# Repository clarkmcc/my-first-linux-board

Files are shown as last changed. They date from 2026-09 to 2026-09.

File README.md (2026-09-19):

# my-first-linux-board

`my-first-linux-board` is a small F1C200S Linux board built around removable microSD storage, USB-C power and USB device data, a 3.3 V UART console, and power/status LEDs. This repository contains the exact KiCad design used for the assembled board, the working Buildroot firmware source, the final JLCPCB fabrication package, and purchasing files.

The assembled board boots U-Boot 2026.01 and Linux 6.19.14 into a minimal BusyBox system. Both boot stages identify it as `Clark's Board`.

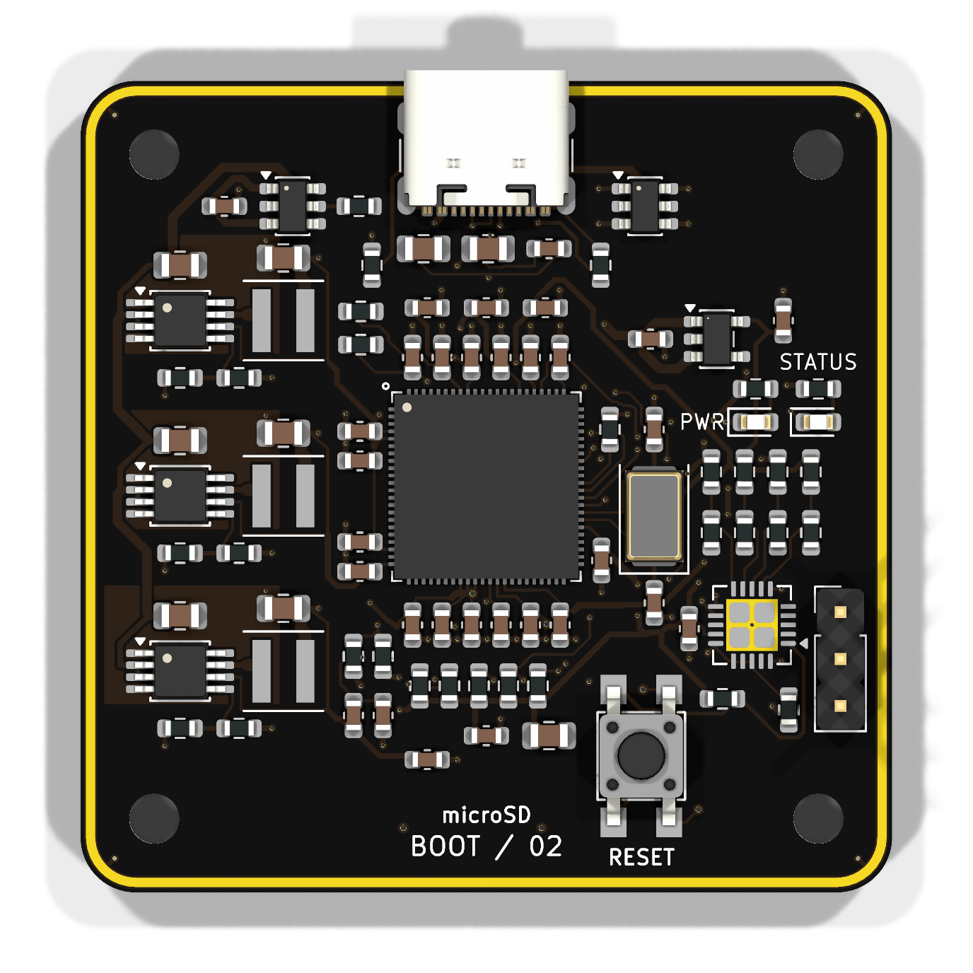
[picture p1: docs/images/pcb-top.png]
Top PCB render


## Hardware

| Item | Final design |
|---|---|
| Processor | Allwinner F1C200S with 64 MiB integrated DDR1 |
| Board | 44 × 44 mm, four copper layers, R3 rounded corners |
| Power input | USB-C, 5 V, TPS2553 current-limited input switch |
| Rails | Three TPS62160 bucks for core, DDR, and I/O; TLV75528 analog LDO |
| Storage | Bottom-mounted microSD socket |
| Console | UART0 on a three-pin 3.3 V header: GND, TX, RX |
| USB | Native USB peripheral connection over USB-C |
| Indicators | Fixed power LED and PC0-controlled active-low status LED |
| Assembly | Components on top except the bottom microSD socket; through-hole UART header |
| Finish used | Black solder mask, white silkscreen, ENIG |

Open [hardware/boot-console.kicad_pro](hardware/boot-console.kicad_pro) in KiCad 10. The [BOM](hardware/docs/BOM.md), [pinout](hardware/docs/PINOUT.md), and [component-purpose guide](hardware/docs/COMPONENT-PURPOSE.md) describe the final circuit.

The [schematic PDF](docs/schematic.pdf) and [combined copper-layer image](docs/images/all-copper-layers.png) are convenient read-only views of the same final design.

## Firmware

The firmware directory is a Buildroot external tree. On macOS or another Docker host:

```sh
cd firmware
./build-container.sh
```

The complete card image is generated at:

```text
firmware/output/images/sdcard.img
```

The proven board configuration uses one-bit microSD transfers at 12.5 MHz. The physical board has four data traces, but Linux produced data errors in four-bit/25 MHz mode on the first assembly; the conservative setting boots reliably and is therefore the canonical configuration.

UART0 is 115200 baud, 8 data bits, no parity, and one stop bit. Linux also
creates a composite USB device with a CDC ACM console and a CDC ECM Ethernet
link. The board is `192.168.7.2/24`; its small DHCP server assigns the attached
host an address without advertising a default route or DNS server. On macOS,
the gadget can enumerate before Network Settings creates a service. Find the
interface whose MAC address is `02:00:00:00:07:01`, assign the host side
`192.168.7.1` for immediate access, and ask macOS to detect the new hardware:

```sh
iface=$(for interface in $(ifconfig -l); do
  ifconfig "$interface" | grep -q 'ether 02:00:00:00:07:01' && echo "$interface"
done)
sudo ifconfig "$iface" inet 192.168.7.1 netmask 255.255.255.0 up
sudo networksetup -detectnewhardware
```

This address lasts until the interface is removed or reconfigured. After
`networksetup -detectnewhardware` creates the service, give it the persistent
static address used by this direct link. The service on the tested Mac is named
`Clark's Board Console + Ethernet`:

```sh
sudo networksetup -setmanual "Clark's Board Console + Ethernet" \
  192.168.7.1 255.255.255.0 0.0.0.0
```

If macOS uses a different service name, find it with
`networksetup -listallnetworkservices` and substitute that name. DHCP did not
activate this ECM link reliably, so keep the host address static.

Prometheus metrics are the only HTTP resource. Scrape them with:

```sh
curl http://192.168.7.2/cgi-bin/metrics
```

The endpoint uses the Prometheus 0.0.4 text format and reports board identity,
time, CPU, load, memory, VM, pressure, filesystem, microSD, network, socket,
entropy, LED, service, USB gadget, and available thermal, CPU-frequency, and
watchdog data. The root URL and every other HTTP path intentionally return 404.

SSH is available as `root` with a blank password:

```sh
ssh root@192.168.7.2
```

This passwordless access is intended for a directly attached development
cable. The first boot stores a generated SSH host key on the FAT boot partition
so the host fingerprint remains stable while the read-only root stays unchanged.

The status LED appears at:

```text
/sys/class/leds/boot-console:green:status
```

It uses the CPU `activity` trigger by default. Manual control:

```sh
LED=/sys/class/leds/boot-console:green:status
echo none > "$LED/trigger"
echo 1 > "$LED/brightness"
echo 0 > "$LED/brightness"
```

See [firmware/README.md](firmware/README.md) for build details and [firmware/docs/BRINGUP.md](firmware/docs/BRINGUP.md) for bench bring-up.

## Manufacturing and purchasing

- [fabrication/clarks-board-JLCPCB-gerbers.zip](fabrication/clarks-board-JLCPCB-gerbers.zip) is the exact bare-board package used for the final revision.
- [fabrication/assembly/clarks-board-JLCPCB-BOM.csv](fabrication/assembly/clarks-board-JLCPCB-BOM.csv) and [fabrication/assembly/clarks-board-JLCPCB-CPL.csv](fabrication/assembly/clarks-board-JLCPCB-CPL.csv) are formatted for JLCPCB assembly upload.
- [procurement/DigiKey-order.csv](procurement/DigiKey-order.csv) and [procurement/LCSC-order.csv](procurement/LCSC-order.csv) contain the final supplier split used during sourcing.
- [hardware/assembly/ibom.html](hardware/assembly/ibom.html) is an interactive assembly view.

The fabrication package retains the routed board exactly. USB impedance was not matched to a specific JLCPCB controlled-impedance stackup, so select and verify a stackup before changing USB routing or ordering a controlled-impedance revision.

## Validation status

- The assembled board reaches a Linux login prompt over UART.
- The status LED works through the Linux LED subsystem after correcting duplicate PC0 pin ownership.
- KiCad ERC and DRC pass on the final source.
- The saved fabrication package matches the final KiCad source.
- Power/reset calculations and saved transient results are documented in [docs/POWER-VERIFICATION.md](docs/POWER-VERIFICATION.md).

Generated firmware images, Buildroot downloads, compiler output, KiCad backups, caches, and editor state are intentionally excluded from Git.

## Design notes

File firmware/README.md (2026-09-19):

# Boot Console firmware

This Buildroot external tree creates a minimal microSD image for the F1C200s
Boot Console. The first milestone boots U-Boot SPL, U-Boot, Linux, and BusyBox
with a login on UART0 PE0/PE1 at 115200 8N1. UART is the primary bring-up and
recovery console because it is available before Linux. Linux additionally
offers a CDC ACM login and CDC ECM Ethernet on the native USB peripheral port.
The board exposes Prometheus metrics at `/cgi-bin/metrics` and Dropbear SSH at
`192.168.7.2`. No other HTTP resource is served.

The network stack is limited to the directly attached USB link. A tiny DHCP
server gives the host a `192.168.7.x` address without a gateway or DNS option,
so the link does not replace the host's normal Internet route. The image has no
package manager, Python, or C++ runtime. The fixed hardware rails need no PMIC
driver. The root ext4 filesystem
mounts read-only; `/run`, `/tmp`, and `/var` are tmpfs. Development images permit local
passwordless root login on the physical UART, USB gadget console, and SSH.
Treat this as a physically attached development image, not a production security
configuration. A generated Dropbear host key persists under `/boot/dropbear` on
the FAT partition; other runtime state remains in RAM.
The broad upstream `multi_v5_defconfig` retains I2C core and some unrelated
modules; no I2C controller is enabled in this board's device tree. Wi-Fi, SPI,
and sound support resolve disabled.

For a ground-up explanation of how the hardware, boot stages, kernel, device
tree, and root filesystem fit together, see
[Embedded Linux from first principles](docs/EMBEDDED-LINUX-FROM-FIRST-PRINCIPLES.md).

## Build

On Linux with the Buildroot host prerequisites installed:

```sh
make
```

On macOS or another Docker host:

```sh
./build-container.sh
```

The container wrapper keeps sources and intermediate output in the named Linux
volume `boot-console-buildroot-2026-02-2`. This is required on case-insensitive
macOS filesystems because the Linux source contains case-distinct names. It
copies the final images and resolved configurations into `output/`.

Both commands run from this directory. The pinned configuration uses eight
jobs within each package while Buildroot keeps package orchestration serial.
`make configure` only resolves the Buildroot configuration. Downloads, unpacked
source, and generated output stay in ignored `dl/`, `build/`, and `output/`
directories. See [SOURCES.md](SOURCES.md) for pins and source provenance.

After changing the DTS, kernel or U-Boot fragments, Linux patches, or boot
script, run `make rebuild-board`; the Docker equivalent is
`./build-container.sh rebuild-board`. This rebuilds board outputs while keeping
the expensive cross toolchain. After changing `configs/boot_console_defconfig`,
run `make clean` and then `make` so every resolved setting is rebuilt.

The useful generated files are:

- `output/.config`: resolved Buildroot configuration
- `output/build.log`: console log from the latest container build
- `output/build/linux-6.19.14/.config`: resolved Linux configuration
- `output/build/uboot-2026.01/.config`: resolved U-Boot configuration
- `output/images/linux.dtb`: board device tree
- `output/images/u-boot-sunxi-with-spl.bin`: SPL plus U-Boot
- `output/images/rootfs.ext4`: read-only-at-runtime BusyBox root filesystem
- `output/images/sdcard.img`: complete microSD image

## Image and boot flow

The Allwinner ROM finds SPL at byte 8 KiB. The raw SPL/U-Boot area ends at
1 MiB, followed by a 16 MiB FAT boot partition and then the ext4 root
partition. U-Boot loads `zImage` at `0x80008000` and `linux.dtb` at
`0x82000000`. Kernel arguments select `/dev/mmcblk0p2`, ext4, `rootwait`, and
read-only mounting. SDC0 uses the proven one-bit, 12.5 MHz configuration and
does not require a card-detect switch. Both U-Boot and Linux identify the
hardware as `Clark's Board`.

Do not write `sdcard.img` to removable media until its target device has been
checked separately. The build does not flash hardware.

## Hardware validation boundary

Configuration and compilation can prove that the selected upstream software
builds, but they cannot prove SDRAM timing, UART levels, SD signal integrity,
USB enumeration, or LED polarity. Those checks require an assembled board.

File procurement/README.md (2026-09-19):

# Purchasing files

The canonical purchasing BOM covers 89 fitted electronic components. The four mounting holes are fabricated features and are not purchase lines.

- `bom.csv` is the complete grouped purchasing BOM.
- `component-purpose.csv` explains why each group exists.
- `DigiKey-order.csv` and `LCSC-order.csv` are the final supplier split prepared from the available stock snapshots.

Availability and price evidence was checked on September 7, 2026 and is not a reservation. Confirm stock, packaging, quantities, and current pricing before ordering. Preserve the exact precision and temperature-coefficient grades for the regulator feedback and reset-supervisor resistor networks.

The F1C200S was allocated to LCSC. The TPS62160 buck regulators, TPS2553 input switch, Coilcraft inductors, and several passives were also allocated between LCSC and DigiKey according to the quoted in-stock exact manufacturer parts. The JLCPCB assembly upload files are under `fabrication/assembly/`; supplier inventory does not imply JLCPCB assembly inventory.

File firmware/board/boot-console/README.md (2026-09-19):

# Boot Console board support

This directory contains the Linux board description, kernel fragment, and
read-only-root-compatible userspace overlay for the F1C200s Boot Console.
`/run`, `/tmp`, `/var`, and `/dev/shm` are RAM-backed; login accounting files
are created under volatile `/var` before either getty starts.

## Hardware contract

- 64 MiB SDRAM starts at `0x80000000`.
- microSD uses SDC0 with PF0 clock, PF1 command, and PF2 data in one-bit mode.
  Card detect is not connected, so `broken-cd` is required. The final image
  limits the bus to the hardware-proven 12.5 MHz.
- UART0 is PE0 RX and PE1 TX at 115200 8N1. It is the bootloader and Linux
  console.
- Native USB D+/D- operates only as a peripheral. There is no ID-detect GPIO or
  software-controlled VBUS source on this board.
- The green status LED is wired from +3V3 through the LED to PC0, so it is
  active low. Linux starts it with the CPU activity trigger.
- The +3V3 voltage-class rail is a fixed, hardware-managed supply with the
  revised nominal target of 3.404878 V. Linux does not sequence a PMIC.

All other exposed SoC peripherals remain disabled by the SoC `.dtsi`. SPI0 is
also unavailable because PC0 is reserved for the status LED.

## USB console and Ethernet

The UART login is always present on `/dev/ttyS0`. A configfs composite gadget
adds CDC ACM serial as `/dev/ttyGS0` and CDC ECM Ethernet as `usb0`; the getty
wrapper waits for a late gadget TTY. Gadget setup also waits asynchronously for
the UDC and network interface, so it never blocks the UART login or startup.

The board uses `192.168.7.2/24`. BusyBox `udhcpd` leases
`192.168.7.10`–`192.168.7.20` to the attached host and deliberately sends no
router or DNS option. Dropbear SSH and a BusyBox HTTP Prometheus endpoint listen
on the link. `/cgi-bin/metrics` is the only HTTP resource; `/` and every other
path intentionally return 404. The endpoint emits Prometheus 0.0.4 text for
board identity, time, CPU, load, memory, VM, pressure, filesystems, microSD,
networking, sockets, entropy, LED state, services, USB gadget state, and any
available thermal, CPU-frequency, and watchdog data:

```sh
curl http://192.168.7.2/cgi-bin/metrics
```

macOS may enumerate ECM before Network Settings creates a service. Find the
interface whose `ether` address is `02:00:00:00:07:01`, assign the host side
`192.168.7.1` for immediate access, and ask macOS to detect the new hardware:

```sh
iface=$(for interface in $(ifconfig -l); do
  ifconfig "$interface" | grep -q 'ether 02:00:00:00:07:01' && echo "$interface"
done)
sudo ifconfig "$iface" inet 192.168.7.1 netmask 255.255.255.0 up
sudo networksetup -detectnewhardware
```

The direct address lasts until the interface is removed or reconfigured. After
`networksetup -detectnewhardware` creates the service, give it the persistent
static address used by this direct link. The service on the tested Mac is named
`Clark's Board Console + Ethernet`:

```sh
sudo networksetup -setmanual "Clark's Board Console + Ethernet" \
  192.168.7.1 255.255.255.0 0.0.0.0
```

If macOS uses a different service name, find it with
`networksetup -listallnetworkservices` and substitute that name. DHCP did not
activate this ECM link reliably, so keep the host address static.

The Buildroot configuration enables root login with an empty password. Pinned
Buildroot 2026.02.2 intentionally has no `/etc/securetty`, so BusyBox does not
restrict root login to a hard-coded terminal list; `ttyS0`, `ttyGS0`, and
Dropbear reach the same passwordless root login. This is for a direct development
cable only. The first boot generates an Ed25519 host key on the FAT boot
partition at `/boot/dropbear`, preserving the SSH identity without writing the
read-only ext4 root. If `/boot` cannot mount, the startup script falls back to an
ephemeral key under `/run` and reports that condition on the console.

The configfs gadget uses Linux Foundation development identity `1d6b:0104`.
This does not allocate a production USB identity to Clark's Board. Its configfs
configuration explicitly reports bus power and 500 mA maximum configured load;
this declaration neither enforces nor measures current. R29 sets the separate
TPS2553 limit to about 520 mA typical with a documented 475–565 mA range.

## Status LED control

The LED class device is normally
`/sys/class/leds/boot-console:green:status`. Disable CPU activity and set the
LED manually with:

```sh
echo none > /sys/class/leds/boot-console:green:status/trigger
echo 1 > /sys/class/leds/boot-console:green:status/brightness
echo 0 > /sys/class/leds/boot-console:green:status/brightness
```

The LED driver accounts for its active-low wiring, so brightness `1` means lit.

## Bootloader requirement

Upstream U-Boot's sunxi SPL code configures PE0 and PE1 as UART0 when
`CONFIG_MACH_SUNIV=y` and `CONFIG_CONS_INDEX=1`. Keep those settings in the
board configuration. Selecting another console index loses the required UART
output before the device tree is available.

## Limits of validation

The board data comes from `hardware/docs/PINOUT.md`. A successful build
can validate preprocessing, device-tree syntax, and resolved kernel options.
UART signaling, SDRAM stability, SD timing, USB enumeration, and LED polarity
still require tests on assembled hardware.

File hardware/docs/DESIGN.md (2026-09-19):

# Final hardware design

The board is a minimal F1C200S Linux computer intended to boot from microSD and expose a console through UART or USB. It uses a four-layer 44 × 44 mm PCB with rounded corners, four M2.5 mounting holes, and an inset exposed-copper border finished with ENIG.

## Power tree

USB-C VBUS enters through a TPS2553 current-limited switch. Three TPS62160 converters generate the processor core, DDR, and I/O rails; a TLV75528 generates the analog rail. A TPS386000 holds the processor in reset until all four rails are valid. The voltage-class net names remain `+1V1`, `+2V5`, and `+3V3`; their precise nominal targets are 1.131707 V, 2.556098 V, and 3.404878 V.

## Boot and interfaces

The 24 MHz crystal provides the processor reference clock. The boot ROM reads SPL from microSD, SPL initializes the integrated DDR, U-Boot loads the kernel and device tree, and Linux mounts the second microSD partition as its root filesystem.

The UART header is ordered GND, TX, RX and uses 3.3 V logic. USB-C carries both 5 V input and the native USB peripheral data pair. The status LED is connected from 3.3 V through R31 and D3 to PC0, so software turns it on by driving PC0 low.

## Assembly

All SMD parts except the microSD socket are on the top side to support hot-plate assembly. The UART header is through-hole. The top side should be reflowed first; solder the bottom microSD socket and UART header afterward. USB-C retention stakes may also benefit from hand soldering.

The component choices and their first-principles purposes are listed in [COMPONENT-PURPOSE.md](COMPONENT-PURPOSE.md).

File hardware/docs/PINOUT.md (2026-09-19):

# Pinout

Final pin and net assignments for the fabricated board. Empty net cells are intentional unused pins. The UART header order is GND, TX, RX and uses 3.3 V logic.

| Refdes | Pin | Name | Net | Notes |
|---|---|---|---|---|
| U2 | 1 | PGND | GND | |
| U2 | 2 | VIN | +5V_SYS | |
| U2 | 3 | EN | +5V_SYS | |
| U2 | 4 | AGND | GND | |
| U2 | 5 | FB | FB_1 | |
| U2 | 6 | VOS | +1V1 | |
| U2 | 7 | SW | SW_1 | |
| U2 | 8 | PG |  | |
| U3 | 1 | PGND | GND | |
| U3 | 2 | VIN | +5V_SYS | |
| U3 | 3 | EN | +5V_SYS | |
| U3 | 4 | AGND | GND | |
| U3 | 5 | FB | FB_2 | |
| U3 | 6 | VOS | +2V5 | |
| U3 | 7 | SW | SW_2 | |
| U3 | 8 | PG |  | |
| U4 | 1 | PGND | GND | |
| U4 | 2 | VIN | +5V_SYS | |
| U4 | 3 | EN | +5V_SYS | |
| U4 | 4 | AGND | GND | |
| U4 | 5 | FB | FB_3 | |
| U4 | 6 | VOS | +3V3 | |
| U4 | 7 | SW | SW_3 | |
| U4 | 8 | PG |  | |
| U5 | 1 | IN | VBUS | |
| U5 | 3 | EN | VBUS | |
| U5 | 6 | OUT | +5V_SYS | |
| U5 | 5 | ILIM | ILIM | |
| U5 | 4 | FAULT_N |  | |
| U5 | 2 | GND | GND | |
| U6 | 1 | IN | +5V_SYS | |
| U6 | 2 | GND | GND | |
| U6 | 3 | EN | +5V_SYS | |
| U6 | 4 | NC |  | |
| U6 | 5 | OUT | +2V8_A | |
| U1 | 22 | VDD_CORE | +1V1 | |
| U1 | 35 | VDD_CORE | +1V1 | |
| U1 | 71 | VDD_CORE | +1V1 | |
| U1 | 30 | VCC_DRAM | +2V5 | |
| U1 | 31 | VCC_DRAM | +2V5 | |
| U1 | 32 | VCC_DRAM | +2V5 | |
| U1 | 34 | VCC_DRAM | +2V5 | |
| U1 | 36 | VCC_DRAM | +2V5 | |
| U1 | 5 | VCC_IO | +3V3 | |
| U1 | 20 | VCC_IO | +3V3 | |
| U1 | 50 | VCC_IO | +3V3 | |
| U1 | 67 | UVCC | +3V3 | |
| U1 | 4 | HPVCC | +3V3 | |
| U1 | 73 | TV_VCC | +3V3 | |
| U1 | 80 | AVCC | +2V8_A | |
| U1 | 33 | SVREF | DDR_VREF | |
| U1 | 2 | HPCOMFB |  | |
| U1 | 3 | HPCOM |  | |
| U1 | 75 | TV_VRN | TV_VRN | |
| U1 | 76 | TV_VRP | TV_VRP | |
| U1 | 81 | VRA1 | VRA1 | |
| U1 | 83 | VRA2 | VRA2 | |
| U1 | 74 | TVGND | GND | |
| U1 | 82 | AGND | GND | |
| U1 | 89 | EPAD | GND | |
| U1 | 51 | HOSCI | XTAL_IN | |
| U1 | 52 | HOSCO | XTAL_OUT | |
| U1 | 70 | RESET_N | RESET_N | |
| U1 | 53 | PF5 / SD_D2 | SD_D2 | |
| U1 | 54 | PF4 / SD_D3 | SD_D3 | |
| U1 | 55 | PF3 / SD_CMD | SD_CMD | |
| U1 | 56 | PF2 / SD_CLK | SD_CLK_SRC | |
| U1 | 57 | PF1 / SD_D0 | SD_D0 | |
| U1 | 58 | PF0 / SD_D1 | SD_D1 | |
| U1 | 48 | PE1 / UART0_TX | UART_TX | |
| U1 | 49 | PE0 / UART0_RX | UART_RX | |
| U1 | 68 | USB_DM | USB_D- | |
| U1 | 69 | USB_DP | USB_D+ | |
| U1 | 1 | HPL |  | |
| U1 | 88 | HPR |  | |
| U1 | 72 | TVOUT |  | |
| U1 | 77 | TVIN1 |  | |
| U1 | 78 | TVIN0 |  | |
| U1 | 79 | LRADC0 |  | |
| U1 | 84 | FMINL |  | |
| U1 | 85 | FMINR |  | |
| U1 | 86 | LINL |  | |
| U1 | 87 | MICIN |  | |
| U1 | 6 | PD0 |  | |
| U1 | 7 | PD1 |  | |
| U1 | 8 | PD2 |  | |
| U1 | 9 | PD3 |  | |
| U1 | 10 | PD4 |  | |
| U1 | 11 | PD5 |  | |
| U1 | 12 | PD6 |  | |
| U1 | 13 | PD7 |  | |
| U1 | 14 | PD8 |  | |
| U1 | 15 | PD9 |  | |
| U1 | 16 | PD10 |  | |
| U1 | 17 | PD11 |  | |
| U1 | 18 | PD12 |  | |
| U1 | 19 | PD13 |  | |
| U1 | 21 | PD14 |  | |
| U1 | 23 | PD15 |  | |
| U1 | 24 | PD16 |  | |
| U1 | 25 | PD17 |  | |
| U1 | 26 | PD18 |  | |
| U1 | 27 | PD19 |  | |
| U1 | 28 | PD20 |  | |
| U1 | 29 | PD21 |  | |
| U1 | 37 | PE12 |  | |
| U1 | 38 | PE11 |  | |
| U1 | 39 | PE10 |  | |
| U1 | 40 | PE9 |  | |
| U1 | 41 | PE8 |  | |
| U1 | 42 | PE7 |  | |
| U1 | 43 | PE6 |  | |
| U1 | 44 | PE5 |  | |
| U1 | 45 | PE4 |  | |
| U1 | 46 | PE3 |  | |
| U1 | 47 | PE2 |  | |
| U1 | 59 | PC0 | STATUS_LED_N | |
| U1 | 60 | PC1 |  | |
| U1 | 61 | PC2 |  | |
| U1 | 62 | PC3 |  | |
| U1 | 63 | PA3 |  | |
| U1 | 64 | PA2 |  | |
| U1 | 65 | PA1 |  | |
| U1 | 66 | PA0 |  | |
| U7 | 14 | VDD | +3V3 | |
| U7 | 10 | SENSE1 | SENSE_3V3 | |
| U7 | 9 | SENSE2 | SENSE_2V8 | |
| U7 | 8 | SENSE3 | SENSE_2V5 | |
| U7 | 7 | SENSE4L | SENSE_1V1 | |
| U7 | 6 | SENSE4H | GND | |
| U7 | 1 | MR_N | RESET_BUTTON | |
| U7 | 12 | GND | GND | |
| U7 | 11 | NC_GND | GND | |
| U7 | 21 | EPAD | GND | |
| U7 | 15 | RESET1_N | RESET_N | |
| U7 | 16 | RESET2_N | RESET_N | |
| U7 | 17 | RESET3_N | RESET_N | |
| U7 | 18 | RESET4_N | RESET_N | |
| U7 | 5 | CT1 |  | |
| U7 | 4 | CT2 |  | |
| U7 | 3 | CT3 |  | |
| U7 | 2 | CT4 |  | |
| U7 | 13 | VREF |  | |
| U7 | 19 | WDO_N |  | |
| U7 | 20 | WDI | GND | |

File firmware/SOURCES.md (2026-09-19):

# Pinned sources

The build downloads the official Buildroot 2026.02.2 release archive:

- URL: `https://buildroot.org/downloads/buildroot-2026.02.2.tar.xz`
- SHA-256: `a833429929aefd4175b0651b2b356b761960cd46d36df6a0049d1f117e3ac8a6`

That Buildroot release resolves Linux 6.19.14 and U-Boot 2026.01. The firmware
started from the upstream Lichee Pi Nano boot flow and keeps its compatible
hardware initialization while supplying this board's own device tree and
model name. The target includes only the IPv4 support, Dropbear server, BusyBox
HTTPD, and BusyBox DHCP server needed for its direct USB Ethernet link. It omits
Python, C++, Wi-Fi, WireGuard, NFS, and swap features.

The external hash file verifies the Linux archive against kernel.org's signed
checksum manifest:

- Linux 6.19.14 SHA-256: `cde8bf6739be4a0777fedbbba5330b8188c55680c45a922a4dfa289cbec6f185`
- U-Boot 2026.01 SHA-256 (verified by Buildroot's bundled hash): `b60d5865cefdbc75da8da4156c56c458e00de75a49b80c1a2e58a96e30ad0d54`

Primary references:

- Buildroot manual: `https://buildroot.org/downloads/manual/manual.html`
- Buildroot release announcement: `https://lists.buildroot.org/pipermail/buildroot/2026-May/802637.html`
- U-Boot source: `https://source.denx.de/u-boot/u-boot/-/tree/v2026.01`
- Linux stable source: `https://git.kernel.org/pub/scm/linux/kernel/git/stable/linux.git/tag/?h=v6.19.14`

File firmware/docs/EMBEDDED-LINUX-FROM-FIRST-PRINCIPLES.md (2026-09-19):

# Embedded Linux from first principles, on the F1C200s Boot Console

An embedded Linux computer is a chain of programs that progressively create the conditions needed by the next program. The Boot Console makes that chain unusually visible: power and a clock let an Allwinner F1C200s execute its immutable ROM; the ROM reads a small loader from microSD; that loader configures the integrated DDR; U-Boot loads Linux and a hardware description; Linux starts one userspace process; that process eventually presents a shell. Nothing in this chain appears by magic, and a failure at any link prevents every later link from existing.

This guide explains that chain using the firmware in this repository. It assumes you can read C and use a shell, but does not assume electronics or kernel experience. It describes an image that has built and passed static validation. No assembled board has booted it yet, so expected observations below are predictions, not reported results. Follow [BRINGUP.md](BRINGUP.md) for the controlled hardware procedure; this guide contains no flashing instructions.

## Before the first instruction

A processor cannot execute code merely because 5 V reaches the board. Transistors need valid supply voltages, sequential logic needs a clock, and the system must remain in reset while those conditions settle.

The Boot Console derives several rails. The F1C200s core uses `+1V1` (nominally 1.1317 V), its integrated DDR uses `+2V5` (2.5561 V) and `DDR_VREF` (1.2780 V), its digital I/O uses the voltage-class net called `+3V3` whose actual nominal value is 3.404878 V, and analog circuitry uses `+2V8_A` (2.800 V). A supervisor watches the rails and holds package pin 70, `RESET_N`, low. Its timing pins are open, selecting a 14–24 ms release delay. A 24 MHz crystal at pins 51 and 52 supplies the reference from which clock circuitry and PLLs derive operating clocks.

These facts explain why “no serial output” is not initially a software diagnosis. Before the UART can transmit one bit, the rails must be in tolerance, the oscillator must run, reset must release, the CPU must fetch an instruction, and the pin multiplexer must connect UART0 to package pins 48 and 49. [The board pinout](../../hardware/docs/PINOUT.md) is the authority for package pin, signal, and schematic-net correspondence.

```mermaid
flowchart LR
    P[5 V input] --> R[regulated rails]
    R --> S[supervisor releases RESET_N]
    X[24 MHz crystal] --> C[clock circuitry]
    S --> ROM[Boot ROM executes]
    C --> ROM
    ROM --> SPL[SPL in on-chip SRAM]
    SPL --> DDR[configure integrated DDR]
    DDR --> UB[full U-Boot]
    UB --> K[Linux kernel]
    K --> I[PID 1: BusyBox init]
    I --> G[getty and login]
    G --> SH[shell]
```

“Integrated DDR” means the DDR memory and controller are part of the F1C200s package, not that the memory is ready at reset. The controller still needs timings and calibration. The ROM therefore cannot begin by copying a large program into DDR. It first uses storage available before DDR initialization to run U-Boot's Secondary Program Loader, or SPL. SPL is small because its job is narrow: establish enough clocks, pins, and DRAM state to load the larger U-Boot proper.

## What the processor actually does

The ARM926EJ-S core repeatedly fetches an instruction from an address, decodes it, and changes architectural state. That state includes general-purpose registers, a program counter, status registers, and system-control registers. An addition changes a register. A load copies bytes from an addressed location into a register. A store sends bytes from a register to an addressed location. The manufacturer's [F1C200s datasheet](https://linux-sunxi.org/images/5/5e/Allwinner_F1C200s_Datasheet_V1.1.pdf) identifies the ARM9 core, on-chip ROM loader, SIP DDR, USB OTG, UARTs, and package pins used here.

Some addresses refer to RAM. Others refer to peripheral registers. With memory-mapped I/O, storing a bit pattern to a GPIO configuration register changes multiplexers and output drivers rather than preserving ordinary data. Reading a UART status address returns hardware state. A driver is, at bottom, code that performs these reads and writes in the order required by the peripheral, while presenting a stable interface to the rest of the kernel.

Polling a status register wastes CPU time, so peripherals can raise interrupts. An interrupt controller records a request and directs the CPU to an exception handler. The handler acknowledges the device, moves or accounts for data, and wakes code waiting for the event. The UART receive path therefore spans voltage transitions at pin 49, a UART receive register, an interrupt, the serial driver, the kernel TTY layer, and finally bytes returned by `read()` in a process.

Pins are another layer of indirection. F1C200s package pin 59 can act as `PC0`, and this board wires it to `STATUS_LED_N`. The device tree selects its GPIO function. Linux's LED driver owns that GPIO and exposes `/sys/class/leds/boot-console:green:status/`. Calling it “PC0” identifies the SoC port and bit; “pin 59” identifies the physical package ball or lead; `STATUS_LED_N` identifies the schematic net. They are related, but not interchangeable. This guide does not assign a global Linux GPIO number because modern userspace should use the device's subsystem interface and the number is not a physical-pin identity.

The ARM926 has a memory-management unit (MMU), documented in the [ARM926EJ-S technical reference manual](https://documentation-service.arm.com/static/5e8e3d1088295d1e18d3a9b2). Linux programs normally use virtual addresses; page tables translate them to physical addresses and attach permissions. The kernel can isolate processes, map files, and make each process appear to have its own address space. This differs from a common Cortex-M microcontroller setup, where one firmware image executes directly from flash and uses physical SRAM without a process-oriented virtual-memory system. NoMMU Linux exists, so “Linux always requires an MMU” is false. This project runs ordinary MMU-enabled Linux, and that changes both its capabilities and its startup cost.

## Storage is not working memory

The microSD card holds persistent blocks. DDR holds live instructions, stacks, page tables, kernel data, processes, and filesystem cache. The complete `sdcard.img` is 84,934,656 bytes (81 MiB), larger than the board's 64 MiB of RAM. That is fine: the machine never copies the whole disk image into RAM. It reads the bootloader, kernel, DTB, and later individual filesystem blocks as needed.

| Space | Range or location | Size | Purpose |
| --- | --- | ---: | --- |
| SD raw boot area | `[8 KiB, 1 MiB)` | 1016 KiB | SPL plus U-Boot; current binary is 405,376 bytes |
| SD partition 1 | starts at byte 1 MiB | 16 MiB | FAT boot filesystem containing `boot.scr`, `zImage`, and `linux.dtb` |
| SD partition 2 | starts at byte 17 MiB | 64 MiB | ext4 root filesystem |
| Physical DDR | `0x80000000`–`0x83ffffff` | 64 MiB | runtime memory |
| Compressed kernel input | `0x80008000`–`0x804d48c8` (end exclusive) | 5,032,136 bytes | `zImage` as loaded by U-Boot |
| Raw uncompressed `Image` file | build artifact, not loaded by this boot script | 12,159,696 bytes | file bytes before zImage wrapping/compression |
| Kernel runtime span | `0x80008000`–`0x80c40724` (end exclusive) | 12,814,116 bytes | linked text, data, and BSS residency used by validation |
| Device tree | `0x82000000` | 7,428 bytes | hardware description passed to Linux |

The SD address “8 KiB” is a byte offset in a block device. It is not a RAM address. The Boot ROM knows a media-specific convention for finding the SPL there. Once software copies bytes into DDR, hexadecimal CPU addresses describe a different address space.

The kernel example catches a real class of bring-up bug. An earlier boot script placed the DTB at `0x80c00000`. The decompressed kernel's validated runtime range ended at `0x80c40724`, so Linux could overwrite part of the DTB while expanding and zeroing its BSS. The compressed `zImage` file size alone did not reveal the problem: BSS occupies memory at runtime even though it is represented compactly in the file. Moving the DTB to `0x82000000` leaves room within the 64 MiB DDR range.

```mermaid
flowchart TB
    subgraph SD[microSD: persistent blocks]
      RAW[8 KiB: SPL + U-Boot\n405,376 bytes]
      FAT[1 MiB: FAT partition\n16 MiB]
      EXT[17 MiB: ext4 root\n64 MiB]
    end
    subgraph RAM[DDR: 0x80000000–0x83ffffff]
      Z[zImage input\n0x80008000]
      KR[kernel runtime span\nincludes BSS]
      DT[DTB\n0x82000000]
      FREE[remaining RAM: allocators, pages, cache]
    end
    RAW -->|SPL loads U-Boot proper| RAM
    FAT -->|U-Boot load| Z
    FAT -->|U-Boot load| DT
    EXT -->|kernel reads blocks on demand| FREE
    Z -->|self-decompress| KR
```

The table is a physical boot-time view. After the MMU is enabled, kernel and process virtual addresses add another map. A process's address `0x10000` does not imply physical DDR address `0x10000`; page tables decide the translation.

## The bootstrap, one handoff at a time

The immutable Boot ROM is the first software. It runs because reset gives the CPU a defined starting address. It configures only enough hardware to locate a supported boot source, recognizes the Allwinner boot header at the conventional 8 KiB SD offset, and loads SPL into memory usable before DDR. U-Boot's [Allwinner platform documentation](https://docs.u-boot.org/en/v2026.01/board/allwinner/sunxi.html) describes this media convention, while its [SPL overview](https://docs.u-boot.org/en/v2026.01/usage/spl_boot.html) explains the general two-stage loader design.

SPL initializes DDR and loads U-Boot proper from its raw-media location. The combined 405,376-byte file is a packaging unit; the ROM does not copy that entire file into pre-DDR memory. U-Boot is a bootloader and a diagnostic environment, not a small Linux. It has its own drivers, commands, environment, memory allocator, and device-tree handling. A working U-Boot SD command proves U-Boot's SD path; it does not prove the Linux MMC driver works.

U-Boot's distro scan finds and sources `/boot.scr` at the FAT partition root. That generated script comes from the project's [boot command](../board/boot-console/boot.cmd) and says exactly what happens next:

```text
load mmc 0:1 0x82000000 linux.dtb
load mmc 0:1 0x80008000 zImage
bootz 0x80008000 - 0x82000000
```

`mmc 0:1` means MMC device zero, partition one. `bootz` starts an ARM Linux zImage, passes no initramfs (`-`), and supplies the DTB address. The associated command line selects `ttyS0` at 115200 baud, requests early console support, waits for the root device, mounts `/dev/mmcblk0p2` as ext4 read-only, and asks the kernel to reboot five seconds after panic.

The compressed kernel first expands itself, establishes the architecture, enables memory management, initializes interrupt and timer machinery, and probes built-in drivers. The MMC host and ext4 drivers must be built into the kernel because modules stored inside ext4 cannot help the kernel mount that same filesystem. It then mounts the root filesystem and executes its configured init program as process ID 1. PID 1 mounts, starts, and supervises userspace services; the kernel treats init exiting as fatal.

Here PID 1 is BusyBox `init`. The [inittab](../board/boot-console/rootfs-overlay/etc/inittab) mounts filesystems, runs startup scripts, and supervises two terminal sessions. `getty` configures `ttyS0`, displays the login prompt, reads a username, and runs `login`; after authentication, `login` starts the user's shell. The USB terminal uses a wrapper because `/dev/ttyGS0` does not exist until the gadget driver creates it. The wrapper waits and rate-limits retries rather than making PID 1 spin through failed children.

## How one source tree becomes four kinds of software

The build computer and target are different machines. A normal macOS or x86 Linux compiler emits instructions for its own CPU and links against its own operating-system ABI. The Boot Console needs 32-bit ARM926 code and a target C library. A cross compiler runs on the host but emits target instructions. Its sysroot contains the headers and libraries that describe the target ABI.

Buildroot coordinates this. Its own manual describes it as a system that builds a cross toolchain, bootloader, kernel, and root filesystem for a target, and explains that `output/host/` contains host tools plus the target sysroot ([Buildroot manual](https://buildroot.org/downloads/manual/manual.html)). “Host” therefore means the computer performing the build; “target” means the F1C200s board. Some generated programs, such as the device-tree compiler and image-building tools, run on the host. U-Boot, Linux, BusyBox, and target libraries run on ARM.

This repository is a Buildroot external tree. [The defconfig](../configs/boot_console_defconfig) records the small set of intentional choices: ARM926T, Linux, U-Boot, ext4, dynamic `/dev`, a read-only root, and board customization paths. Buildroot expands that into full configurations. The external tree keeps board files separate from the downloaded Buildroot source, which is the upstream-recommended role of `BR2_EXTERNAL` ([Buildroot external-tree documentation](https://buildroot.org/downloads/manual/manual.html#outside-br-custom)).

Configuration layers have different jobs:

- Buildroot Kconfig chooses what to build and how to assemble the system.
- U-Boot Kconfig chooses bootloader features and drivers.
- Linux Kconfig decides which drivers and kernel facilities exist in the binary.
- The device tree describes this board's instantiated hardware and wiring.
- Patches change upstream source where configuration alone cannot express the required behavior.
- The rootfs overlay supplies board-specific files such as `fstab`, `inittab`,
  configfs gadget setup, network services, and the USB getty wrapper.

A device-tree node cannot summon a driver that Kconfig omitted. Conversely, compiling a driver does not prove that hardware exists. For platform devices in this path, Linux populates devices from eligible enabled DT nodes and matches their `compatible` strings against drivers; the kernel documentation describes that `platform_device` to `platform_driver` binding process ([Linux device-tree usage model](https://docs.kernel.org/devicetree/usage-model.html)). Other buses can enumerate children through their own subsystems. Pin control is part of the same contract: enabling UART0 is insufficient unless `pinctrl-0` assigns PE0 and PE1 to UART function.

The F1C200s native USB controller is configured in peripheral role by
`dr_mode = "peripheral"`; the board behaves as a USB device connected to a host,
not as a host for keyboards or flash drives. A startup script uses the kernel's
[configfs gadget interface](https://docs.kernel.org/usb/gadget_configfs.html) to
compose two functions: CDC ACM creates `/dev/ttyGS0`, while CDC ECM creates
`usb0` and a class-compliant Ethernet interface on macOS. The configuration
reports itself as bus-powered with a 500 mA maximum load. That descriptor
informs the host; it neither enforces nor measures current. A terminal may
display 115200 for CDC ACM, but that is line-coding metadata rather than the
physical USB signaling rate; 115200 on UART sets actual bit timing on the wire.

UART remains the first console because U-Boot and Linux can drive it with little initialized state. USB enumeration requires clocks, the PHY, controller, gadget framework, descriptors, cable and host cooperation. Power can also be confusing: a USB-C connector may be involved in powering the board while D+/D− still represent a peripheral connection. UART through a 3.3 V adapter, with the adapter's power lead disconnected, gives the cleanest observation of the whole software chain.

## A write to the LED, end to end

The LED is active-low: current flows from `+3V3` through R31 (1 kΩ), through green LED D3, into PC0, and then to ground when PC0 drives low. R31 limits current. Driving PC0 high removes most of the voltage across that series path, so the LED turns off. The suffix `_N` records that electrical polarity. Yet userspace writes `1` to `brightness` to turn it on. That apparent reversal is deliberate abstraction.

The [board DTS](../board/boot-console/linux.dts) declares a `gpio-leds` child,
names PC0 as `GPIO_ACTIVE_LOW`, and selects the `activity` trigger. During
probing, the GPIO LED driver acquires PC0 with its polarity metadata and
registers an LED-class device. The activity trigger varies the LED with CPU
work; sysfs still lets userspace replace that policy. When a shell redirects `1`
to `brightness`, `write()` enters the kernel, sysfs parses the value, the LED
class invokes the GPIO-backed setter, and the GPIO subsystem converts logical on
to electrical low. The pin controller and GPIO driver finally update MMIO
registers so package pin 59 changes voltage.

```mermaid
sequenceDiagram
    participant Sh as shell
    participant V as VFS/sysfs
    participant L as LED class
    participant G as GPIO driver
    participant P as PC0, package pin 59
    Sh->>V: write "1" to brightness
    V->>L: set logical brightness
    L->>G: set active state
    G->>G: apply active-low polarity
    G->>P: drive STATUS_LED_N low
    Note over P: green LED emits light; no software acknowledgement
```

This is representative of Linux driver design. Userspace asks for a meaningful operation through a subsystem interface. Board description supplies wiring. A reusable controller driver performs the register access. That separation is why the same shell operation can work across unrelated GPIO controllers. The sysfs path resembles an ordinary file, but writing it invokes kernel code; it does not replace persistent bytes in ext4.

The status LED differs from a power LED wired directly to a rail. Its default
activity flicker begins when the kernel's LED trigger runs and reflects time the
CPU spends outside idle. It is evidence of processor activity, not proof that
userspace is healthy. Likewise, a successful sysfs `write()` proves that the
kernel accepted the request; only observing D3 proves that the driver, pinmux,
PC0 electrical state, resistor, LED orientation, and board wiring agree.

## Which file do I edit?

Once the layers are clear, most firmware changes have a specific home.

| Desired change | Edit | Reason |
| --- | --- | --- |
| Describe board wiring, enable a peripheral, select pins, or set GPIO polarity | [`board/boot-console/linux.dts`](../board/boot-console/linux.dts) | The DT records instantiated hardware and connections. |
| Compile another Linux driver or kernel facility | [`board/boot-console/linux.fragment`](../board/boot-console/linux.fragment) | Kconfig controls what code exists in the kernel. Enabling only the DT node cannot supply a missing driver. |
| Change login consoles or process supervision | [`rootfs-overlay/etc/inittab`](../board/boot-console/rootfs-overlay/etc/inittab) | BusyBox init reads this at runtime. |
| Add startup files or board-specific userspace configuration | [`rootfs-overlay/`](../board/boot-console/rootfs-overlay/) | Buildroot copies this directory into the generated root filesystem. It is unrelated to Linux OverlayFS. |
| Add target packages or change rootfs/toolchain policy | [`configs/boot_console_defconfig`](../configs/boot_console_defconfig) | Buildroot resolves these selections into the complete system configuration. |
| Change kernel load addresses or boot arguments | [`board/boot-console/boot.cmd`](../board/boot-console/boot.cmd) | U-Boot sources the compiled script before launching Linux. Recheck all runtime memory ranges after moving anything. |
| Change SD partition sizes, order, or raw U-Boot placement | [`board/boot-console/genimage.cfg`](../board/boot-console/genimage.cfg) | Genimage constructs the final block layout. Keep boot arguments and partition numbering consistent. |
| Change a physical rail voltage | board schematic and power components | Resistor dividers and regulators set the rail. The DTS fixed-regulator value describes the measured design contract to software; it cannot command these fixed supplies to change voltage. |

After changing the DTS, fragments, patches, or boot script, use the repository's documented `./build-container.sh rebuild-board` path and then `./build-container.sh validate`. A defconfig change requires the clean-build path described in the [firmware README](../README.md). These checks remain artifact checks until an assembled board supplies electrical and boot evidence.

## The root filesystem is policy as well as files

The root ext4 filesystem contains BusyBox, configuration, libraries, and
device-support files. BusyBox places many commands behind one executable, which
reduces storage and dependency cost. This image adds only enough networking for
the direct ECM link, Dropbear SSH, and BusyBox HTTP/DHCP services; it still has
no Python or package manager. Experiments below use only tools configured for
this target.

The root is mounted read-only to make unexpected writes and corruption less likely. Runtime state still needs writable space, so [fstab](../board/boot-console/rootfs-overlay/etc/fstab) mounts `tmpfs` at `/run`, `/tmp`, and `/var`. tmpfs consumes memory and disappears at reboot. `/proc` is a kernel-generated view of processes and kernel state; `/sys` exports kernel objects and controls; `/dev` contains device nodes backed by devtmpfs. These paths look like ordinary directories, but their contents come from kernel filesystems rather than persistent ext4 blocks.

This policy has operational consequences. A file created in `/tmp` can prove RAM-backed filesystem writes work, but it does not prove the SD root is writable. Logs under `/var` disappear after power loss. Updating a persistent configuration requires producing and deploying a new image or deliberately remounting in a controlled development procedure.

## Debug from the last stage that definitely worked

Boot failures are easier when treated as chain breaks. Do not begin by changing several layers. Preserve the complete UART capture, name the last milestone, and test the immediately adjacent assumptions.

| Last reliable observation | The next boundary to investigate |
| --- | --- |
| No UART characters | input power, rails, oscillator, reset, ROM SD access, UART wiring, baud |
| SPL banner only | integrated DDR controller setup and U-Boot loading |
| U-Boot prompt | FAT files, load results, addresses, DTB, `bootz` arguments |
| Linux banner or early console | kernel setup, DT correctness, selected console |
| root-mount panic | MMC Linux driver, partition 2, ext4 support, `rootwait` |
| init starts but no login | `inittab`, device node, getty, login configuration |
| UART login works; USB does not | USB PHY/controller, gadget driver, descriptors, cable, host enumeration |
| shell works; LED does not | LED DT node, pinmux, polarity, wiring |

The distinction between U-Boot and Linux drivers matters here. Likewise, a compiled DTB proves syntax and internal consistency, but not that the schematic matches it. Voltage and scope measurements resolve electrical claims; UART logs resolve stage transitions; kernel state resolves driver binding.

## Guided experiments

These experiments inspect artifacts or a board already booted according to [BRINGUP.md](BRINGUP.md). `HOST` means the development computer. `U-BOOT` means its interactive prompt. `TARGET` means the BusyBox shell. Expected observations are conceptual and must be replaced by captured evidence during hardware validation.

### 1. Distinguish image size from RAM size

```sh
# HOST — from my-first-linux-board/firmware
stat -f '%N %z bytes' output/images/sdcard.img output/images/zImage output/images/linux.dtb
```

On GNU systems, use `stat -c '%n %s bytes' ...` instead. Expect the disk image to exceed 64 MiB while zImage and DTB are much smaller. The observation is that storage capacity is not allocated wholesale in DDR.

### 2. Inspect the configured U-Boot entry path

```text
# U-BOOT — interrupt autoboot, then inspect without changing state
printenv bootcmd
fatls mmc 0:1
```

The resolved configuration sets `bootcmd` to `run distro_bootcmd`, and includes the FAT command. Expect `fatls` to list `boot.scr`, `zImage`, and `linux.dtb`; real console output remains hardware evidence to collect. Reading those names proves U-Boot's MMC and FAT paths work, but says nothing about Linux's MMC driver. The expected next path is a distro scan finding `/boot.scr` on `mmc 0:1`. The script then sets `bootargs` and immediately runs `bootz`, so inspecting `bootargs` before sourcing it would teach the wrong lesson. Its build-time source of truth is `boot.cmd`.

### 3. Ask Linux what it was told and what it mapped

```sh
# TARGET
cat /proc/cmdline
cat /proc/meminfo
mount
```

Expect the command line to agree with U-Boot, available memory to be less than 64 MiB because the kernel reserves and occupies pages, `/` to be read-only ext4, and `/run`, `/tmp`, and `/var` to be tmpfs. This connects boot arguments to live kernel policy.

### 4. Observe volatile storage safely

```sh
# TARGET
echo volatile > /tmp/storage-test
cat /tmp/storage-test
mount
```

Expect the value to read back while powered. `/tmp` is tmpfs, so this changes RAM only. After a normal reboot, the file should be absent; confirm that only when the board bring-up procedure has reached repeatable power cycling.

### 5. Follow the LED abstraction

```sh
# TARGET
cat /sys/class/leds/boot-console:green:status/trigger
echo none > /sys/class/leds/boot-console:green:status/trigger
echo 1 > /sys/class/leds/boot-console:green:status/brightness
echo 0 > /sys/class/leds/boot-console:green:status/brightness
```

Expect the trigger list to mark `activity` before it is disabled. Logical `1`
should illuminate the active-low LED and `0` should extinguish it. If the files
exist but light does not change, Linux binding succeeded and the investigation
moves toward GPIO state and physical polarity.

### 6. Separate UART from USB readiness

```sh
# TARGET, reached over UART
ls -l /dev/ttyS0 /dev/ttyGS0
ifconfig usb0
dmesg
```

The UART console is usable during early boot, before devtmpfs creates
`/dev/ttyS0`; by the target-shell stage its device node should exist. The gadget
TTY and Ethernet interface may appear later because their driver stack must
initialize. Use the host operating system's normal USB-device inspection after
connecting the native USB port; do not expect `lsusb` on this tiny target. The
conceptual result is two terminal paths with different initialization
dependencies, plus a network link that exists only after the composite gadget
and host ECM driver are ready. From the host,
`http://192.168.7.2/cgi-bin/metrics` exposes Prometheus text metrics and
`ssh root@192.168.7.2` reaches the same target shell. The HTTP root returns 404
because the metrics endpoint is the only served resource.

## What the successful build proves

The pinned project selects Buildroot 2026.02.2, U-Boot 2026.01, and Linux 6.19.14; [SOURCES.md](../SOURCES.md) records archive hashes and provenance. `BR2_REPRODUCIBLE=y` removes or normalizes some sources of build variation, and the external tree captures configuration, patches, boot script, root overlay, and image layout. This makes the build reviewable and repeatable in a bounded environment.

It does not yet demonstrate bit-for-bit equality across two independent clean builds. The Docker base is digest-pinned, but package-manager package versions inside that base are not all locked to immutable artifacts. A successful build and `validate_artifacts.py` prove that selected sources compile and that generated configurations, DTB properties, image partitions, sizes, and memory ranges satisfy encoded invariants. They cannot prove DDR timing, signal integrity, UART voltage levels, USB enumeration, oscillator startup, or LED polarity on copper.

The first board boot will produce the missing evidence. Preserve its power measurements and full UART log, identify the last completed boundary, and change one adjacent assumption at a time. Doing that turns the boot chain from a black box into a sequence of testable contracts.

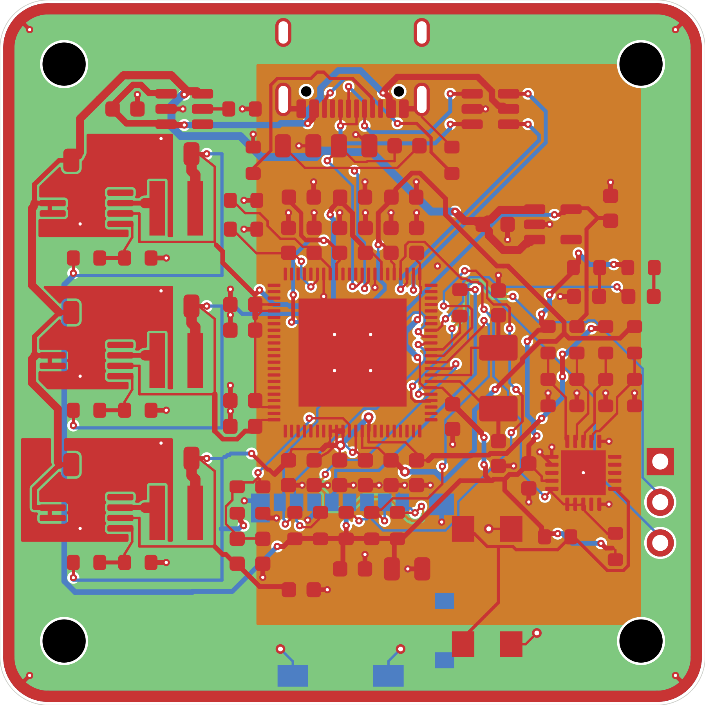
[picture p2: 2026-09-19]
docs/images/all-copper-layers.png

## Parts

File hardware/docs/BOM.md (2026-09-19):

# Bill of materials

This is the final fitted hardware BOM. The three U1 schematic units are one physical F1C200S package. H1-H4 are fabricated mounting holes rather than purchased electronic parts.

The nominal regulated targets are 1.131707 V core, 2.556098 V DDR, 3.404878 V I/O, and 2.8 V analog. Preserve the stated precision and temperature coefficient for the regulator feedback and supervisor resistors.

| Refdes | Value | Footprint | MPN | Rationale |
|---|---|---|---|---|
| C1 | 30p / C0G / 1% | Capacitor_SMD:C_0603_1608Metric | C0603C300F5GACTU | This capacitor supplies the oscillator input side of the crystal load network. Together with C2 and stray capacitance, it sets the load that determines crystal frequency. |
| C2 | 30p / C0G / 1% | Capacitor_SMD:C_0603_1608Metric | C0603C300F5GACTU | This capacitor supplies the oscillator output side of the crystal load network. Its initial 30 pF value needs confirmation with the assembled board, as does C1. |
| C3 | 100n / 100V | Capacitor_SMD:C_0603_1608Metric | GRM188R72A104KA35D | Fast interference can move the DDR comparison voltage and cause bit errors. C3 stores charge at that reference, reducing rapid voltage changes relative to ground. |
| C4 | 100n / 100V | Capacitor_SMD:C_0603_1608Metric | GRM188R72A104KA35D | The DDR reference must track half the memory supply, including fast supply changes. C4 and C3 form a capacitive divider that preserves this relationship. |
| C5 | 100n / 100V | Capacitor_SMD:C_0603_1608Metric | GRM188R72A104KA35D | Trace inductance prevents distant capacitors from supplying very fast current changes. C5 provides local charge for U1 pin 22, serving its processor core domain. |
| C6 | 100n / 100V | Capacitor_SMD:C_0603_1608Metric | GRM188R72A104KA35D | Trace inductance prevents distant capacitors from supplying very fast current changes. C6 provides local charge for U1 pin 35, serving its processor core domain. |
| C7 | 100n / 100V | Capacitor_SMD:C_0603_1608Metric | GRM188R72A104KA35D | Trace inductance prevents distant capacitors from supplying very fast current changes. C7 provides local charge for U1 pin 71, serving its processor core domain. |
| C8 | 4.7u / 10V | Capacitor_SMD:C_0603_1608Metric | GRM188R61A475KE15D | The core supply can briefly demand more current than its regulator delivers through the connecting traces. This local 4.7 µF reservoir reduces voltage droop during those changes. |
| C9 | 100n / 100V | Capacitor_SMD:C_0603_1608Metric | GRM188R72A104KA35D | Trace inductance prevents distant capacitors from supplying very fast current changes. C9 provides local charge for U1 pin 30, serving its DDR memory domain. |
| C10 | 100n / 100V | Capacitor_SMD:C_0603_1608Metric | GRM188R72A104KA35D | Trace inductance prevents distant capacitors from supplying very fast current changes. C10 provides local charge for U1 pin 31, serving its DDR memory domain. |
| C11 | 100n / 100V | Capacitor_SMD:C_0603_1608Metric | GRM188R72A104KA35D | Trace inductance prevents distant capacitors from supplying very fast current changes. C11 provides local charge for U1 pin 32, serving its DDR memory domain. |
| C12 | 100n / 100V | Capacitor_SMD:C_0603_1608Metric | GRM188R72A104KA35D | Trace inductance prevents distant capacitors from supplying very fast current changes. C12 provides local charge for U1 pin 34, serving its DDR memory domain. |
| C13 | 100n / 100V | Capacitor_SMD:C_0603_1608Metric | GRM188R72A104KA35D | Trace inductance prevents distant capacitors from supplying very fast current changes. C13 provides local charge for U1 pin 36, serving its DDR memory domain. |
| C14 | 4.7u / 10V | Capacitor_SMD:C_0603_1608Metric | GRM188R61A475KE15D | The DDR supply can briefly demand more current than its regulator delivers through the connecting traces. This local 4.7 µF reservoir reduces voltage droop during those changes. |
| C15 | 100n / 100V | Capacitor_SMD:C_0603_1608Metric | GRM188R72A104KA35D | Trace inductance prevents distant capacitors from supplying very fast current changes. C15 provides local charge for U1 pin 5, serving its I/O domain. |
| C16 | 100n / 100V | Capacitor_SMD:C_0603_1608Metric | GRM188R72A104KA35D | Trace inductance prevents distant capacitors from supplying very fast current changes. C16 provides local charge for U1 pin 20, serving its I/O domain. |
| C17 | 100n / 100V | Capacitor_SMD:C_0603_1608Metric | GRM188R72A104KA35D | Trace inductance prevents distant capacitors from supplying very fast current changes. C17 provides local charge for U1 pin 50, serving its I/O domain. |
| C18 | 100n / 100V | Capacitor_SMD:C_0603_1608Metric | GRM188R72A104KA35D | Trace inductance prevents distant capacitors from supplying very fast current changes. C18 provides local charge for U1 pin 67, serving its USB domain. |
| C19 | 100n / 100V | Capacitor_SMD:C_0603_1608Metric | GRM188R72A104KA35D | Trace inductance prevents distant capacitors from supplying very fast current changes. C19 provides local charge for U1 pin 4, serving its headphone supply domain. |
| C20 | 100n / 100V | Capacitor_SMD:C_0603_1608Metric | GRM188R72A104KA35D | Trace inductance prevents distant capacitors from supplying very fast current changes. C20 provides local charge for U1 pin 73, serving its TV supply domain. |
| C21 | 4.7u / 10V | Capacitor_SMD:C_0603_1608Metric | GRM188R61A475KE15D | The I/O supply can briefly demand more current than its regulator delivers through the connecting traces. This local 4.7 µF reservoir reduces voltage droop during those changes. |
| C22 | 100n / 100V | Capacitor_SMD:C_0603_1608Metric | GRM188R72A104KA35D | Trace inductance prevents distant capacitors from supplying very fast current changes. C22 provides local charge for U1 pin 80, serving its analog supply domain. |
| C23 | 4.7u / 10V | Capacitor_SMD:C_0603_1608Metric | GRM188R61A475KE15D | The analog supply can briefly demand more current than its regulator delivers through the connecting traces. This local 4.7 µF reservoir reduces voltage droop during those changes. |
| C24 | 1u / 25V | Capacitor_SMD:C_0603_1608Metric | C1608X7R1E105K080AB | This capacitor stores charge on the VRA1 analog reference, reducing rapid voltage changes. It preserves reference-board support for powered silicon, although its necessity with audio disabled is not documented. |
| C25 | 1u / 25V | Capacitor_SMD:C_0603_1608Metric | C1608X7R1E105K080AB | This capacitor stores charge on the VRA2 analog reference, reducing rapid voltage changes. It preserves reference-board support for powered silicon, although its necessity with audio disabled is not documented. |
| C26 | 10u / 10V | Capacitor_SMD:C_0805_2012Metric | C2012X5R1A106M085AB | This capacitor reduces rapid voltage changes on TV_VRN, an internal video reference brought outside U1. It preserves reference-board support, although its necessity with video disabled is not documented. |
| C27 | 10u / 10V | Capacitor_SMD:C_0805_2012Metric | C2012X5R1A106M085AB | This capacitor reduces rapid voltage changes on TV_VRP, an internal video reference brought outside U1. It preserves reference-board support, although its necessity with video disabled is not documented. |
| C28 | 1u / 25V | Capacitor_SMD:C_0603_1608Metric | C1608X7R1E105K080AB | This capacitor resists rapid changes in the voltage difference between the two video reference pins. It reproduces the reference circuit, but its necessity with video disabled is not documented. |
| C29 | 1u / 25V | Capacitor_SMD:C_0603_1608Metric | C1608X7R1E105K080AB | Cable inductance resists sudden input-current changes, which can disturb the 5 V input. This capacitor supplies local charge at the power switch input without directly exposing the larger downstream capacitors. |
| C30 | 100n / 100V | Capacitor_SMD:C_0603_1608Metric | GRM188R72A104KA35D | The microSD card draws fast current pulses that remote capacitors cannot supply through trace inductance. This 100 nF capacitor supplies those pulses beside the socket power pin. |
| C31 | 10u / 10V | Capacitor_SMD:C_0805_2012Metric | C2012X5R1A106M085AB | A microSD card also changes its current demand over longer intervals during internal operations. This 10 µF reservoir reduces local supply droop while the regulator responds. |
| C36 | 100n / 100V | Capacitor_SMD:C_0603_1608Metric | GRM188R72A104KA35D | The reset supervisor also needs a steady supply to make dependable voltage decisions. This nearby capacitor supplies its fast current changes without relying on distant capacitors. |
| C37 | 10u / 10V | Capacitor_SMD:C_0805_2012Metric | C2012X5R1A106M085AB | The switching regulator draws input current in pulses. This nearby capacitor supplies those pulses, reducing input-voltage disturbance and the area of the high-current switching loop. |
| C38 | 22u / 16V | Capacitor_SMD:C_0805_2012Metric | CL21A226MOCLRNC | The inductor current does not exactly match the changing 1.1 V core load current. This output capacitor absorbs the difference and participates in the regulator control response. |
| C39 | 10u / 10V | Capacitor_SMD:C_0805_2012Metric | C2012X5R1A106M085AB | The switching regulator draws input current in pulses. This nearby capacitor supplies those pulses, reducing input-voltage disturbance and the area of the high-current switching loop. |
| C40 | 22u / 16V | Capacitor_SMD:C_0805_2012Metric | CL21A226MOCLRNC | The inductor current does not exactly match the changing 2.5 V DDR load current. This output capacitor absorbs the difference and participates in the regulator control response. |
| C41 | 10u / 10V | Capacitor_SMD:C_0805_2012Metric | C2012X5R1A106M085AB | The switching regulator draws input current in pulses. This nearby capacitor supplies those pulses, reducing input-voltage disturbance and the area of the high-current switching loop. |
| C42 | 22u / 16V | Capacitor_SMD:C_0805_2012Metric | CL21A226MOCLRNC | The inductor current does not exactly match the changing 3.3 V I/O load current. This output capacitor absorbs the difference and participates in the regulator control response. |
| C43 | 1u / 25V | Capacitor_SMD:C_0603_1608Metric | C1608X7R1E105K080AB | Input wiring cannot supply every rapid current change at the analog regulator. This local input capacitor reduces those voltage changes and meets the regulator input-capacitance requirement. |
| C44 | 1u / 25V | Capacitor_SMD:C_0603_1608Metric | C1608X7R1E105K080AB | The analog regulator needs local output capacitance for a stable control response. C44 supplies that capacitance at the regulator, while the processor capacitors serve the distant load. |
| D1 | USBLC6-2SC6 | Package_TO_SOT_SMD:SOT-23-6 | USBLC6-2SC6 | A charged person or cable can inject a short, high-voltage pulse into USB signals. D1 diverts that pulse toward the supply clamp and ground, reducing stress on U1. |
| D2 | Green LED / low current | LED_SMD:LED_0603_1608Metric | APT1608LZGCK | An LED converts electrical current into visible light. D2 lights from the 3.3 V rail so you can see that this supply is present without relying on software. |
| D3 | Green LED / low current | LED_SMD:LED_0603_1608Metric | APT1608LZGCK | An LED can turn a processor output into a visible status signal. D3 lights when PC0 sinks current, allowing Linux to display activity or a state you choose. |
| H1 | M2.5 / 2.7mm | MountingHole:MountingHole_2.7mm_M2.5 | UNVERIFIED | The board needs a mechanical attachment that does not depend on its connectors. This upper-left 2.7 mm clearance hole provides one of the four requested M2.5 screw locations. |
| H2 | M2.5 / 2.7mm | MountingHole:MountingHole_2.7mm_M2.5 | UNVERIFIED | The board needs a mechanical attachment that does not depend on its connectors. This upper-right 2.7 mm clearance hole provides one of the four requested M2.5 screw locations. |
| H3 | M2.5 / 2.7mm | MountingHole:MountingHole_2.7mm_M2.5 | UNVERIFIED | The board needs a mechanical attachment that does not depend on its connectors. This lower-left 2.7 mm clearance hole provides one of the four requested M2.5 screw locations. |
| H4 | M2.5 / 2.7mm | MountingHole:MountingHole_2.7mm_M2.5 | UNVERIFIED | The board needs a mechanical attachment that does not depend on its connectors. This lower-right 2.7 mm clearance hole provides one of the four requested M2.5 screw locations. |
| J1 | USB-C / USB4105-GF-A | Connector_USB:USB_C_Receptacle_GCT_USB4105-xx-A_16P_TopMnt_Horizontal | USB4105-GF-A | The board needs an external source of energy and a physical USB connection. This USB-C receptacle supplies 5 V and connects the native USB data pair. |
| J2 | microSD / 104031-0811 | Connector_Card:microSD_HC_Molex_104031-0811 | 104031-0811 | U1 loses program memory without power, so Linux needs nonvolatile boot storage. This socket connects a removable microSD card that holds the bootloader, kernel, and filesystem. |
| J3 | GND / TX / RX | Connector_PinHeader_2.54mm:PinHeader_1x03_P2.54mm_Vertical | TSW-103-07-G-S | The processor sends boot messages as timed voltage pulses before Linux can offer USB services. This header exposes transmit, receive, and their common ground for a 3.3 V UART adapter. |
| L1 | 2.2uH / XFL4020 | Inductor_SMD:L_Coilcraft_XxL4020 | XFL4020-222MEC | An inductor stores energy in a magnetic field and resists sudden current changes. It turns the regulator switching pulses into smoother current for the 1.1 V core supply. |
| L2 | 2.2uH / XFL4020 | Inductor_SMD:L_Coilcraft_XxL4020 | XFL4020-222MEC | An inductor stores energy in a magnetic field and resists sudden current changes. It turns the regulator switching pulses into smoother current for the 2.5 V DDR supply. |
| L3 | 2.2uH / XFL4020 | Inductor_SMD:L_Coilcraft_XxL4020 | XFL4020-222MEC | An inductor stores energy in a magnetic field and resists sudden current changes. It turns the regulator switching pulses into smoother current for the 3.3 V I/O supply. |
| R1 | 2k / 0.1% | Resistor_SMD:R_0603_1608Metric | RG1608P-202-B-T5 | DDR receivers need a comparison voltage halfway between their supply and ground. R1 and equal-valued R2 divide the DDR supply in half, giving a nominal 1.278049 V reference at the revised target. |
| R2 | 2k / 0.1% | Resistor_SMD:R_0603_1608Metric | RG1608P-202-B-T5 | This resistor provides the lower half of the DDR reference divider. Its match to R1 keeps the reference near half the memory supply. |
| R3 | 200k / 1% | Resistor_SMD:R_0603_1608Metric | RC0603FR-07200KL | This resistor gives VRA1 a weak path to ground, allowing stored charge to dissipate. The reference boards include it, but the public documentation does not establish its necessity with audio disabled. |
| R4 | 200k / 1% | Resistor_SMD:R_0603_1608Metric | RC0603FR-07200KL | This resistor gives VRA2 a weak path to ground, allowing stored charge to dissipate. The reference boards include it, but the public documentation does not establish its necessity with audio disabled. |
| R5 | 5.1k / 1% | Resistor_SMD:R_0603_1608Metric | CR0603-FX-5101ELF | A USB-C source detects a power-consuming device through a resistance to ground on the active configuration pin. R5 supplies that identification on CC1. |
| R6 | 5.1k / 1% | Resistor_SMD:R_0603_1608Metric | CR0603-FX-5101ELF | Reversing the USB-C plug selects the other configuration pin. R6 supplies the same power-consumer identification on CC2, so either plug orientation can receive power. |
| R7 | 47k / 1% | Resistor_SMD:R_0603_1608Metric | RC0603FR-0747KL | The SD command wire can be temporarily undriven during startup or bus handover. This weak pullup gives it a defined high level while allowing either device to pull it low. |
| R8 | 47k / 1% | Resistor_SMD:R_0603_1608Metric | RC0603FR-0747KL | The SD data 0 wire can be temporarily undriven during startup or bus handover. This weak pullup gives it a defined high level while allowing either device to pull it low. |
| R9 | 47k / 1% | Resistor_SMD:R_0603_1608Metric | RC0603FR-0747KL | The SD data 1 wire can be temporarily undriven during startup or bus handover. This weak pullup gives it a defined high level while allowing either device to pull it low. |
| R10 | 47k / 1% | Resistor_SMD:R_0603_1608Metric | RC0603FR-0747KL | The SD data 2 wire can be temporarily undriven during startup or bus handover. This weak pullup gives it a defined high level while allowing either device to pull it low. |
| R11 | 47k / 1% | Resistor_SMD:R_0603_1608Metric | RC0603FR-0747KL | The SD data 3 wire can be temporarily undriven during startup or bus handover. This weak pullup gives it a defined high level while allowing either device to pull it low. |
| R12 | 22R | Resistor_SMD:R_0603_1608Metric | CRCW060322R0FKEA | Fast clock edges reflect from trace discontinuities and can cross an input threshold more than once. This source-series resistor damps those reflections, with 22 Ω as the initial value. |
| R13 | 67.3k / 0.1% | Resistor_SMD:R_0603_1608Metric | RN73R1JTTD6732B25 | The processor needs to remain in reset when its IO supply is too low. This upper divider resistor sets the nominal IO reset threshold to 3.092 V with R14. |
| R14 | 10k / 0.1% | Resistor_SMD:R_0603_1608Metric | RT0603BRD0710KL | This resistor provides the ground side of the 3.3 V I/O monitoring divider. Its ratio to R13 sets the voltage at which U7 stops the processor. |
| R15 | 55.6k / 0.1% | Resistor_SMD:R_0603_1608Metric | TNPW060355K6BEEA | The supervisor compares its input against 0.4 V rather than the full 2.8 V analog supply. R15 and R16 scale that supply to give a nominal 2.624 V reset threshold. |
| R16 | 10k / 0.1% | Resistor_SMD:R_0603_1608Metric | RT0603BRD0710KL | This resistor provides the ground side of the 2.8 V analog monitoring divider. Its ratio to R15 sets the voltage at which U7 stops the processor. |
| R17 | 48.7k / 0.1% | Resistor_SMD:R_0603_1608Metric | RQ73C1J48K7BTDF | The supervisor must distinguish a valid DDR supply from a brownout. This upper divider resistor scales DDR voltage to the sense input; its 10 ppm/C maximum temperature coefficient limits drift of the reset threshold. |
| R18 | 10k / 0.1% | Resistor_SMD:R_0603_1608Metric | TNPW060310K0BYEN | The supervisor senses a fraction of the DDR supply relative to ground. This lower divider resistor completes that ratio, with a 10 ppm/C maximum temperature coefficient to preserve reset-release margin over temperature. |
| R19 | 15.8k / 0.1% | Resistor_SMD:R_0603_1608Metric | RG1608P-1582-B-T5 | The supervisor compares its input against 0.4 V rather than the full 1.1 V core supply. R19 and R20 scale that supply to give a nominal 1.032 V reset threshold. |
| R20 | 10k / 0.1% | Resistor_SMD:R_0603_1608Metric | RT0603BRD0710KL | This resistor provides the ground side of the 1.1 V core monitoring divider. Its ratio to R19 sets the voltage at which U7 stops the processor. |
| R21 | 100k / 1% | Resistor_SMD:R_0603_1608Metric | RC0603FR-07100KL | U7 has no internal pullup on its manual-reset input, so an open button would leave that voltage undefined. This resistor pulls the input high until SW1 connects it to ground. |
| R22 | 47k / 1% | Resistor_SMD:R_0603_1608Metric | RC0603FR-0747KL | U7 can pull RESET_N low but cannot actively drive it high. R22 supplies the high level after every supervisor channel releases its output. |
| R23 | 340R / 0.1% | Resistor_SMD:R_0603_1608Metric | RT0603BRD07340RL | The regulator compares a fraction of the core supply against its internal reference to control the output voltage. This low-resistance feedback divider sets the revised target and reduces the voltage error caused by input leakage. |
| R24 | 820R / 0.05% | Resistor_SMD:R_0603_1608Metric | RG1608N-821-W-T1 | The regulator compares a fraction of the supply with its internal reference to control its output voltage. This lower divider resistor uses 0.05% tolerance and 10 ppm/C maximum drift to limit output uncertainty while its low resistance reduces feedback-pin leakage error. |
| R25 | 1.8k / 0.1% | Resistor_SMD:R_0603_1608Metric | RG1608P-182-B-T5 | The regulator compares a fraction of the DDR supply against its internal reference to control the output voltage. This low-resistance feedback divider sets the revised target and reduces the voltage error caused by input leakage. |
| R26 | 820R / 0.05% | Resistor_SMD:R_0603_1608Metric | RG1608N-821-W-T1 | The regulator compares a fraction of the supply with its internal reference to control its output voltage. This lower divider resistor uses 0.05% tolerance and 10 ppm/C maximum drift to limit output uncertainty while its low resistance reduces feedback-pin leakage error. |
| R27 | 2.67k / 0.1% | Resistor_SMD:R_0603_1608Metric | RG1608P-2671-B-T5 | The regulator compares a fraction of the IO supply against its internal reference to control the output voltage. This low-resistance feedback divider sets the revised target and reduces the voltage error caused by input leakage. |
| R28 | 820R / 0.05% | Resistor_SMD:R_0603_1608Metric | RG1608N-821-W-T1 | The regulator compares a fraction of the supply with its internal reference to control its output voltage. This lower divider resistor uses 0.05% tolerance and 10 ppm/C maximum drift to limit output uncertainty while its low resistance reduces feedback-pin leakage error. |
| R29 | 49.9k / 1% | Resistor_SMD:R_0603_1608Metric | RC0603FR-0749K9L | U5 needs a resistance to select its current limit. This 49.9 kΩ resistor sets approximately 520 mA typical, with the documented 475–565 mA range. |
| R30 | 1k / 1% | Resistor_SMD:R_0603_1608Metric | RC0603FR-071KL | An LED does not limit its own current once forward biased. This 1 kOhm resistor drops the remaining rail voltage and limits power-indicator current to a small continuous load. |
| R31 | 1k / 1% | Resistor_SMD:R_0603_1608Metric | RC0603FR-071KL | The status LED and GPIO both need a limit on current. This 1 kOhm resistor sets a low indicator current so PC0 can control D3 directly without another switching component. |
| SW1 | RESET | Button_Switch_SMD:SW_SPST_TL3305A | TL3305AF160QG | A stalled processor may be unable to restart itself through software. This button requests a hardware reset without unplugging power or relying on a working console. |
| U1 | F1C200s | BootConsole:F1C200s_QFN88_10x10_P0.4_EP6.74 | F1C200S | Linux needs a processor to execute instructions and RAM to hold running programs. U1 supplies both, including 64 MiB of memory inside its package. |
| U1 | F1C200s | BootConsole:F1C200s_QFN88_10x10_P0.4_EP6.74 | F1C200S | Linux needs a processor to execute instructions and RAM to hold running programs. U1 supplies both, including 64 MiB of memory inside its package. |
| U1 | F1C200s | BootConsole:F1C200s_QFN88_10x10_P0.4_EP6.74 | F1C200S | Linux needs a processor to execute instructions and RAM to hold running programs. U1 supplies both, including 64 MiB of memory inside its package. |
| U2 | TPS62160DGKR | Package_SO:MSOP-8_3x3mm_P0.65mm | TPS62160DGKR | The 1.1 V core domain cannot run directly from USB 5 V. This switching regulator reduces the voltage while dissipating less heat than a linear regulator at comparable current. |
| U3 | TPS62160DGKR | Package_SO:MSOP-8_3x3mm_P0.65mm | TPS62160DGKR | The 2.5 V DDR domain cannot run directly from USB 5 V. This switching regulator reduces the voltage while dissipating less heat than a linear regulator at comparable current. |
| U4 | TPS62160DGKR | Package_SO:MSOP-8_3x3mm_P0.65mm | TPS62160DGKR | The 3.3 V I/O domain cannot run directly from USB 5 V. This switching regulator reduces the voltage while dissipating less heat than a linear regulator at comparable current. |
| U5 | TPS2553DBVT | Package_TO_SOT_SMD:SOT-23-6 | TPS2553DBVT | Charging the board capacitors or a downstream short can demand excessive current from USB. U5 controls turn-on and limits current, although the board must still obey the source power allowance. |
| U6 | TLV75528PDBVR | Package_TO_SOT_SMD:SOT-23-5 | TLV75528PDBVR | The analog supply needs a lower voltage than the 3.3 V digital rail. This linear regulator produces 2.8 V from protected 5 V with few external parts. |
| U7 | TPS386000RGPT | BootConsole:TPS386000_RGP20_EP2.8 | TPS386000RGPT | Logic and memory can behave unpredictably while their supplies are too low. U7 holds the processor in reset until all four monitored rails pass their thresholds and release delays. |
| Y1 | 24 MHz / CL 18 pF | BootConsole:Raltron_H130A_5032 | H130A-24.000-18-2030-EXT-TR | Digital operations need a regular timing reference. This quartz crystal resonates at 24 MHz, giving U1 a reference for its internal clock generators. |

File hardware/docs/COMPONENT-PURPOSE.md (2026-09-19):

# Why each component exists

Every physical reference in the final board is listed below. Each explanation starts from the electrical or mechanical job the part performs; repeated bypass capacitors remain separate because their physical location serves a different current loop.

The board has 89 fitted electronic components and four M2.5 mounting holes. C32-C35 are intentionally absent.

| Reference | Value | Decision basis | Why it exists, from first principles | Evidence |
| --- | --- | --- | --- | --- |
| C1 | 30p / C0G / 1% | Functional | This capacitor supplies the oscillator input side of the crystal load network. Together with C2 and stray capacitance, it sets the load that determines crystal frequency. | XTAL |
| C2 | 30p / C0G / 1% | Functional | This capacitor supplies the oscillator output side of the crystal load network. Its initial 30 pF value needs confirmation with the assembled board, as does C1. | XTAL |
| C3 | 100n / 100V | Reliability | Fast interference can move the DDR comparison voltage and cause bit errors. C3 stores charge at that reference, reducing rapid voltage changes relative to ground. | REF |
| C4 | 100n / 100V | Reliability | The DDR reference must track half the memory supply, including fast supply changes. C4 and C3 form a capacitive divider that preserves this relationship. | REF |
| C5 | 100n / 100V | Reliability | Trace inductance prevents distant capacitors from supplying very fast current changes. C5 provides local charge for U1 pin 22, serving its processor core domain. | AW, REF |
| C6 | 100n / 100V | Reliability | Trace inductance prevents distant capacitors from supplying very fast current changes. C6 provides local charge for U1 pin 35, serving its processor core domain. | AW, REF |
| C7 | 100n / 100V | Reliability | Trace inductance prevents distant capacitors from supplying very fast current changes. C7 provides local charge for U1 pin 71, serving its processor core domain. | AW, REF |
| C8 | 4.7u / 10V | Reliability | The core supply can briefly demand more current than its regulator delivers through the connecting traces. This local 4.7 µF reservoir reduces voltage droop during those changes. | REF |
| C9 | 100n / 100V | Reliability | Trace inductance prevents distant capacitors from supplying very fast current changes. C9 provides local charge for U1 pin 30, serving its DDR memory domain. | AW, REF |
| C10 | 100n / 100V | Reliability | Trace inductance prevents distant capacitors from supplying very fast current changes. C10 provides local charge for U1 pin 31, serving its DDR memory domain. | AW, REF |
| C11 | 100n / 100V | Reliability | Trace inductance prevents distant capacitors from supplying very fast current changes. C11 provides local charge for U1 pin 32, serving its DDR memory domain. | AW, REF |
| C12 | 100n / 100V | Reliability | Trace inductance prevents distant capacitors from supplying very fast current changes. C12 provides local charge for U1 pin 34, serving its DDR memory domain. | AW, REF |
| C13 | 100n / 100V | Reliability | Trace inductance prevents distant capacitors from supplying very fast current changes. C13 provides local charge for U1 pin 36, serving its DDR memory domain. | AW, REF |
| C14 | 4.7u / 10V | Reliability | The DDR supply can briefly demand more current than its regulator delivers through the connecting traces. This local 4.7 µF reservoir reduces voltage droop during those changes. | REF |
| C15 | 100n / 100V | Reliability | Trace inductance prevents distant capacitors from supplying very fast current changes. C15 provides local charge for U1 pin 5, serving its I/O domain. | AW, REF |
| C16 | 100n / 100V | Reliability | Trace inductance prevents distant capacitors from supplying very fast current changes. C16 provides local charge for U1 pin 20, serving its I/O domain. | AW, REF |
| C17 | 100n / 100V | Reliability | Trace inductance prevents distant capacitors from supplying very fast current changes. C17 provides local charge for U1 pin 50, serving its I/O domain. | AW, REF |
| C18 | 100n / 100V | Reliability | Trace inductance prevents distant capacitors from supplying very fast current changes. C18 provides local charge for U1 pin 67, serving its USB domain. | AW, REF |
| C19 | 100n / 100V | Reliability | Trace inductance prevents distant capacitors from supplying very fast current changes. C19 provides local charge for U1 pin 4, serving its headphone supply domain. | AW, REF |
| C20 | 100n / 100V | Reliability | Trace inductance prevents distant capacitors from supplying very fast current changes. C20 provides local charge for U1 pin 73, serving its TV supply domain. | AW, REF |
| C21 | 4.7u / 10V | Reliability | The I/O supply can briefly demand more current than its regulator delivers through the connecting traces. This local 4.7 µF reservoir reduces voltage droop during those changes. | REF |
| C22 | 100n / 100V | Reliability | Trace inductance prevents distant capacitors from supplying very fast current changes. C22 provides local charge for U1 pin 80, serving its analog supply domain. | AW, REF |
| C23 | 4.7u / 10V | Reliability | The analog supply can briefly demand more current than its regulator delivers through the connecting traces. This local 4.7 µF reservoir reduces voltage droop during those changes. | REF |
| C24 | 1u / 25V | Reference precaution | This capacitor stores charge on the VRA1 analog reference, reducing rapid voltage changes. It preserves reference-board support for powered silicon, although its necessity with audio disabled is not documented. | REF |
| C25 | 1u / 25V | Reference precaution | This capacitor stores charge on the VRA2 analog reference, reducing rapid voltage changes. It preserves reference-board support for powered silicon, although its necessity with audio disabled is not documented. | REF |
| C26 | 10u / 10V | Reference precaution | This capacitor reduces rapid voltage changes on TV_VRN, an internal video reference brought outside U1. It preserves reference-board support, although its necessity with video disabled is not documented. | REF |
| C27 | 10u / 10V | Reference precaution | This capacitor reduces rapid voltage changes on TV_VRP, an internal video reference brought outside U1. It preserves reference-board support, although its necessity with video disabled is not documented. | REF |
| C28 | 1u / 25V | Reference precaution | This capacitor resists rapid changes in the voltage difference between the two video reference pins. It reproduces the reference circuit, but its necessity with video disabled is not documented. | REF |
| C29 | 1u / 25V | Reliability | Cable inductance resists sudden input-current changes, which can disturb the 5 V input. This capacitor supplies local charge at the power switch input without directly exposing the larger downstream capacitors. | SWITCH |
| C30 | 100n / 100V | Reliability | The microSD card draws fast current pulses that remote capacitors cannot supply through trace inductance. This 100 nF capacitor supplies those pulses beside the socket power pin. | SD, REF |
| C31 | 10u / 10V | Reliability | A microSD card also changes its current demand over longer intervals during internal operations. This 10 µF reservoir reduces local supply droop while the regulator responds. | SD, REF |
| C36 | 100n / 100V | Reliability | The reset supervisor also needs a steady supply to make dependable voltage decisions. This nearby capacitor supplies its fast current changes without relying on distant capacitors. | SUP |
| C37 | 10u / 10V | Architecture | The switching regulator draws input current in pulses. This nearby capacitor supplies those pulses, reducing input-voltage disturbance and the area of the high-current switching loop. | BUCK |
| C38 | 22u / 16V | Architecture | The inductor current does not exactly match the changing 1.1 V core load current. This output capacitor absorbs the difference and participates in the regulator control response. | BUCK |
| C39 | 10u / 10V | Architecture | The switching regulator draws input current in pulses. This nearby capacitor supplies those pulses, reducing input-voltage disturbance and the area of the high-current switching loop. | BUCK |
| C40 | 22u / 16V | Architecture | The inductor current does not exactly match the changing 2.5 V DDR load current. This output capacitor absorbs the difference and participates in the regulator control response. | BUCK |
| C41 | 10u / 10V | Architecture | The switching regulator draws input current in pulses. This nearby capacitor supplies those pulses, reducing input-voltage disturbance and the area of the high-current switching loop. | BUCK |
| C42 | 22u / 16V | Architecture | The inductor current does not exactly match the changing 3.3 V I/O load current. This output capacitor absorbs the difference and participates in the regulator control response. | BUCK |
| C43 | 1u / 25V | Architecture | Input wiring cannot supply every rapid current change at the analog regulator. This local input capacitor reduces those voltage changes and meets the regulator input-capacitance requirement. | LDO |
| C44 | 1u / 25V | Architecture | The analog regulator needs local output capacitance for a stable control response. C44 supplies that capacitance at the regulator, while the processor capacitors serve the distant load. | LDO |
| D1 | USBLC6-2SC6 | Protection | A charged person or cable can inject a short, high-voltage pulse into USB signals. D1 diverts that pulse toward the supply clamp and ground, reducing stress on U1. | ESD |
| D2 | Green LED / low current | Requested | An LED converts electrical current into visible light. D2 lights from the 3.3 V rail so you can see that this supply is present without relying on software. | LED, USER |
| D3 | Green LED / low current | Requested | An LED can turn a processor output into a visible status signal. D3 lights when PC0 sinks current, allowing Linux to display activity or a state you choose. | LED, AW, USER |
| H1 | M2.5 / 2.7mm | Requested | The board needs a mechanical attachment that does not depend on its connectors. This upper-left 2.7 mm clearance hole provides one of the four requested M2.5 screw locations. | USER |
| H2 | M2.5 / 2.7mm | Requested | The board needs a mechanical attachment that does not depend on its connectors. This upper-right 2.7 mm clearance hole provides one of the four requested M2.5 screw locations. | USER |
| H3 | M2.5 / 2.7mm | Requested | The board needs a mechanical attachment that does not depend on its connectors. This lower-left 2.7 mm clearance hole provides one of the four requested M2.5 screw locations. | USER |
| H4 | M2.5 / 2.7mm | Requested | The board needs a mechanical attachment that does not depend on its connectors. This lower-right 2.7 mm clearance hole provides one of the four requested M2.5 screw locations. | USER |
| J1 | USB-C / USB4105-GF-A | Requested | The board needs an external source of energy and a physical USB connection. This USB-C receptacle supplies 5 V and connects the native USB data pair. | USB |
| J2 | microSD / 104031-0811 | Functional | U1 loses program memory without power, so Linux needs nonvolatile boot storage. This socket connects a removable microSD card that holds the bootloader, kernel, and filesystem. | AW, SD |
| J3 | GND / TX / RX | Functional | The processor sends boot messages as timed voltage pulses before Linux can offer USB services. This header exposes transmit, receive, and their common ground for a 3.3 V UART adapter. | AW, REF |
| L1 | 2.2uH / XFL4020 | Architecture | An inductor stores energy in a magnetic field and resists sudden current changes. It turns the regulator switching pulses into smoother current for the 1.1 V core supply. | BUCK, IND |
| L2 | 2.2uH / XFL4020 | Architecture | An inductor stores energy in a magnetic field and resists sudden current changes. It turns the regulator switching pulses into smoother current for the 2.5 V DDR supply. | BUCK, IND |
| L3 | 2.2uH / XFL4020 | Architecture | An inductor stores energy in a magnetic field and resists sudden current changes. It turns the regulator switching pulses into smoother current for the 3.3 V I/O supply. | BUCK, IND |
| R1 | 2k / 0.1% | Functional | DDR receivers need a comparison voltage halfway between their supply and ground. R1 and equal-valued R2 divide the DDR supply in half, giving a nominal 1.278049 V reference at the revised target. | AW, REF |
| R2 | 2k / 0.1% | Functional | This resistor provides the lower half of the DDR reference divider. Its match to R1 keeps the reference near half the memory supply. | AW, REF |
| R3 | 200k / 1% | Reference precaution | This resistor gives VRA1 a weak path to ground, allowing stored charge to dissipate. The reference boards include it, but the public documentation does not establish its necessity with audio disabled. | REF |
| R4 | 200k / 1% | Reference precaution | This resistor gives VRA2 a weak path to ground, allowing stored charge to dissipate. The reference boards include it, but the public documentation does not establish its necessity with audio disabled. | REF |
| R5 | 5.1k / 1% | Functional | A USB-C source detects a power-consuming device through a resistance to ground on the active configuration pin. R5 supplies that identification on CC1. | USB |
| R6 | 5.1k / 1% | Functional | Reversing the USB-C plug selects the other configuration pin. R6 supplies the same power-consumer identification on CC2, so either plug orientation can receive power. | USB |
| R7 | 47k / 1% | Functional | The SD command wire can be temporarily undriven during startup or bus handover. This weak pullup gives it a defined high level while allowing either device to pull it low. | SD, REF |
| R8 | 47k / 1% | Functional | The SD data 0 wire can be temporarily undriven during startup or bus handover. This weak pullup gives it a defined high level while allowing either device to pull it low. | SD, REF |
| R9 | 47k / 1% | Functional | The SD data 1 wire can be temporarily undriven during startup or bus handover. This weak pullup gives it a defined high level while allowing either device to pull it low. | SD, REF |
| R10 | 47k / 1% | Functional | The SD data 2 wire can be temporarily undriven during startup or bus handover. This weak pullup gives it a defined high level while allowing either device to pull it low. | SD, REF |
| R11 | 47k / 1% | Functional | The SD data 3 wire can be temporarily undriven during startup or bus handover. This weak pullup gives it a defined high level while allowing either device to pull it low. | SD, REF |
| R12 | 22R | Reliability | Fast clock edges reflect from trace discontinuities and can cross an input threshold more than once. This source-series resistor damps those reflections, with 22 Ω as the initial value. | REF |
| R13 | 67.3k / 0.1% | Architecture | The processor needs to remain in reset when its IO supply is too low. This upper divider resistor sets the nominal IO reset threshold to 3.092 V with R14. | SUP |
| R14 | 10k / 0.1% | Architecture | This resistor provides the ground side of the 3.3 V I/O monitoring divider. Its ratio to R13 sets the voltage at which U7 stops the processor. | SUP |
| R15 | 55.6k / 0.1% | Architecture | The supervisor compares its input against 0.4 V rather than the full 2.8 V analog supply. R15 and R16 scale that supply to give a nominal 2.624 V reset threshold. | SUP |
| R16 | 10k / 0.1% | Architecture | This resistor provides the ground side of the 2.8 V analog monitoring divider. Its ratio to R15 sets the voltage at which U7 stops the processor. | SUP |
| R17 | 48.7k / 0.1% | Architecture | The supervisor must distinguish a valid DDR supply from a brownout. This upper divider resistor scales DDR voltage to the sense input; its 10 ppm/C maximum temperature coefficient limits drift of the reset threshold. | SUP |
| R18 | 10k / 0.1% | Architecture | The supervisor senses a fraction of the DDR supply relative to ground. This lower divider resistor completes that ratio, with a 10 ppm/C maximum temperature coefficient to preserve reset-release margin over temperature. | SUP |
| R19 | 15.8k / 0.1% | Architecture | The supervisor compares its input against 0.4 V rather than the full 1.1 V core supply. R19 and R20 scale that supply to give a nominal 1.032 V reset threshold. | SUP |
| R20 | 10k / 0.1% | Architecture | This resistor provides the ground side of the 1.1 V core monitoring divider. Its ratio to R19 sets the voltage at which U7 stops the processor. | SUP |
| R21 | 100k / 1% | Architecture | U7 has no internal pullup on its manual-reset input, so an open button would leave that voltage undefined. This resistor pulls the input high until SW1 connects it to ground. | SUP |
| R22 | 47k / 1% | Architecture | U7 can pull RESET_N low but cannot actively drive it high. R22 supplies the high level after every supervisor channel releases its output. | SUP |
| R23 | 340R / 0.1% | Architecture | The regulator compares a fraction of the core supply against its internal reference to control the output voltage. This low-resistance feedback divider sets the revised target and reduces the voltage error caused by input leakage. | BUCK |
| R24 | 820R / 0.05% | Architecture | The regulator compares a fraction of the supply with its internal reference to control its output voltage. This lower divider resistor uses 0.05% tolerance and 10 ppm/C maximum drift to limit output uncertainty while its low resistance reduces feedback-pin leakage error. | BUCK |
| R25 | 1.8k / 0.1% | Architecture | The regulator compares a fraction of the DDR supply against its internal reference to control the output voltage. This low-resistance feedback divider sets the revised target and reduces the voltage error caused by input leakage. | BUCK |
| R26 | 820R / 0.05% | Architecture | The regulator compares a fraction of the supply with its internal reference to control its output voltage. This lower divider resistor uses 0.05% tolerance and 10 ppm/C maximum drift to limit output uncertainty while its low resistance reduces feedback-pin leakage error. | BUCK |
| R27 | 2.67k / 0.1% | Architecture | The regulator compares a fraction of the IO supply against its internal reference to control the output voltage. This low-resistance feedback divider sets the revised target and reduces the voltage error caused by input leakage. | BUCK |
| R28 | 820R / 0.05% | Architecture | The regulator compares a fraction of the supply with its internal reference to control its output voltage. This lower divider resistor uses 0.05% tolerance and 10 ppm/C maximum drift to limit output uncertainty while its low resistance reduces feedback-pin leakage error. | BUCK |
| R29 | 49.9k / 1% | Architecture | U5 needs a resistance to select its current limit. This 49.9 kΩ resistor sets approximately 520 mA typical, with the documented 475–565 mA range. | SWITCH |
| R30 | 1k / 1% | Functional | An LED does not limit its own current once forward biased. This 1 kOhm resistor drops the remaining rail voltage and limits power-indicator current to a small continuous load. | LED |
| R31 | 1k / 1% | Functional | The status LED and GPIO both need a limit on current. This 1 kOhm resistor sets a low indicator current so PC0 can control D3 directly without another switching component. | LED, AW |
| SW1 | RESET | Bring-up | A stalled processor may be unable to restart itself through software. This button requests a hardware reset without unplugging power or relying on a working console. | SUP |
| U1 | F1C200s | Functional | Linux needs a processor to execute instructions and RAM to hold running programs. U1 supplies both, including 64 MiB of memory inside its package. | AW |
| U2 | TPS62160DGKR | Functional | The 1.1 V core domain cannot run directly from USB 5 V. This switching regulator reduces the voltage while dissipating less heat than a linear regulator at comparable current. | BUCK, AW |
| U3 | TPS62160DGKR | Functional | The 2.5 V DDR domain cannot run directly from USB 5 V. This switching regulator reduces the voltage while dissipating less heat than a linear regulator at comparable current. | BUCK, AW |
| U4 | TPS62160DGKR | Functional | The 3.3 V I/O domain cannot run directly from USB 5 V. This switching regulator reduces the voltage while dissipating less heat than a linear regulator at comparable current. | BUCK, AW |
| U5 | TPS2553DBVT | Protection | Charging the board capacitors or a downstream short can demand excessive current from USB. U5 controls turn-on and limits current, although the board must still obey the source power allowance. | SWITCH |
| U6 | TLV75528PDBVR | Functional | The analog supply needs a lower voltage than the 3.3 V digital rail. This linear regulator produces 2.8 V from protected 5 V with few external parts. | LDO, AW |
| U7 | TPS386000RGPT | Reliability | Logic and memory can behave unpredictably while their supplies are too low. U7 holds the processor in reset until all four monitored rails pass their thresholds and release delays. | SUP |
| Y1 | 24 MHz / CL 18 pF | Functional | Digital operations need a regular timing reference. This quartz crystal resonates at 24 MHz, giving U1 a reference for its internal clock generators. | AW, XTAL |

## Schematic annotations

These five symbols are not purchased or placed on the board.

| Reference | Why it exists |
| --- | --- |
| #FLG01 | KiCad needs to know that ground has a power source despite the passive connection in its netlist. This annotation supplies that information and creates no physical component. |
| #FLG02 | KiCad needs to know that USB VBUS has a power source despite the passive connection in its netlist. This annotation supplies that information and creates no physical component. |
| #FLG03 | KiCad needs to know that the core rail has a power source despite the passive connection in its netlist. This annotation supplies that information and creates no physical component. |
| #FLG04 | KiCad needs to know that the DDR rail has a power source despite the passive connection in its netlist. This annotation supplies that information and creates no physical component. |
| #FLG05 | KiCad needs to know that the I/O rail has a power source despite the passive connection in its netlist. This annotation supplies that information and creates no physical component. |

## Intentionally unpopulated references

| Reference | Omitted value | Why it is not fitted |
| --- | --- | --- |
| C32 | 1 nF | This capacitor would filter fast disturbances at a supervisor sense input. It is optional with U7, so the final board uses short sense traces and built-in transient rejection. |
| C33 | 1 nF | This capacitor would filter fast disturbances at a supervisor sense input. It is optional with U7, so the final board uses short sense traces and built-in transient rejection. |
| C34 | 1 nF | This capacitor would filter fast disturbances at a supervisor sense input. It is optional with U7, so the final board uses short sense traces and built-in transient rejection. |
| C35 | 1 nF | This capacitor would filter fast disturbances at a supervisor sense input. It is optional with U7, so the final board uses short sense traces and built-in transient rejection. |
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

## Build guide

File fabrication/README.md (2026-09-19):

# JLCPCB fabrication package

These files correspond to the final KiCad source in `hardware/`.

| Upload or use | File |
|---|---|
| Bare PCB | `clarks-board-JLCPCB-gerbers.zip` |
| Optional top stencil | `clarks-board-top-stencil.zip` |
| Optional bottom stencil | `clarks-board-bottom-stencil.zip` |
| JLCPCB assembly BOM | `assembly/clarks-board-JLCPCB-BOM.csv` |
| JLCPCB component placement | `assembly/clarks-board-JLCPCB-CPL.csv` |

Order the board as four-layer FR-4, 44 × 44 mm, 1.6 mm nominal thickness, 1 oz outer copper, black solder mask, white silkscreen, and ENIG finish. Use ordinary routed edges; the visible copper border is inset from the rounded outline. Vias are intended to be tented on both sides.

The ZIPs contain the exact exported Gerbers, plated/non-plated drill files, and paste layers from the built revision. Do not mirror them. All exports share the same origin.

USB impedance and the saved dielectric stackup are provisional. Select a JLCPCB controlled-impedance stackup and revalidate the USB pair before treating a changed layout as impedance-controlled.

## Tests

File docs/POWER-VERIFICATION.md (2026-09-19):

# Power/reset fix verification

The final design in `hardware/` corrects the reset-release tolerance problem. All three buck rails clear the calculated maximum reset-release threshold in the tested low-output cases, and their tested startup peaks remain below the processor operating maxima.

## What changed

| References | Final selection | Reason |
|---|---|---|
| R23 / R24 | 340 Ω / 820 Ω | Core target 1.131707 V; lower divider resistance reduces FB leakage error. |
| R25 / R26 | 1.8 kΩ / 820 Ω | DDR target 2.556098 V with positive reset-release margin. |
| R27 / R28 | 2.67 kΩ / 820 Ω | I/O target 3.404878 V with positive reset-release margin. |
| R24 / R26 / R28 precision | Susumu RG1608N-821-W-T1, ±0.05%, ≤10 ppm/°C | Narrows the worst-case output range enough to retain startup headroom. |
| R23 / R25 / R27 precision | ±0.1%, ≤25 ppm/°C | Explicit ratio-error budget with independent temperature drift. |
| R13 | 67.3 kΩ, ±0.1%, ≤25 ppm/°C | Stocked selection; nominal I/O falling reset threshold is 3.092 V. |
| R17 / R18 precision | 48.7 kΩ / 10 kΩ, ±0.1%, ≤10 ppm/°C | Reduces drift of the DDR reset threshold. |

A feedback input draws a small leakage current. That current creates an unwanted voltage across the divider resistance, approximately `I_leak × R_upper`; reducing the resistance reduces this error. Each revised divider draws about 0.976 mA, exchanging a few milliwatts for less voltage uncertainty.

The bucks, supervisor, 2.8 V LDO, capacitors and USB current limiter are unchanged. U5 DBVT and U7 RGPT are packaging-quantity sourcing suffixes for the existing silicon. Capacitor rating labels now match selected MPNs; nominal capacitances remain unchanged. The `+1V1`, `+2V5` and `+3V3` net names identify voltage classes, while the schematic records the precise targets.

## Calculated corners

Resistor initial tolerance and independent temperature drift are multiplied at the worst endpoint relative to 25°C, covering −40 to +125°C. Feedback top/bottom grades are treated separately. The buck bound includes −3.5%/+4% PSM output accuracy and conservative ±400 nA FB leakage; the supervisor includes 396–404 mV threshold, up to 10 mV rising hysteresis and ±25 nA sense leakage.

An additional **assumed** allowance covers 5 mV of line/load/layout error on core and DDR, and 10 mV on I/O. TI provides typical, rather than guaranteed, separate line/load figures, so these allowances are engineering budgets rather than a guarantee over all hardware conditions.

| Rail | Nominal (V) | Lowest output after allowance (V) | Highest release threshold (V) | DC release margin (mV) | Highest output after allowance (V) |
|---|---:|---:|---:|---:|---:|
| CORE | 1.131707 | 1.085364 | 1.073111 | 12.252 | 1.183840 |
| DDR | 2.556098 | 2.452455 | 2.439481 | 12.974 | 2.673213 |
| IO | 3.404878 | 3.262091 | 3.221480 | 40.611 | 3.565716 |

The unchanged analog rail uses the previous 2.758–2.842 V LDO bound. Including independent 25 ppm/°C sense-resistor drift gives a 2.733404 V maximum release threshold, leaving 19.596 mV after a 5 mV allowance. Its previous nominal and half-capacitance transients remain historical supporting tests; no new analog transient was required by this resistor-only buck revision.

## Saved transient results

Nine cases comprise three nominal traces and six revised voltage-corner traces. Nominal cases are reused because the final precision substitution changes tolerance/TCR grades, not nominal electrical values. Corner cases use half nominal capacitance and a test-only FB voltage offset to represent the calculated output extreme plus its allowance. This is a typical TI dynamic model with an imposed setpoint corner, not a full statistical or temperature model.

| Rail | Minimum low-corner voltage after 0.9 ms (V) | Remaining release margin (mV) | Maximum high-corner voltage, including startup (V) | Headroom to CPU maximum (mV) |
|---|---:|---:|---:|---:|
| CORE | 1.080908 | 7.777 | 1.195414 | 4.566 |
| DDR | 2.447933 | 8.432 | 2.697963 | 2.017 |
| IO | 3.256965 | 35.465 | 3.596007 | 3.973 |

The comparisons include another 20 µV guard for the negligible difference between the original additive bench thresholds and final multiplicative threshold calculations. All runs reached 2.3 ms with valid transient vectors and no simulator abort. Core loads step 50→400→50 mA; DDR and I/O step 30→250→30 mA at 1.30/1.80 ms, with voltage-dependent taper below nominal. These are assumed test loads, not an Allwinner boot-current profile.

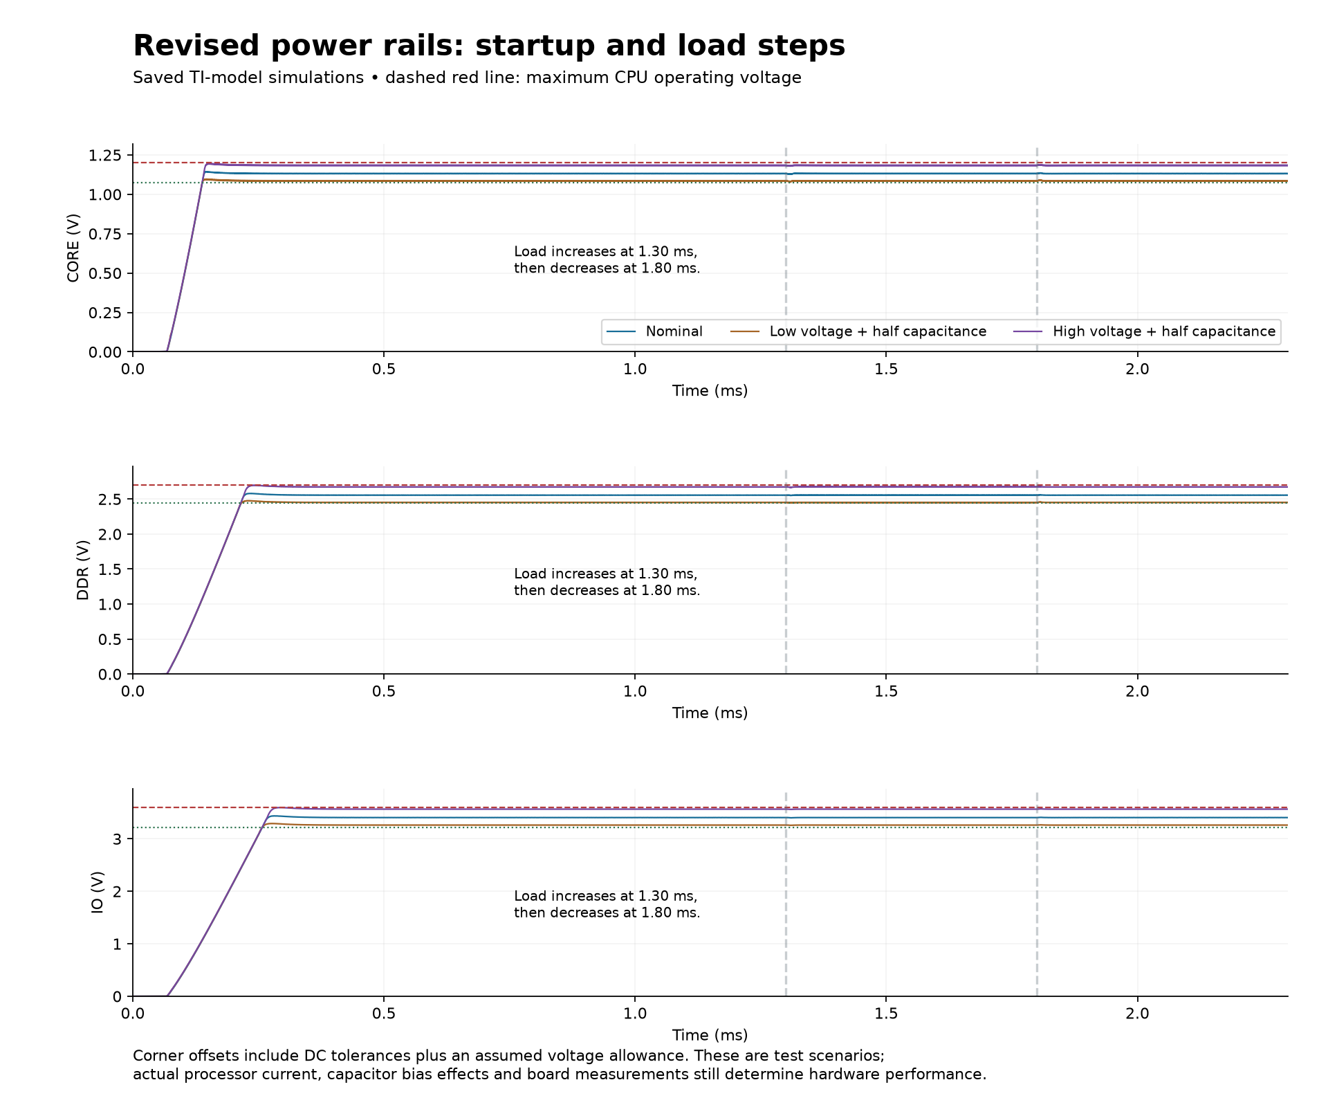
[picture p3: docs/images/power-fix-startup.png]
Revised startup and load-step plots


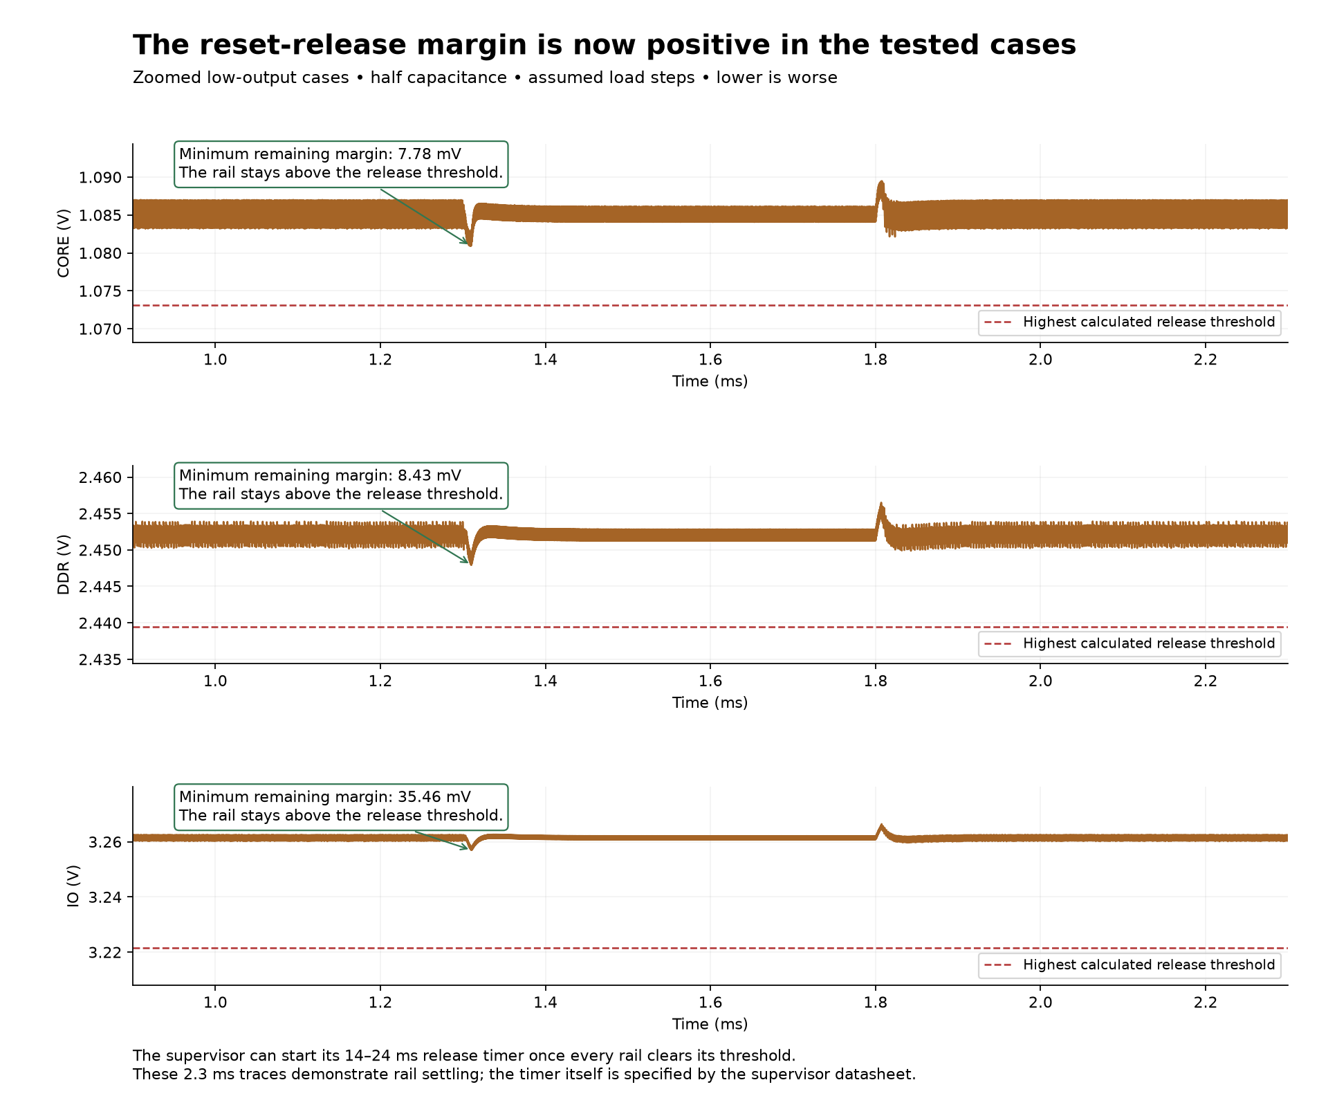
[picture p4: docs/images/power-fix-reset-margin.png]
Annotated reset-release margins


CT pins remain open. Each supervisor channel starts a 14–24 ms release timer only after its rail passes the rising threshold; the last channel to release controls the shared reset net. The 2.3 ms buck traces demonstrate rail settling, not a simulation of the full reset timer. Fast brownout protection also depends on supervisor delay and actual rail-discharge slope.

## Validation and practical limits

- ERC and DRC pass with zero violations, zero unconnected items and zero schematic parity findings.
- The independent audit matches all 89 fitted references, values, MPNs and specified precision properties; U1 retains all three symbol units. Pin/net connections and PCB geometry match the previous wired/routed sources.
- Purchasing records distinguish distributor stock from JLCPCB assembly inventory.
- A first trial with all feedback resistors at 0.1%/25 ppm passed low-output release but exceeded DDR/I/O startup operating maxima by about 1–2 mV. A 47 µF capacitor trial did not improve that overshoot. The final design retains 22 µF and tightens only the 820 Ω precision grade.
- Tighter simulator tolerances caused convergence failures in the TI model. Completed verification uses `reltol=0.003`. Numerical results are model evidence rather than a hardware guarantee.
- The small remaining high-corner headroom, capacitor DC bias/temperature effects, PCB drops and actual CPU/SD load require first-board measurements. The half-capacitance cases are sensitivity tests, not an exact characterization of the purchased capacitors.
- R29 remains 49.9 kΩ; TPS2553 limits near 475–565 mA. The earlier high-load USB scenario can still hit this limit. Without a measured boot-current profile, raising it would not establish a valid USB power budget. USB/whole-board startup is not proven by independent buck benches.
- USB controlled impedance and final fabrication stackup remain provisional. These are unchanged layout qualifications, recorded with the fresh fabrication package.

## Saved evidence and sources

`POWER-FIX-final.json` and `POWER-FIX-final-bounds.json` retain the final calculated limits and simulation summary. The plots above retain the final nominal and corner behavior without committing hundreds of megabytes of generated waveform arrays.

Primary requirements: [TI TPS62160](https://www.ti.com/lit/ds/symlink/tps62160.pdf), [TI TPS386000](https://www.ti.com/lit/ds/symlink/tps386000.pdf), [TI TLV755P](https://www.ti.com/lit/ds/symlink/tlv755p.pdf), and [TI TPS2553](https://www.ti.com/lit/ds/symlink/tps2553.pdf).

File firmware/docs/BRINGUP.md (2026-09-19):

# Firmware validation and first-board bring-up

This procedure separates checks that can run before hardware exists from checks
that require an assembled board. Passing the build checks means the image is
internally consistent. It does not establish that the board boots.

## Pre-hardware gate

Run these commands from `my-first-linux-board/firmware`:

```sh
./build-container.sh
./build-container.sh validate
shasum -a 256 output/images/sdcard.img
```

The validator reads the resolved Buildroot, Linux, and U-Boot configurations. It
decompiles the generated DTB with `dtc` and checks the 64 MiB memory range,
UART0 PE0/PE1 selection, SDC0 settings, PC0 active-low activity LED, native USB
peripheral mode, and disabled SPI0. It also checks the ACM+ECM configfs gadget,
DHCP policy, SSH host-key storage, web endpoint, boot arguments, partitions, and
getty startup. A source-only review or successful DTS preprocessing is not a
substitute for this command.

Record the source revisions from `SOURCES.md`, build log, validator output, image
size, and SHA-256 digest with the board test record. Keep the generated image as
the exact artifact under test.

Before using an image, also confirm from the build log and generated files that:

- SPL plus U-Boot fits in its 1016 KiB raw region beginning at 8 KiB.
- `zImage`, `linux.dtb`, and `boot.scr` fit in the 16 MiB FAT partition.
- The zImage input, decompressed kernel, DTB, U-Boot runtime, and stack do not
  overlap anywhere in `0x80000000`–`0x83ffffff`.
- `/dev/mmcblk0p2` is the ext4 root partition and the kernel command line mounts
  it read-only.
- `CONFIG_USB_CONFIGFS_ACM=y` and `CONFIG_USB_CONFIGFS_ECM=y` are built in;
  legacy `CONFIG_USB_G_SERIAL` is disabled. Development identity `1d6b:0104`
  is expected until a production VID/PID is assigned.

The first-boot image starts from `multi_v5_defconfig`. Its resolved configuration
contains `CONFIG_I2C=y` and several unused I2C controller drivers even though no
I2C node is enabled for this board and no I2C userspace tooling is included.
This is accepted bring-up-image baggage. Kernel size pruning belongs after a
successful hardware boot. `CONFIG_SPI=n` remains required; the IPv4 network
stack exists only for the USB ECM link.

Do not write the image to an SD card as part of this gate. Selecting and
overwriting a removable device is a separate, destructive operation.

## Equipment and setup

Use a current-limited 5 V bench supply or a USB-C source with a USB power meter,
a 3.3 V USB-to-UART adapter, a known-good microSD card prepared from the validated
image, a multimeter, and an oscilloscope for reset and clock checks. Leave the
UART adapter's power pin disconnected. Connect only GND, adapter RX to board TX
(J3 pin 2), and adapter TX to board RX (J3 pin 3). Open 115200 8N1 with no flow
control before applying board power.

Inspect for shorts, reversed polarized parts, solder bridges around U1 and the
microSD socket, and connector damage. With power disconnected, measure resistance
from each rail to ground and record it. Stop if a reading indicates a hard short
or differs sharply from the same rail on another board.

## Power-only check

Start with a conservative current limit. Raise it only after the input and rails
behave normally; do not repeatedly cycle a board that remains at the limit.
Apply 5 V without an SD card and record input current and these rails:

| Test point or net | Nominal value |
| --- | ---: |
| `+1V1` | 1.132 V |
| `+2V5` | 2.556 V |
| `+3V3` | 3.405 V |
| `+2V8_A` | 2.800 V |
| `DDR_VREF` | 1.278 V |

Verify the 24 MHz oscillator starts and `RESET_N` remains low until all monitored
rails are valid, then releases after the expected 14–24 ms delay. Record scope
captures of power-up and reset. Stop for a missing rail, sustained current-limit
operation, excessive heating, an unstable oscillator, or reset that never
releases.

## First boot over UART

Insert the prepared card while power is off, start the UART capture, then apply
power. Preserve the complete log. Expected milestones, in order, are:

1. U-Boot SPL banner on UART0.
2. U-Boot reports approximately 64 MiB DRAM and finds the SD card.
3. U-Boot loads `zImage` and `linux.dtb` and executes `bootz` without an overlap
   or bad-FDT error.
4. Linux emits early console output on `ttyS0`, mounts `/dev/mmcblk0p2` as ext4
   read-only, starts BusyBox init, and presents a login prompt.
5. The green status LED begins flickering with CPU activity.

At the shell, capture:

```sh
cat /proc/cmdline
cat /proc/meminfo
mount
dmesg
cat /sys/class/leds/boot-console:green:status/trigger
```

Confirm usable memory is consistent with 64 MiB minus kernel reservations,
`/` is mounted `ro`, `/run` and `/tmp` are tmpfs, and there is no repeating getty
or driver error. Power-cycle at least ten times and confirm every capture reaches
the login prompt without manual intervention.

## Peripheral checks

For microSD, copy a test file to `/tmp`, read stable data from the root filesystem,
and inspect `dmesg` for timeouts or CRC errors. The final image uses the
hardware-proven one-bit, 12.5 MHz SDC0 configuration with `broken-cd`; hot
insertion is outside this first-board test.

For the LED, disable the trigger and command both states:

```sh
echo none > /sys/class/leds/boot-console:green:status/trigger
echo 1 > /sys/class/leds/boot-console:green:status/brightness
echo 0 > /sys/class/leds/boot-console:green:status/brightness
```

Brightness `1` must light the active-low PC0 LED. Confirm SPI0 is absent or
disabled in the live device tree.

Connect the native USB-C port to a host only after UART boot is stable. Confirm
the host enumerates composite device `1d6b:0104` with CDC ACM and CDC ECM,
`/dev/ttyGS0` and `usb0` exist on the board, and a terminal reaches a login
prompt. Confirm `usb0` is `192.168.7.2/24` and the host receives an address from
`192.168.7.10`–`192.168.7.20` without a default route or DNS setting from this
link. Then test from the host:

```sh
curl http://192.168.7.2/cgi-bin/metrics
ssh root@192.168.7.2
```

Confirm the metrics response uses Prometheus text format and includes board,
CPU, memory, filesystem, microSD, network, service, USB gadget, and LED series.
Confirm `/` returns 404 because metrics are the only HTTP resource. The SSH
password is blank on this directly attached development image. Reboot once and
verify the SSH fingerprint remains stable because its generated host key is
stored on the FAT boot partition. Disconnect and reconnect the host several
times; UART must remain usable and the USB getty must not enter a rapid restart
loop.

## Failure localization

No UART text points first to input power, rails, reset, oscillator, boot ROM SD
access, or the PE0/PE1 connection. An SPL banner followed by failure points to
DRAM initialization. A U-Boot prompt without Linux output points to file loading,
load-address overlap, DTB validity, or boot arguments. Kernel output followed by
a root-mount panic points to SDC0, partition numbering, ext4 support, or
`rootwait`. A working UART login with no USB console isolates the problem to the
USB PHY/controller, configfs gadget setup, cable, or host enumeration. ACM
working while Ethernet fails narrows the problem to the ECM function, host
driver, `usb0` setup, or DHCP. Record the full UART log and measured rails before
changing the image or board.

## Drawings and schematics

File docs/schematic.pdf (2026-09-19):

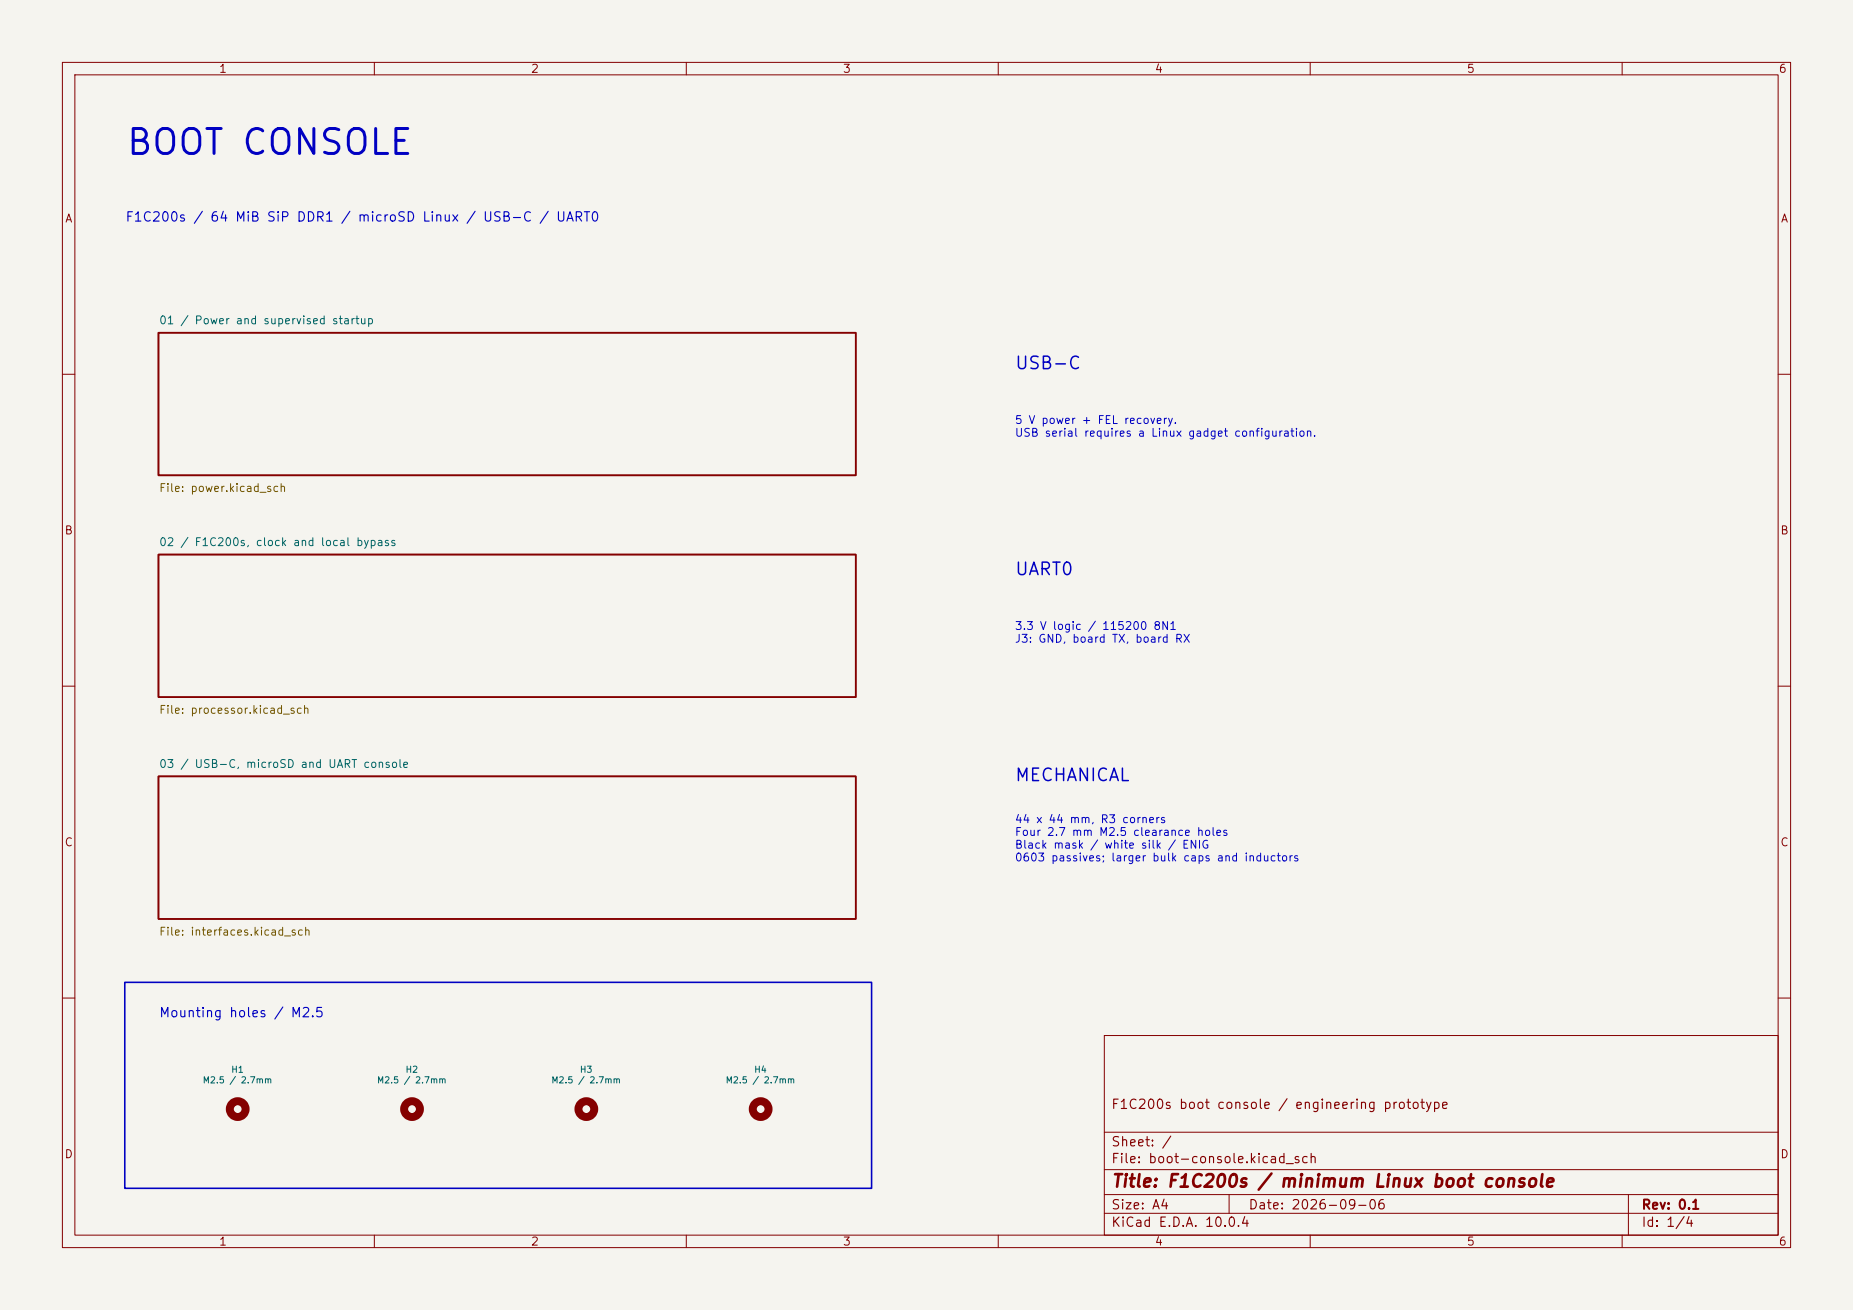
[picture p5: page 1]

F1C200s / 64 MiB SiP DDR1 / microSD Linux / USB-C / UART0

01 / Power and supervised startup

5 V power + FEL recovery. USB serial requires a Linux gadget configuration.

File: power.kicad_sch 02 / F1C200s, clock and local bypass File: processor.kicad_sch 03 / USB-C, microSD and UART console

3.3 V logic / 115200 8N1
J3: GND, board TX, board RX MECHANICAL

44 x 44 mm, R3 corners Four 2.7 mm M2.5 clearance holes Black mask / white silk / ENIG

0603 passives; larger bulk caps and inductors Mounting holes / M2.5

F1C200s boot console / engineering prototype

Sheet: /
File: boot-console.kicad_sch
Title: F1C200s / minimum Linux boot console

Size: A4 | Rev: 0.1
KiCad E.D.A. 10.0.4 | Id: 1/4

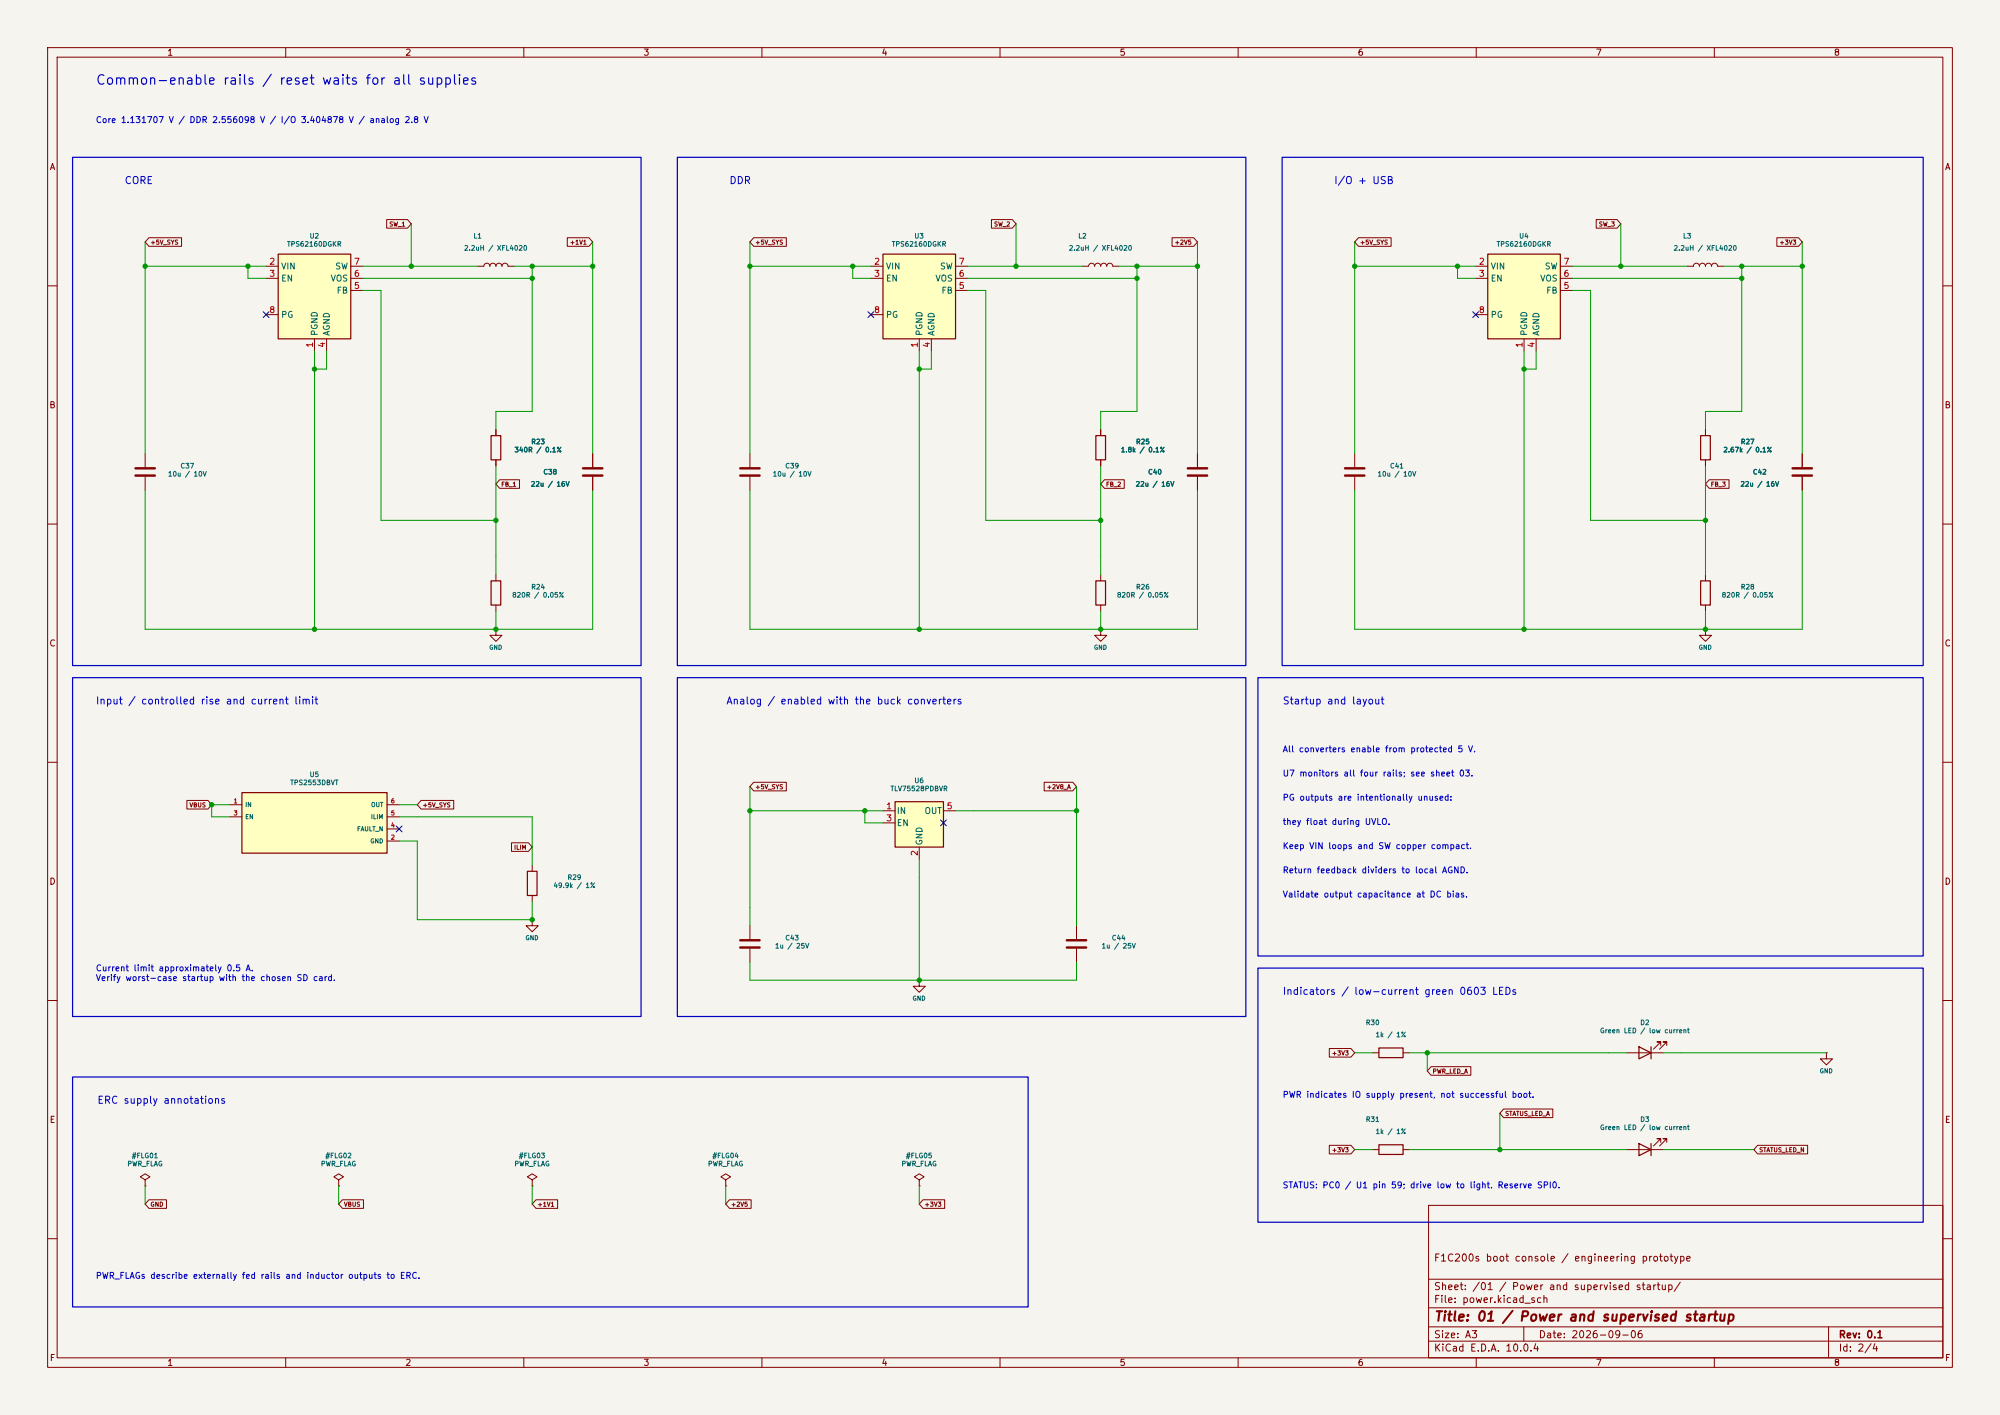
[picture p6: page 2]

Common-enable rails / reset waits for all supplies

All converters enable from protected 5 V. Startup and layout U7 monitors all four rails; see sheet 03.

PWR_LED_A Return feedback dividers to local AGND. Validate output capacitance at DC bias. they float during UVLO. Keep VIN loops and SW copper compact.

Indicators / low-current green 0603 LEDs

D3 Green LED / low current

F1C200s boot console / engineering prototype

Sheet: /01 / Power and supervised startup/
File: power.kicad_sch
Title: 01 / Power and supervised startup

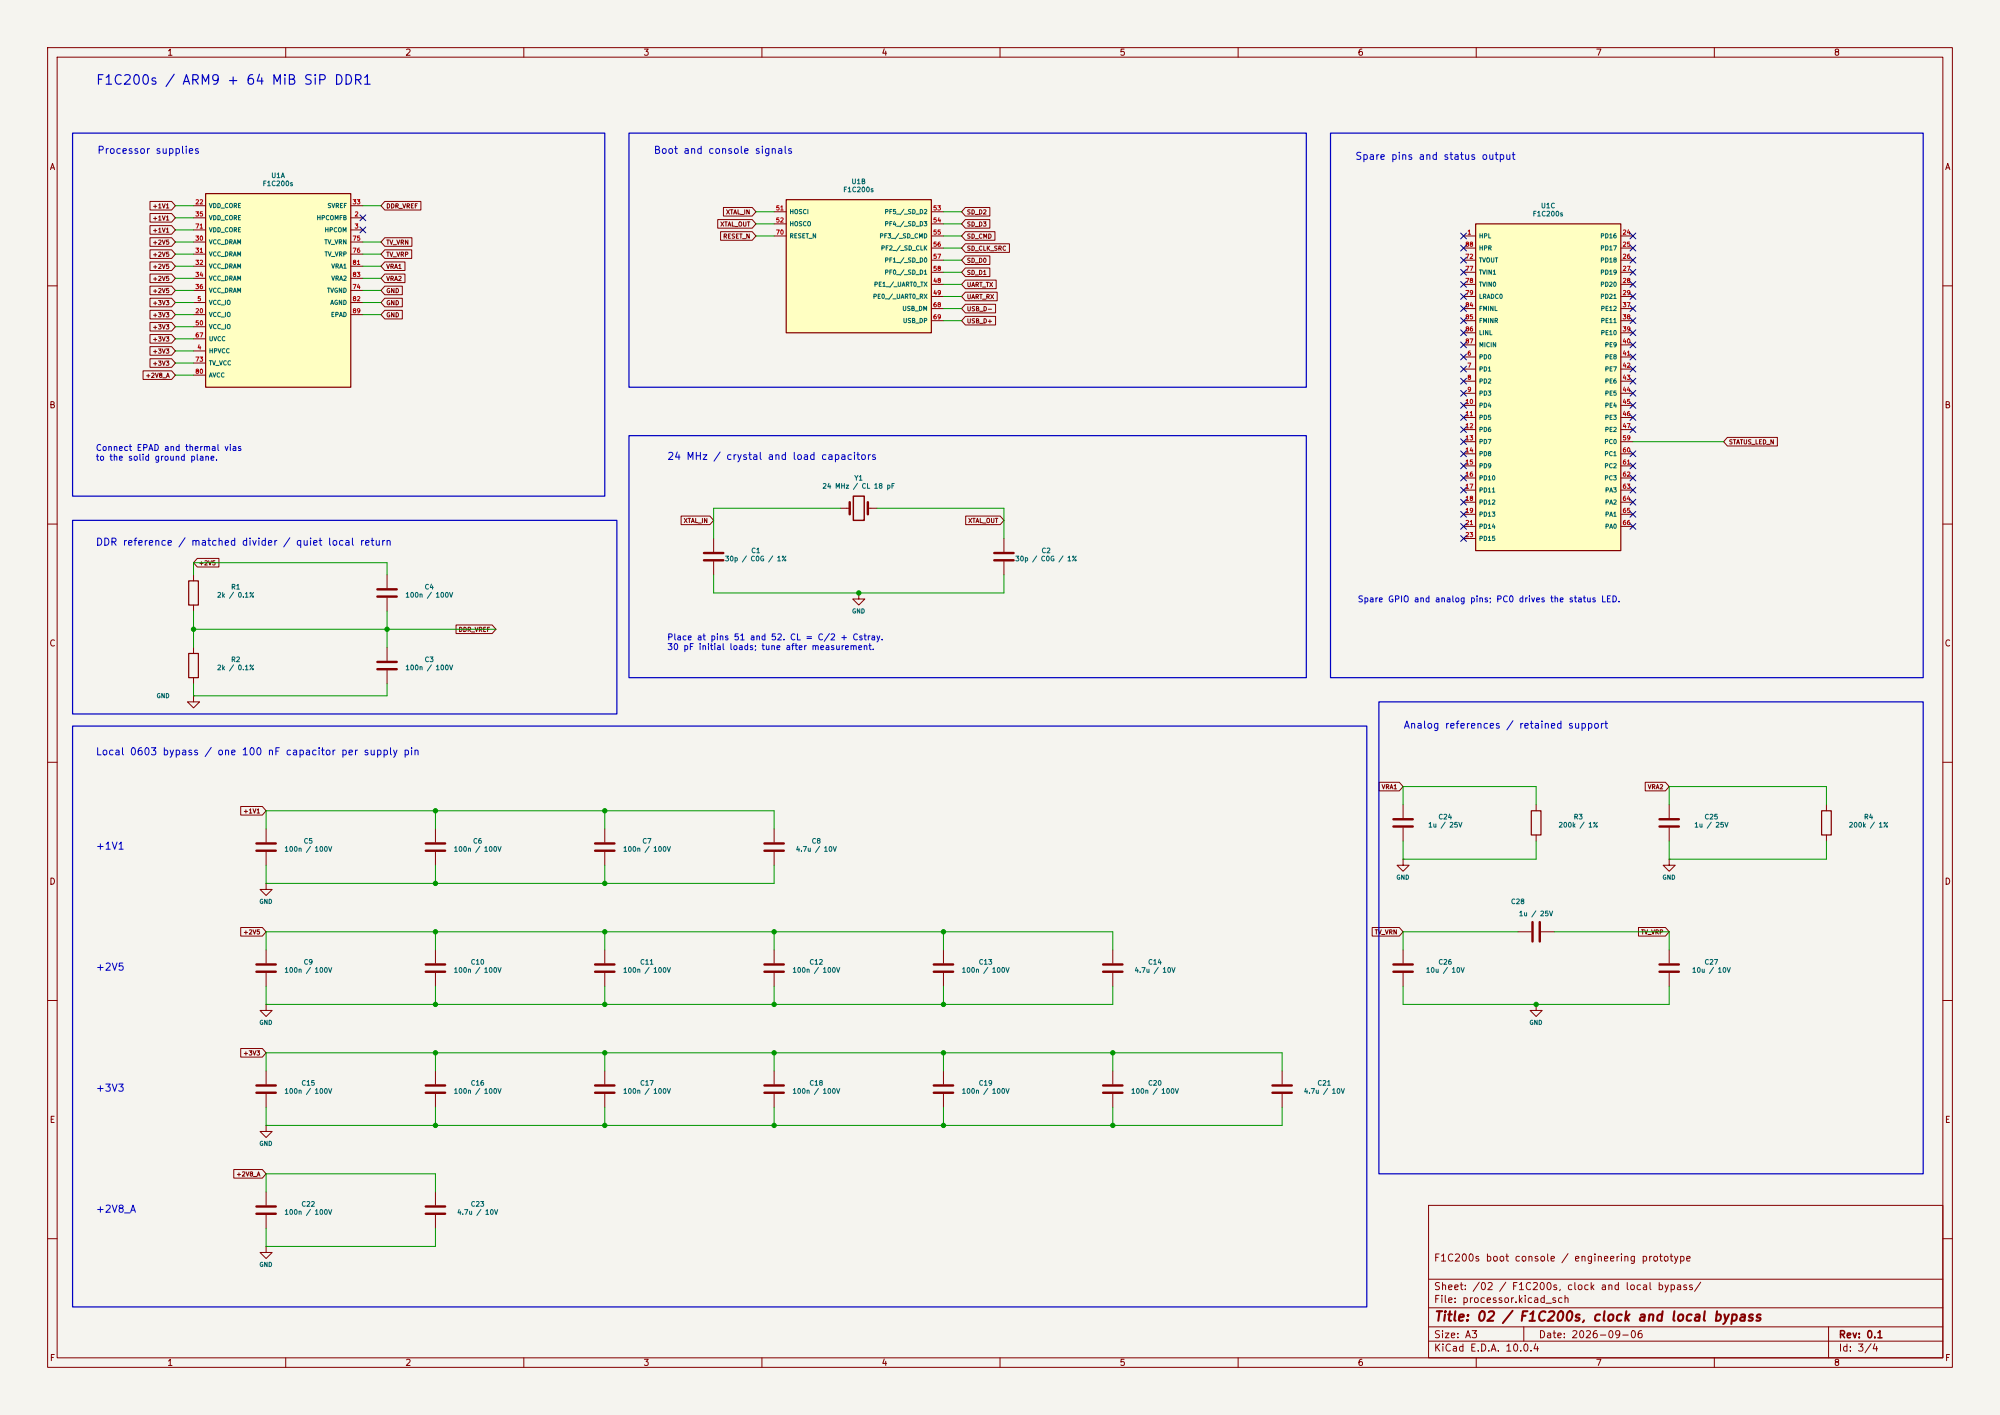
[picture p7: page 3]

Processor supplies
Spare GPIO and analog pins; PC0 drives the status LED. Spare pins and status output Connect EPAD and thermal vias

Boot and console signals

DDR reference / matched divider / quiet local return

Analog references / retained support

Local 0603 bypass / one 100 nF capacitor per supply pin

F1C200s boot console / engineering prototype

Sheet: /02 / F1C200s, clock and local bypass/
File: processor.kicad_sch
Title: 02 / F1C200s, clock and local bypass

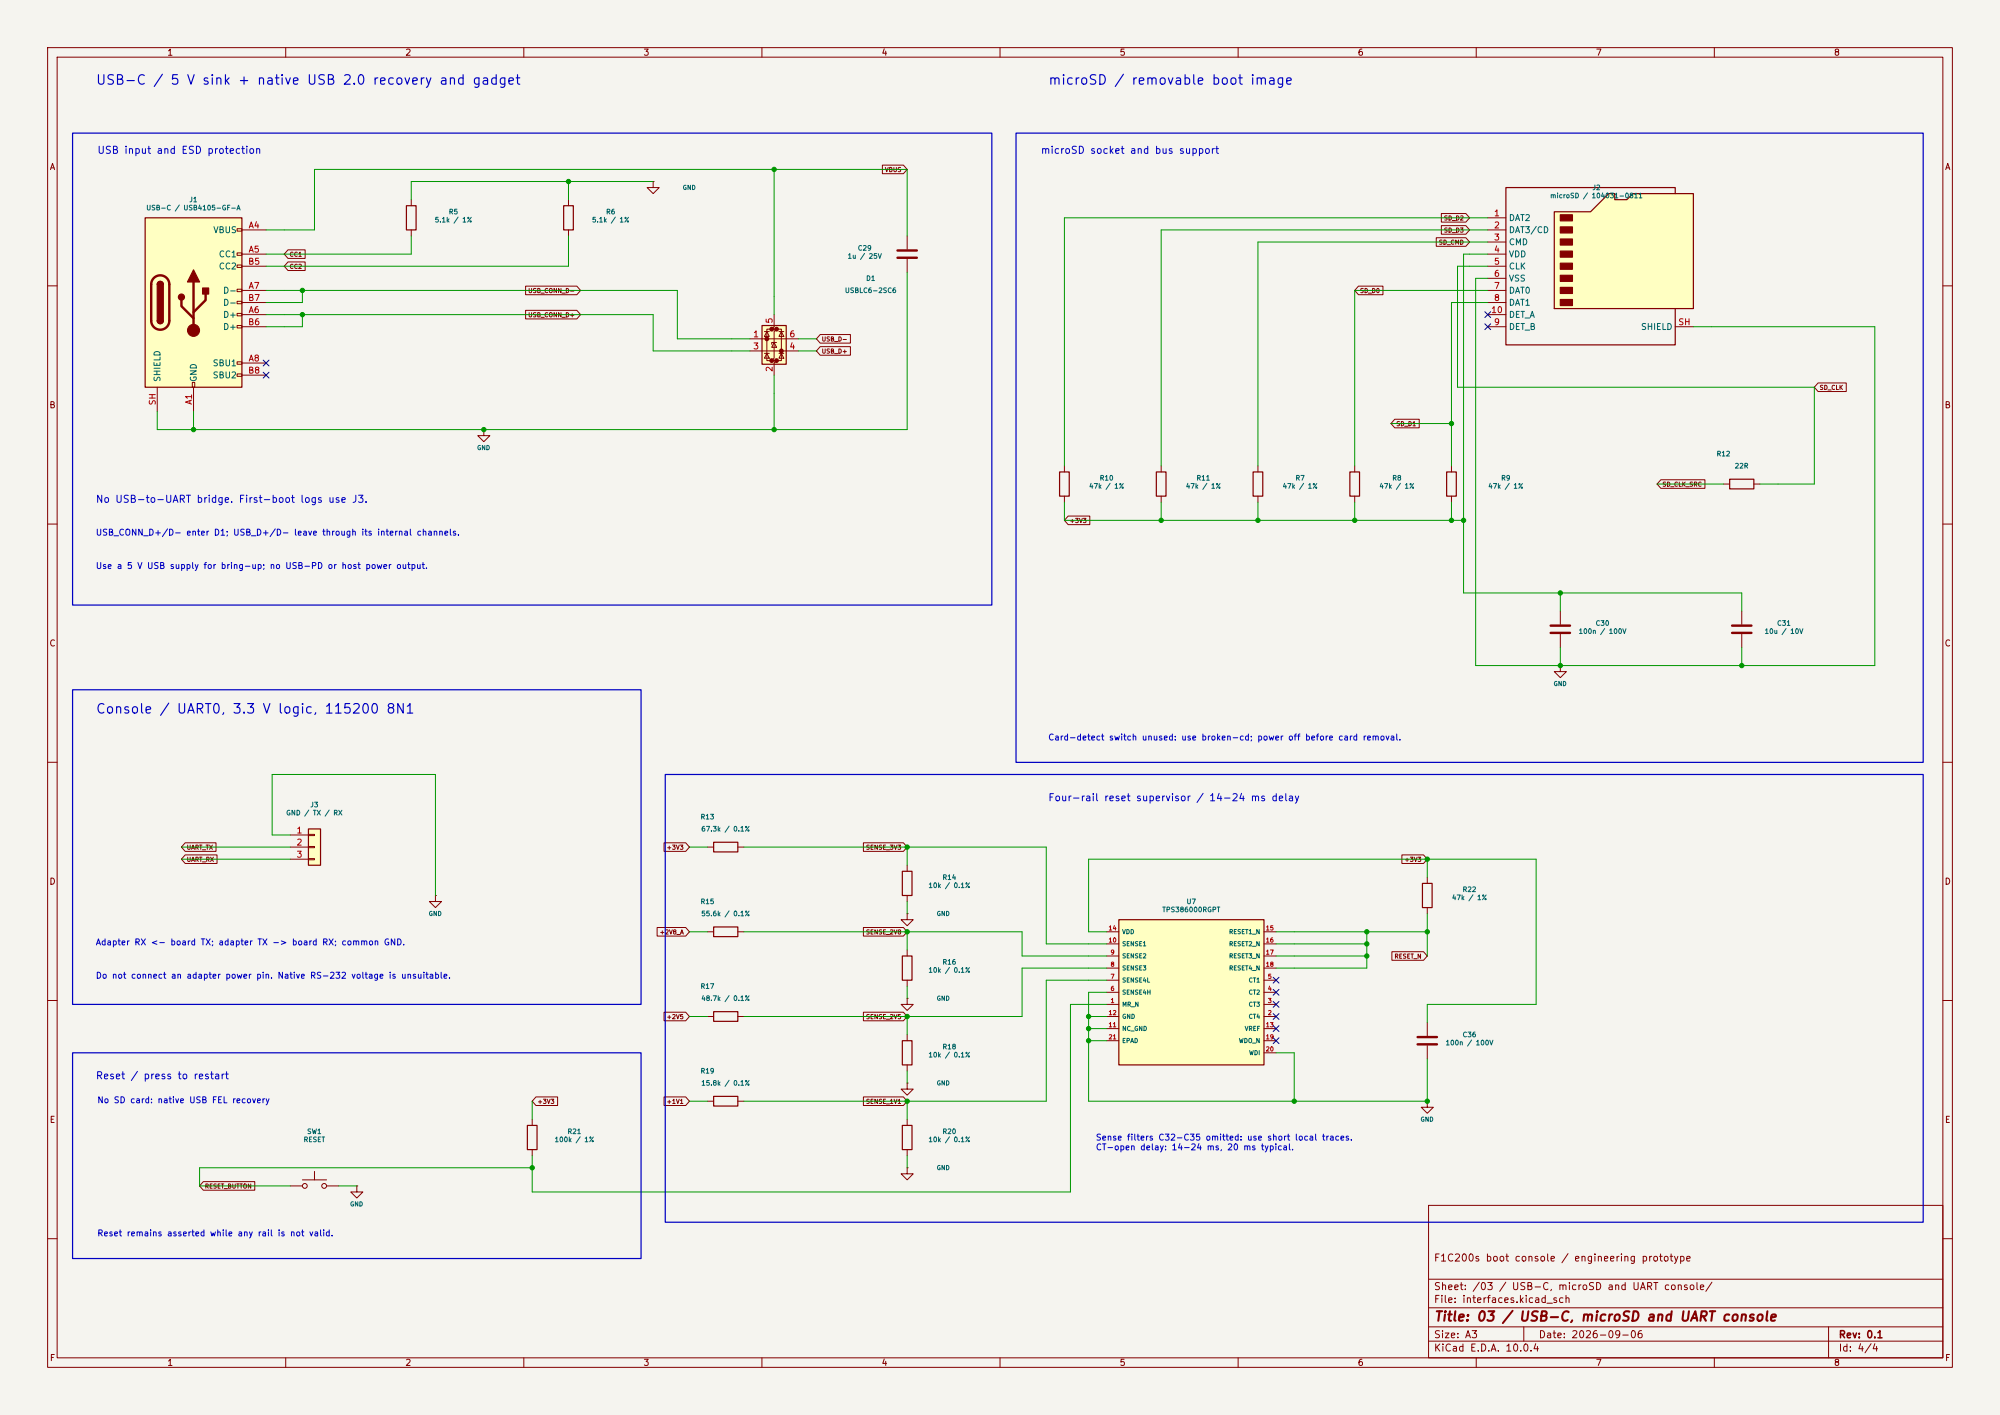
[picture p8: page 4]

USB-C / 5 V sink + native USB 2.0 recovery and gadget

microSD / removable boot image

USB input and ESD protection

microSD socket and bus support

Use a 5 V USB supply for bring-up; no USB-PD or host power output.

Console / UART0, 3.3 V logic, 115200 8N1

Four-rail reset supervisor / 14-24 ms delay

Adapter RX <- board TX; adapter TX -> board RX; common GND. Reset remains asserted while any rail is not valid. No SD card: native USB FEL recovery Reset / press to restart Do not connect an adapter power pin. Native RS-232 voltage is unsuitable.

SENSE4H 6

F1C200s boot console / engineering prototype

Sheet: /03 / USB-C, microSD and UART console/
File: interfaces.kicad_sch
Title: 03 / USB-C, microSD and UART console

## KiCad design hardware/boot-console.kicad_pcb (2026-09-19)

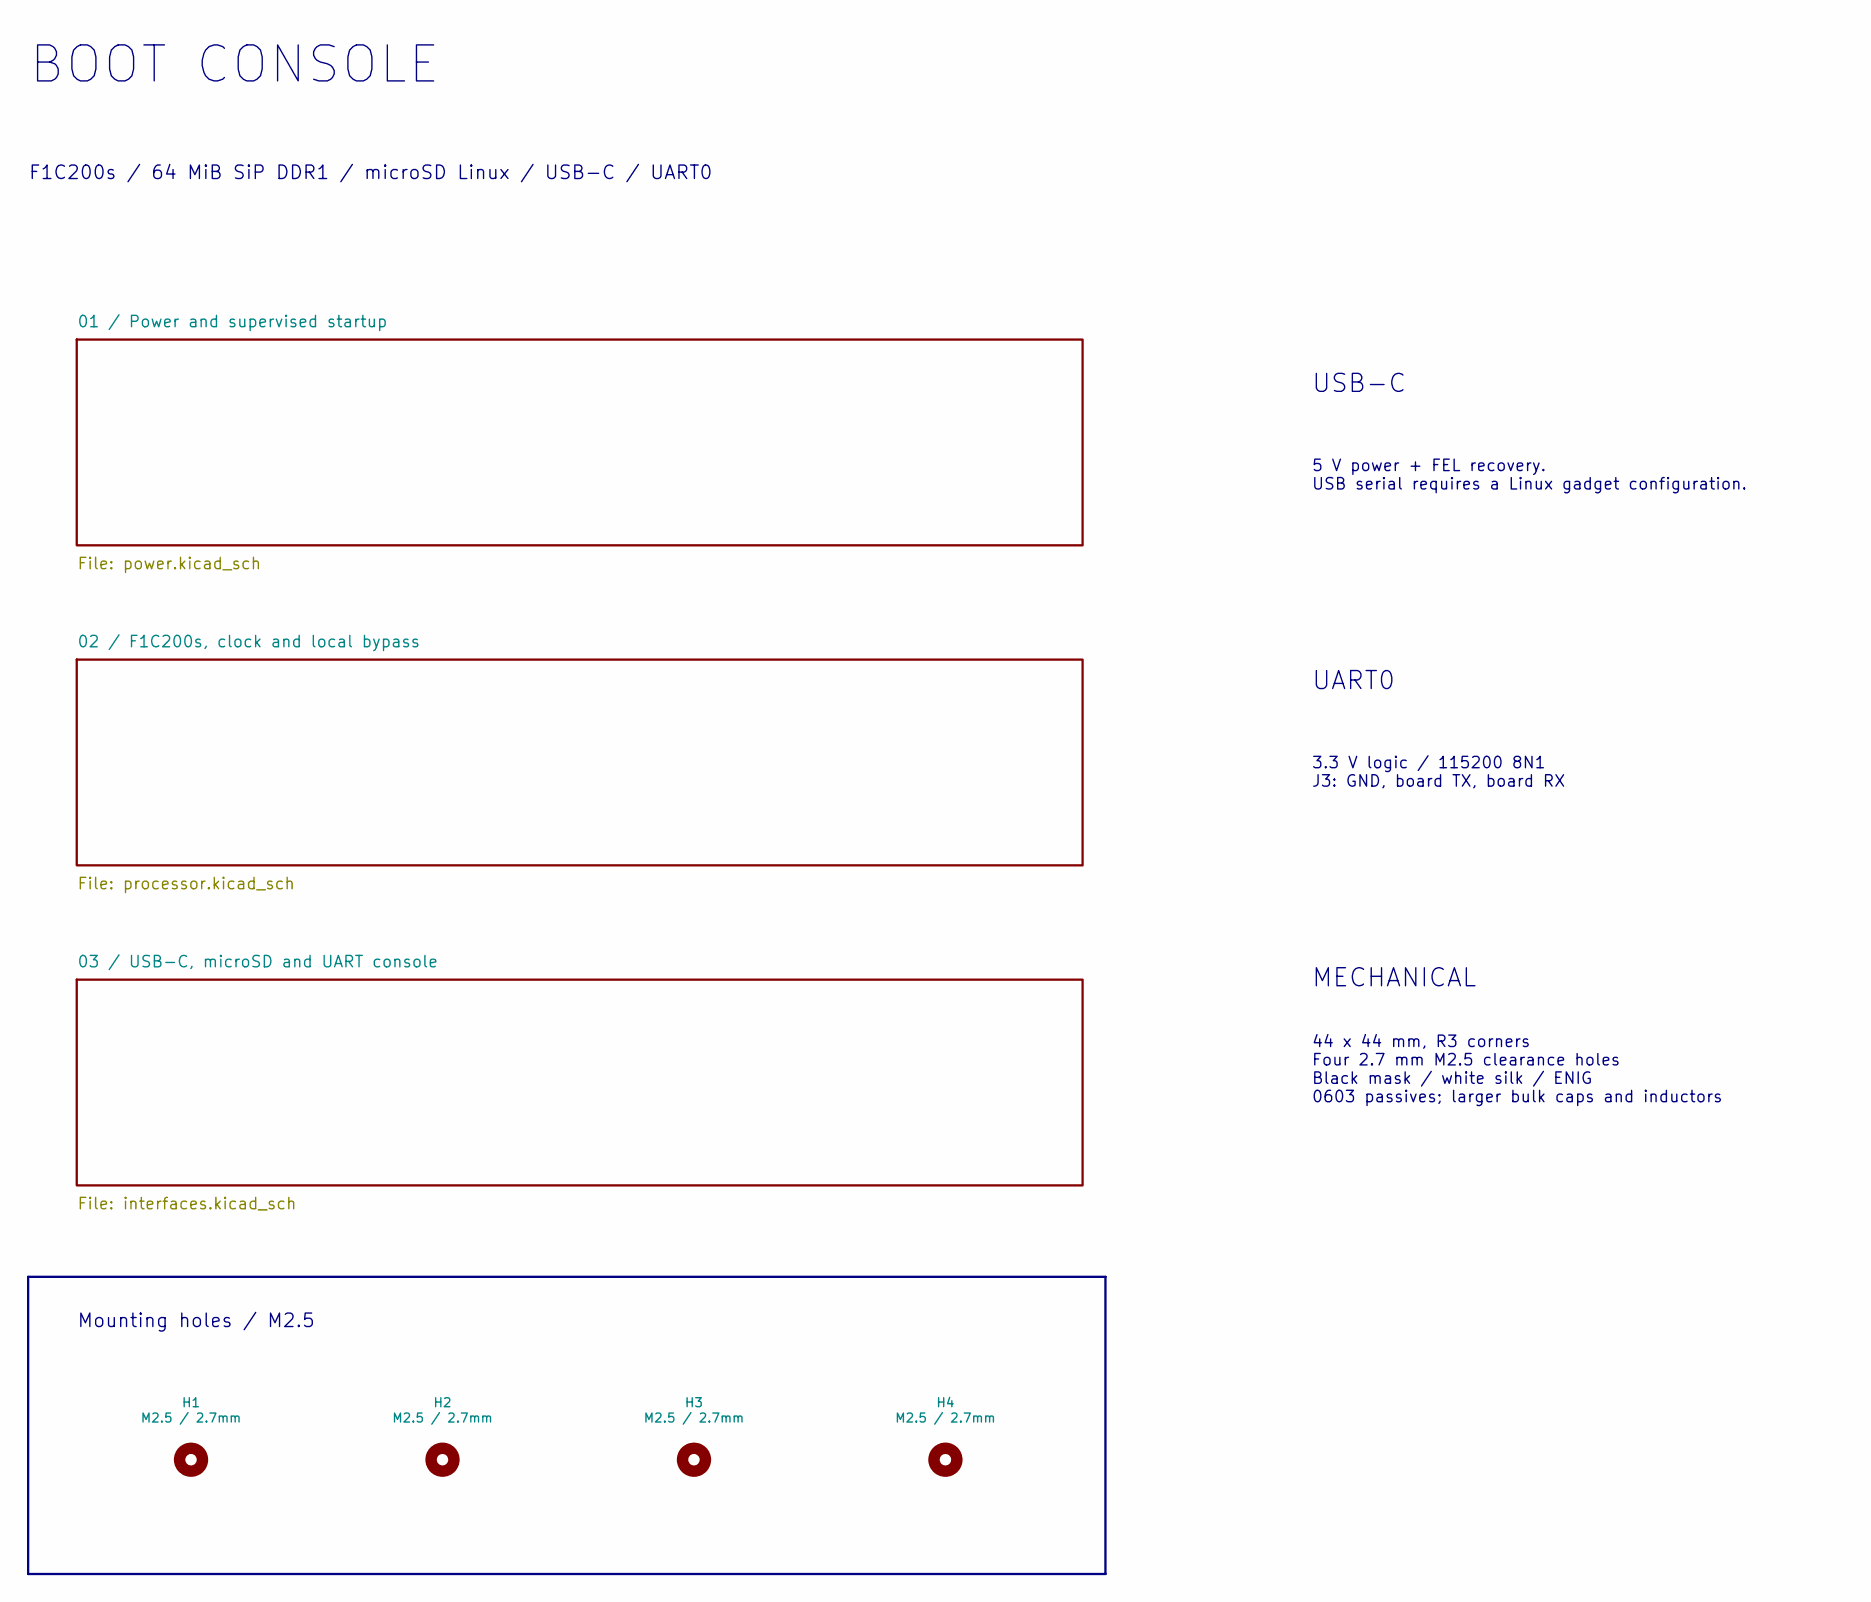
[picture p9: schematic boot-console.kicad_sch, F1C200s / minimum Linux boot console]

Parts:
H1, H2, H3, H4: M2.5 / 2.7mm; MountingHole_2.7mm_M2.5

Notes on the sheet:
BOOT CONSOLE
F1C200s / 64 MiB SiP DDR1 / microSD Linux / USB-C / UART0
USB-C
5 V power + FEL recovery. USB serial requires a Linux gadget configuration.
UART0
3.3 V logic / 115200 8N1 J3: GND, board TX, board RX
MECHANICAL
44 x 44 mm, R3 corners Four 2.7 mm M2.5 clearance holes Black mask / white silk / ENIG 0603 passives; larger bulk caps and inductors
Mounting holes / M2.5

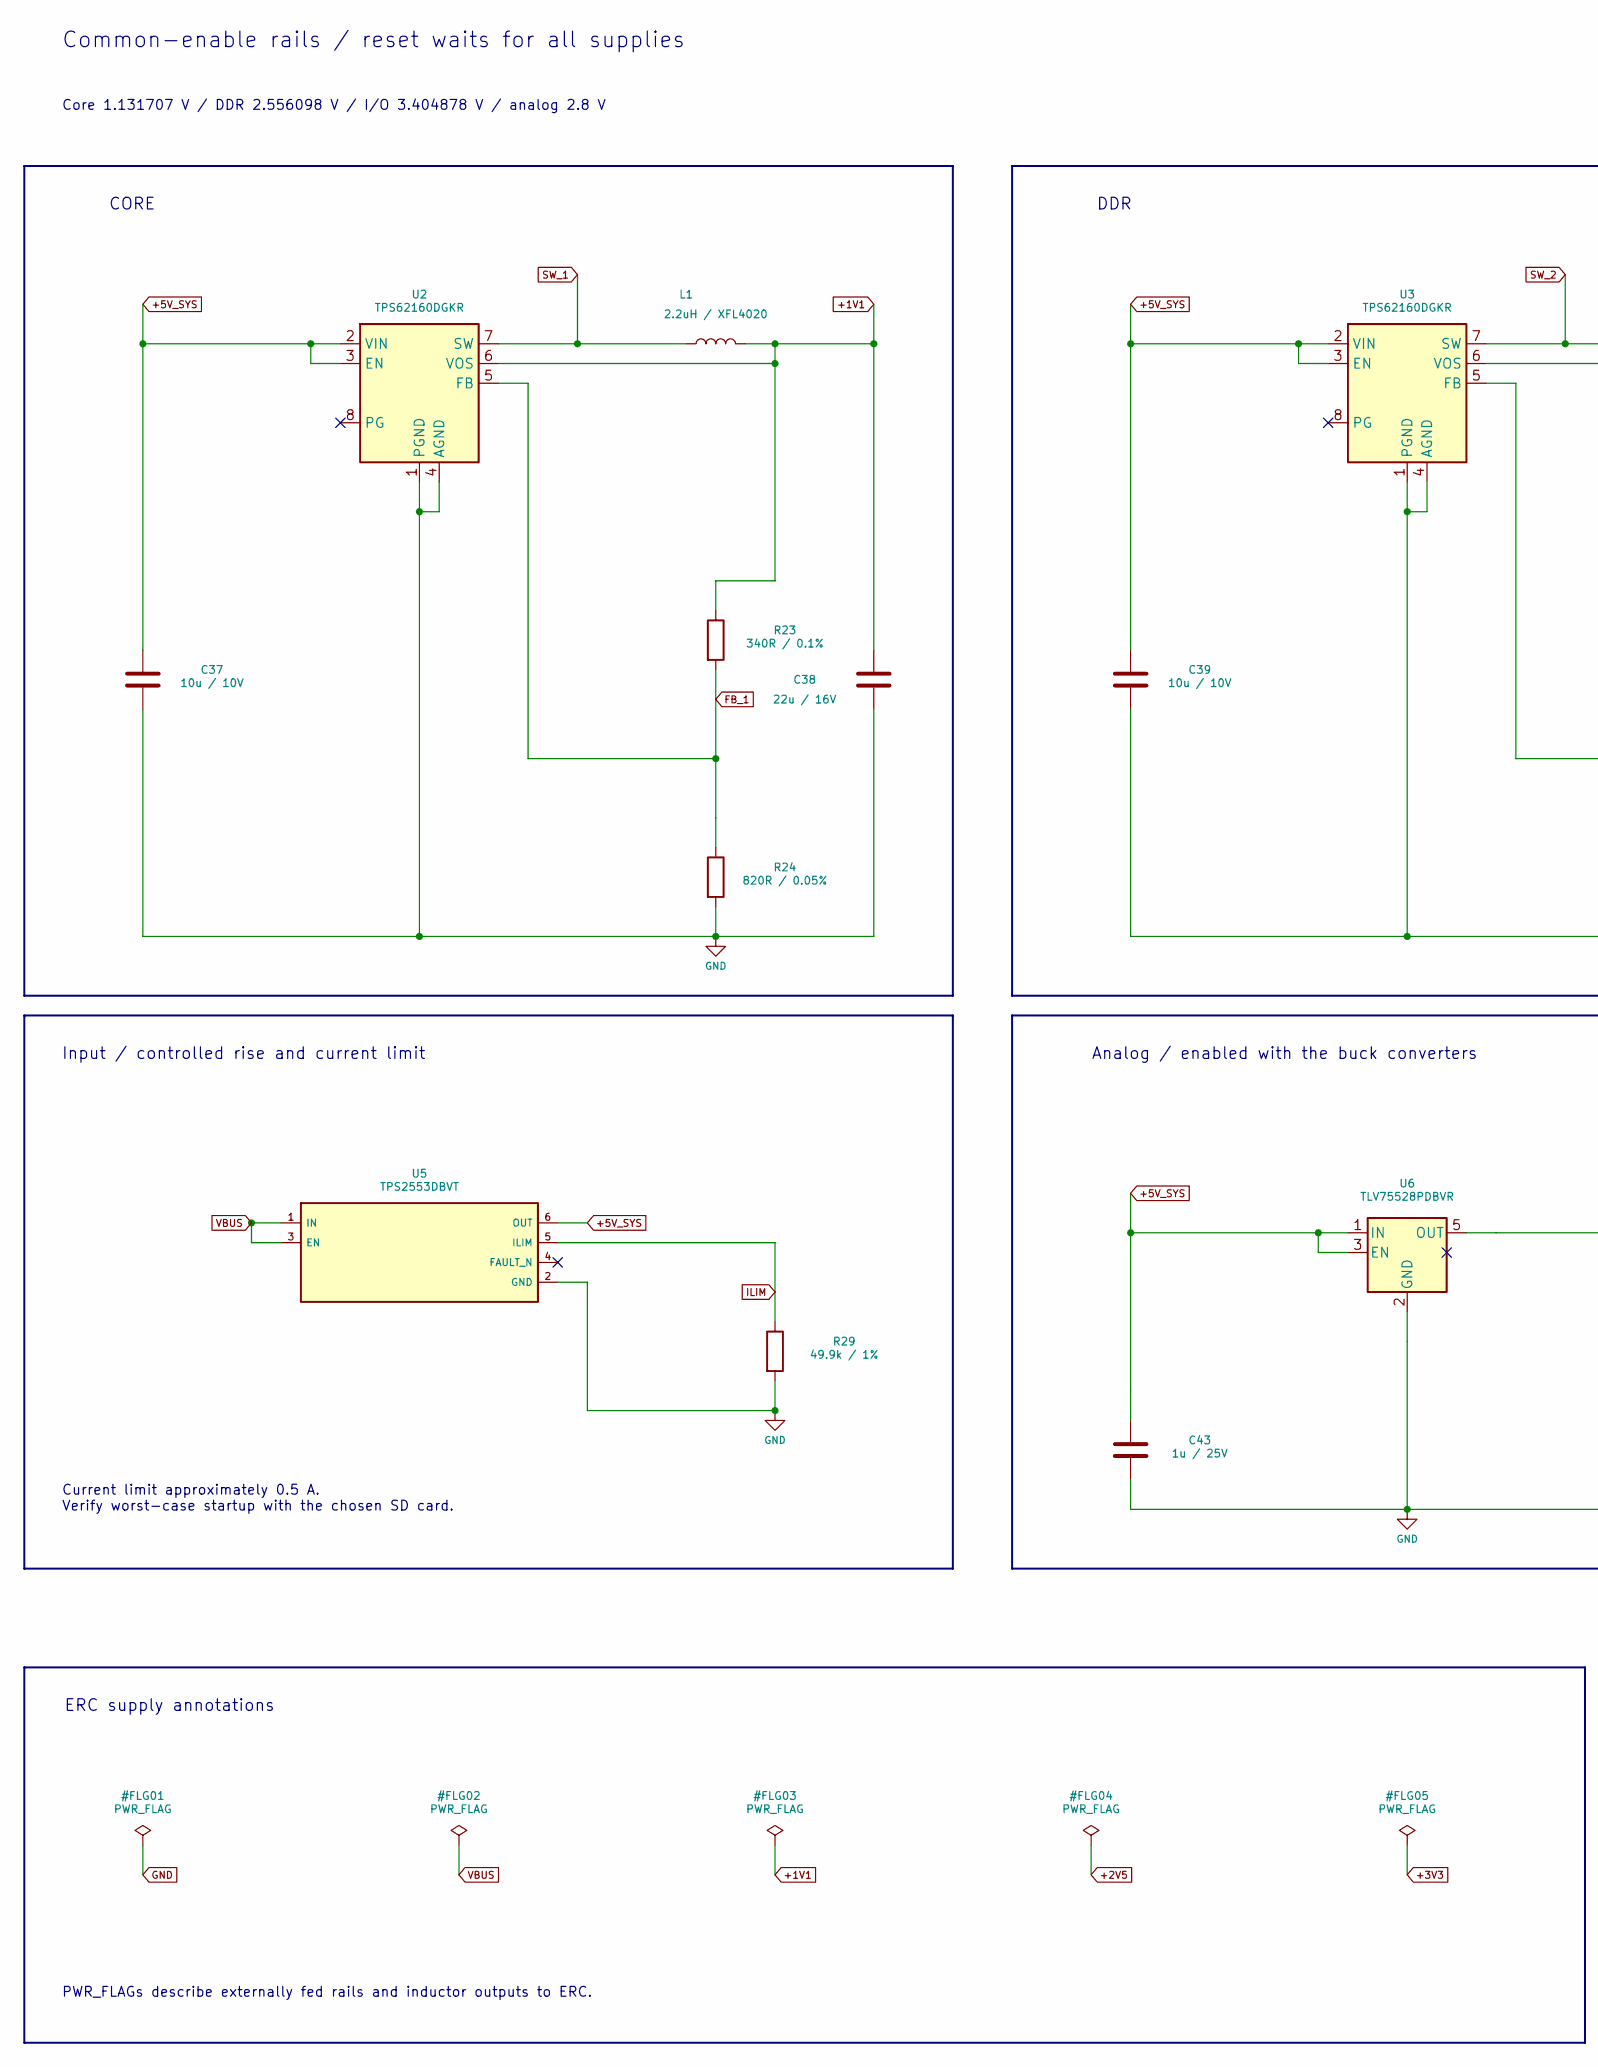
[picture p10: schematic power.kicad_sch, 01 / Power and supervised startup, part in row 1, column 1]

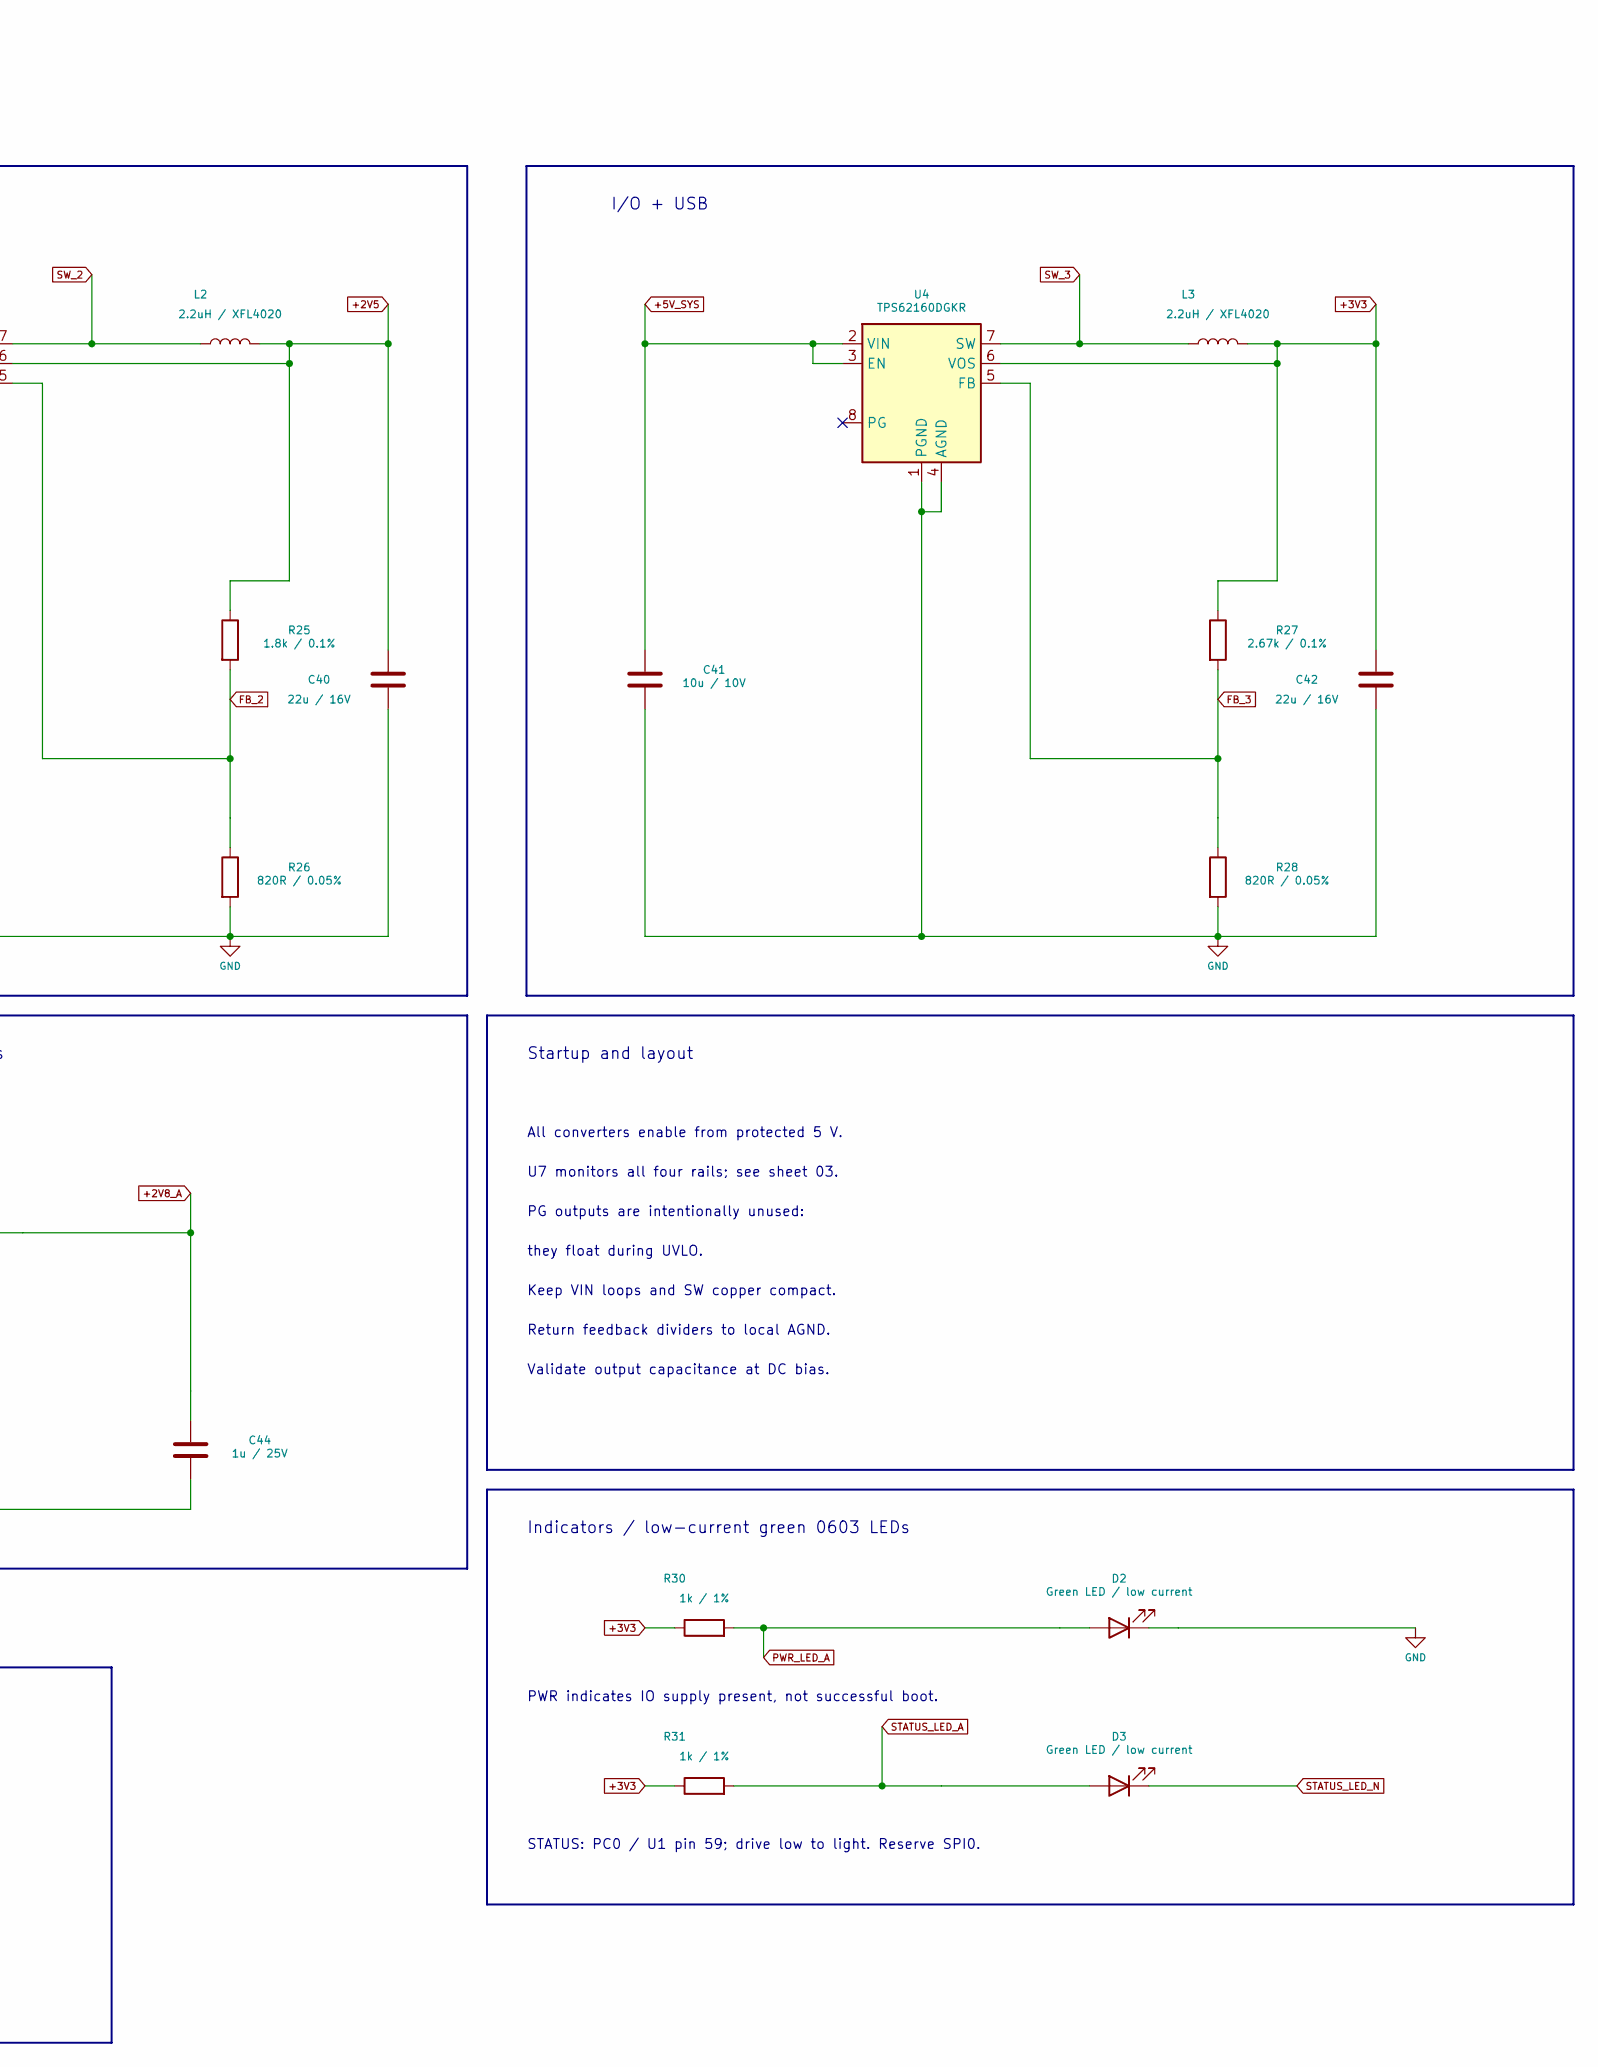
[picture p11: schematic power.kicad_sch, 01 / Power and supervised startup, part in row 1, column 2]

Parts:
C37, C39, C41: 10u / 10V; C_0805_2012Metric; MPN C2012X5R1A106M085AB
C38, C40, C42: 22u / 16V; C_0805_2012Metric; MPN CL21A226MOCLRNC
C43, C44: 1u / 25V; C_0603_1608Metric; MPN C1608X7R1E105K080AB
D2, D3: Green LED / low current; LED_0603_1608Metric; MPN APT1608LZGCK
L1, L2, L3: 2.2uH / XFL4020; L_Coilcraft_XxL4020; MPN XFL4020-222MEC
R23: 340R / 0.1%; R_0603_1608Metric; MPN RT0603BRD07340RL
R24, R26, R28: 820R / 0.05%; R_0603_1608Metric; MPN RG1608N-821-W-T1
R25: 1.8k / 0.1%; R_0603_1608Metric; MPN RG1608P-182-B-T5
R27: 2.67k / 0.1%; R_0603_1608Metric; MPN RG1608P-2671-B-T5
R29: 49.9k / 1%; R_0603_1608Metric; MPN RC0603FR-0749K9L
R30, R31: 1k / 1%; R_0603_1608Metric; MPN RC0603FR-071KL
U2, U3, U4: TPS62160DGKR; MSOP-8_3x3mm_P0.65mm; MPN TPS62160DGKR
U5: TPS2553DBVT; SOT-23-6; MPN TPS2553DBVT
U6: TLV75528PDBVR; SOT-23-5; MPN TLV75528PDBVR

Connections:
+1V1: C38.1, L1.2, R23.1, U2.6 (VOS); also elsewhere on the board
+2V5: C40.1, L2.2, R25.1, U3.6 (VOS); also elsewhere on the board
+2V8_A: C44.1, U6.5 (OUT); also elsewhere on the board
+3V3: C42.1, L3.2, R27.1, R30.1, R31.1, U4.6 (VOS); also elsewhere on the board
+5V_SYS: C37.1, C39.1, C41.1, C43.1, U2.2 (VIN), U2.3 (EN), U3.2 (VIN), U3.3 (EN), U4.2 (VIN), U4.3 (EN), U5.6 (OUT), U6.1 (IN), U6.3 (EN)
FB_1: R23.2, R24.1, U2.5 (FB)
FB_2: R25.2, R26.1, U3.5 (FB)
FB_3: R27.2, R28.1, U4.5 (FB)
GND: C37.2, C38.2, C39.2, C40.2, C41.2, C42.2, C43.2, C44.2, D2.1 (K), R24.2, R26.2, R28.2, R29.2, U2.1 (PGND), U2.4 (AGND), U3.1 (PGND), U3.4 (AGND), U4.1 (PGND), U4.4 (AGND), U5.2 (GND), U6.2 (GND); also elsewhere on the board
ILIM: R29.1, U5.5 (ILIM)
PWR_LED_A: D2.2 (A), R30.2
STATUS_LED_A: D3.2 (A), R31.2
STATUS_LED_N: D3.1 (K); also elsewhere on the board
SW_1: L1.1, U2.7 (SW)
SW_2: L2.1, U3.7 (SW)
SW_3: L3.1, U4.7 (SW)
VBUS: U5.1 (IN), U5.3 (EN); also elsewhere on the board

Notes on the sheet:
ERC supply annotations
Common-enable rails / reset waits for all supplies
Core 1.131707 V / DDR 2.556098 V / I/O 3.404878 V / analog 2.8 V
CORE
DDR
I/O + USB
Input / controlled rise and current limit
Current limit approximately 0.5 A. Verify worst-case startup with the chosen SD card.
Analog / enabled with the buck converters
Startup and layout
All converters enable from protected 5 V.
U7 monitors all four rails; see sheet 03.
PG outputs are intentionally unused:
they float during UVLO.
Keep VIN loops and SW copper compact.
Return feedback dividers to local AGND.
Validate output capacitance at DC bias.
PWR_FLAGs describe externally fed rails and inductor outputs to ERC.
Indicators / low-current green 0603 LEDs
PWR indicates IO supply present, not successful boot.
STATUS: PC0 / U1 pin 59; drive low to light. Reserve SPI0.

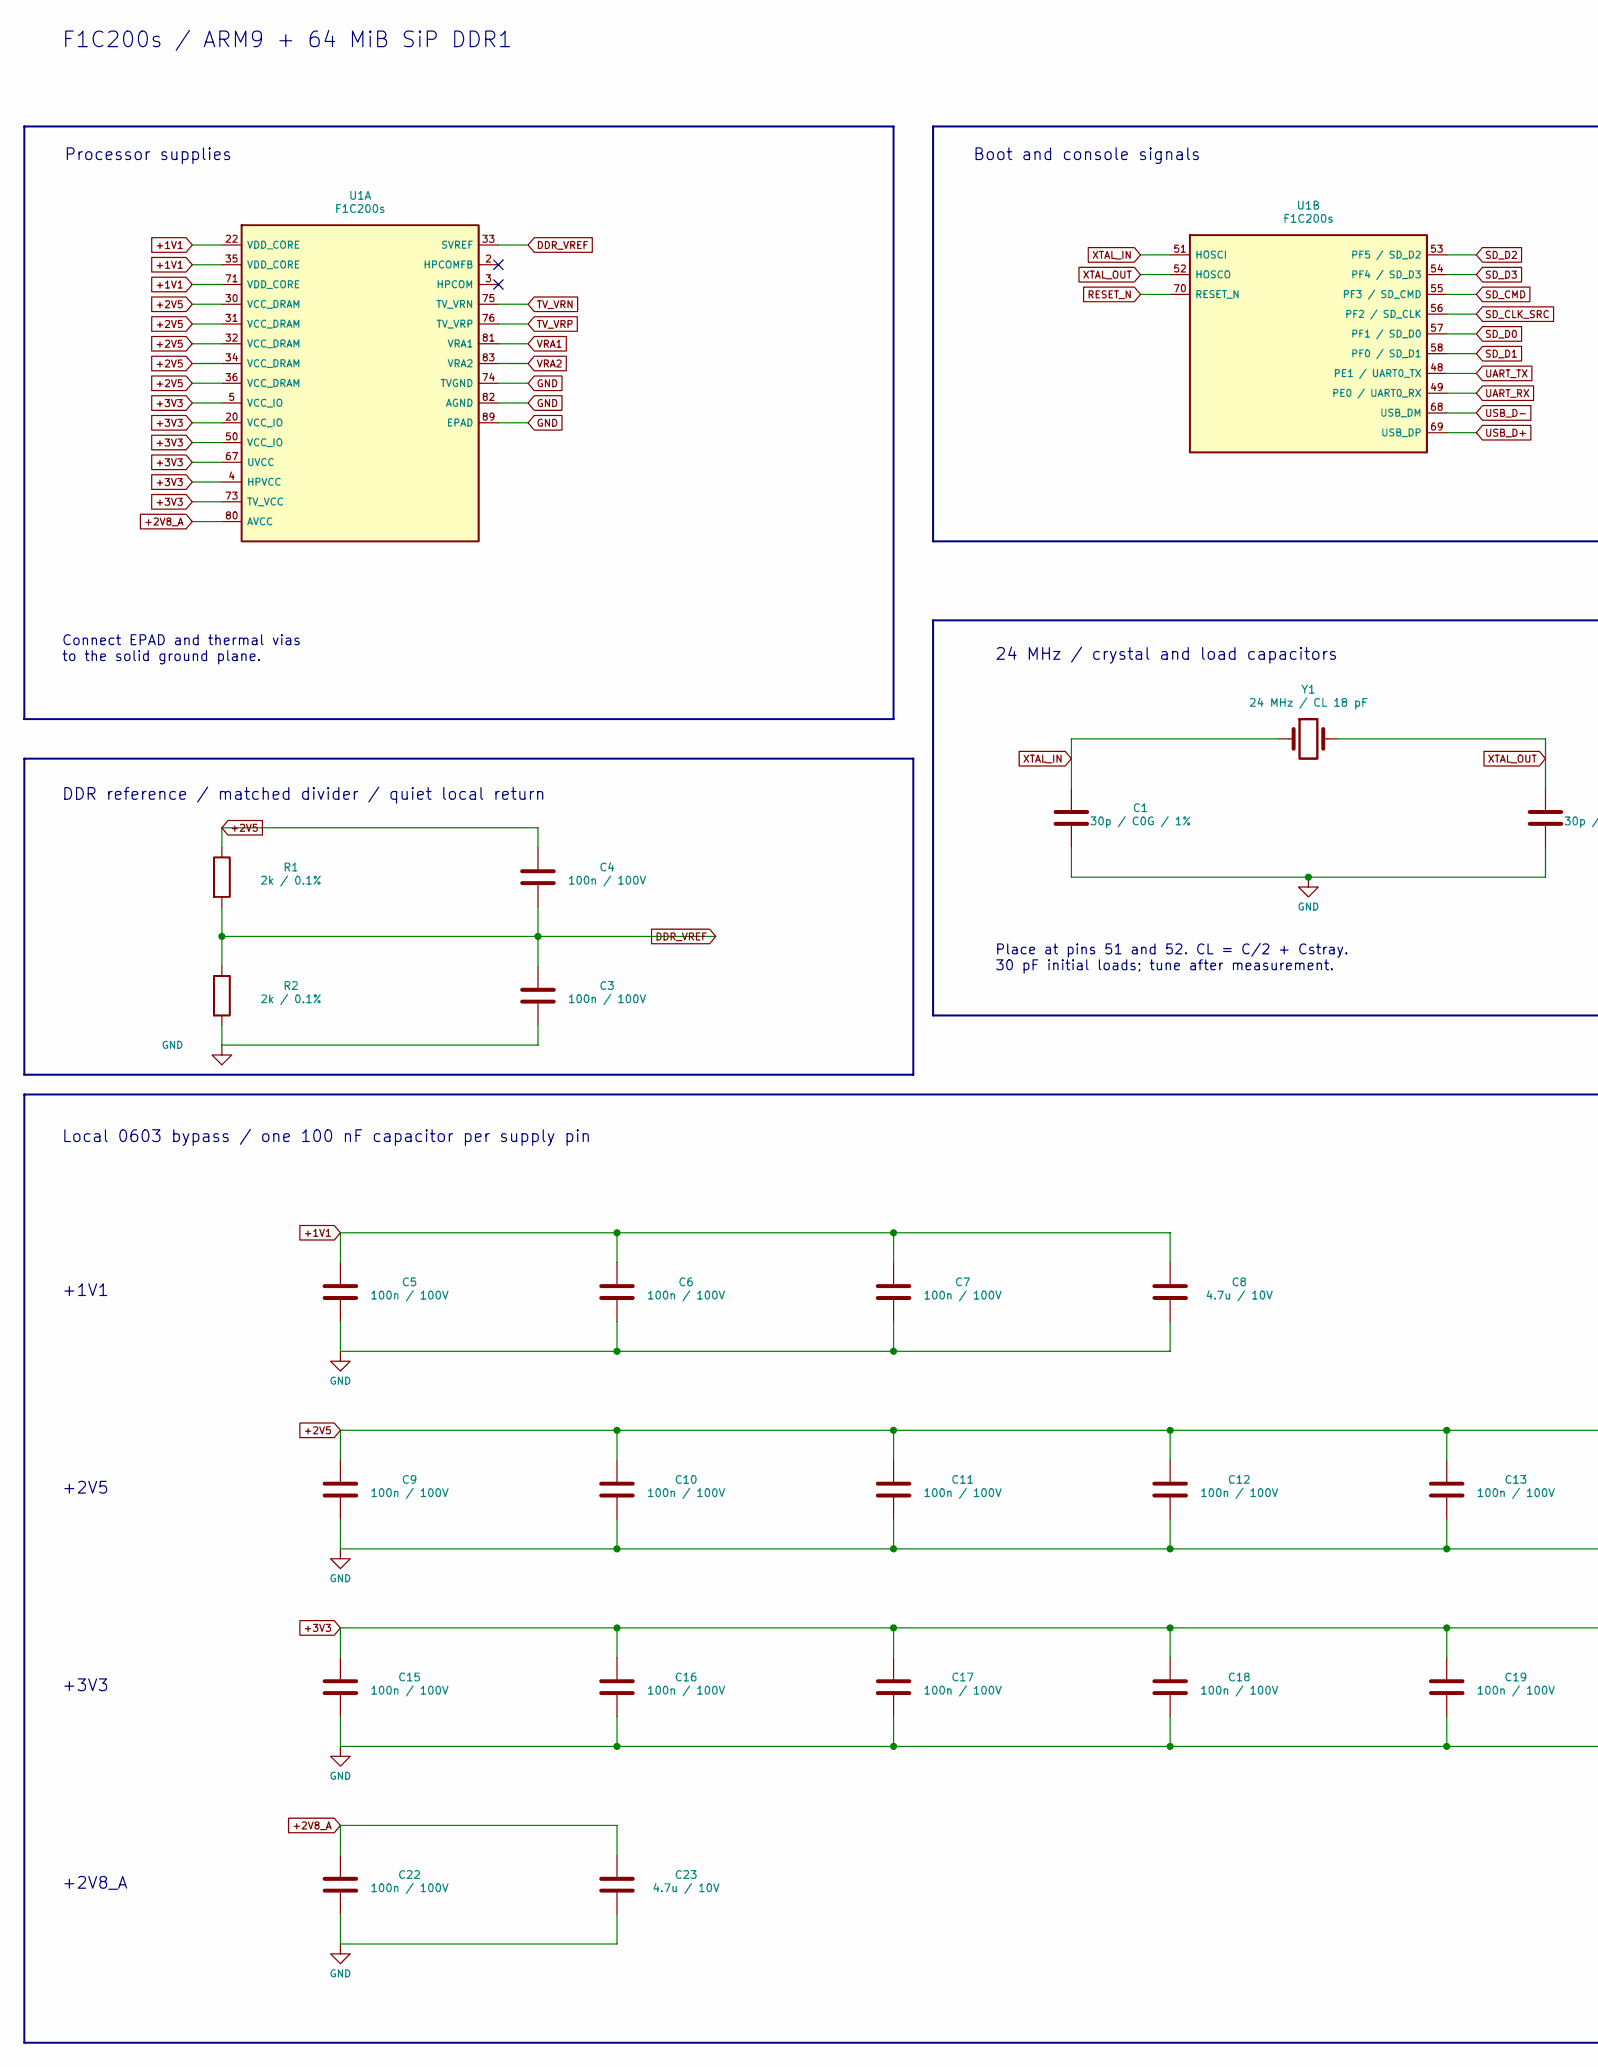
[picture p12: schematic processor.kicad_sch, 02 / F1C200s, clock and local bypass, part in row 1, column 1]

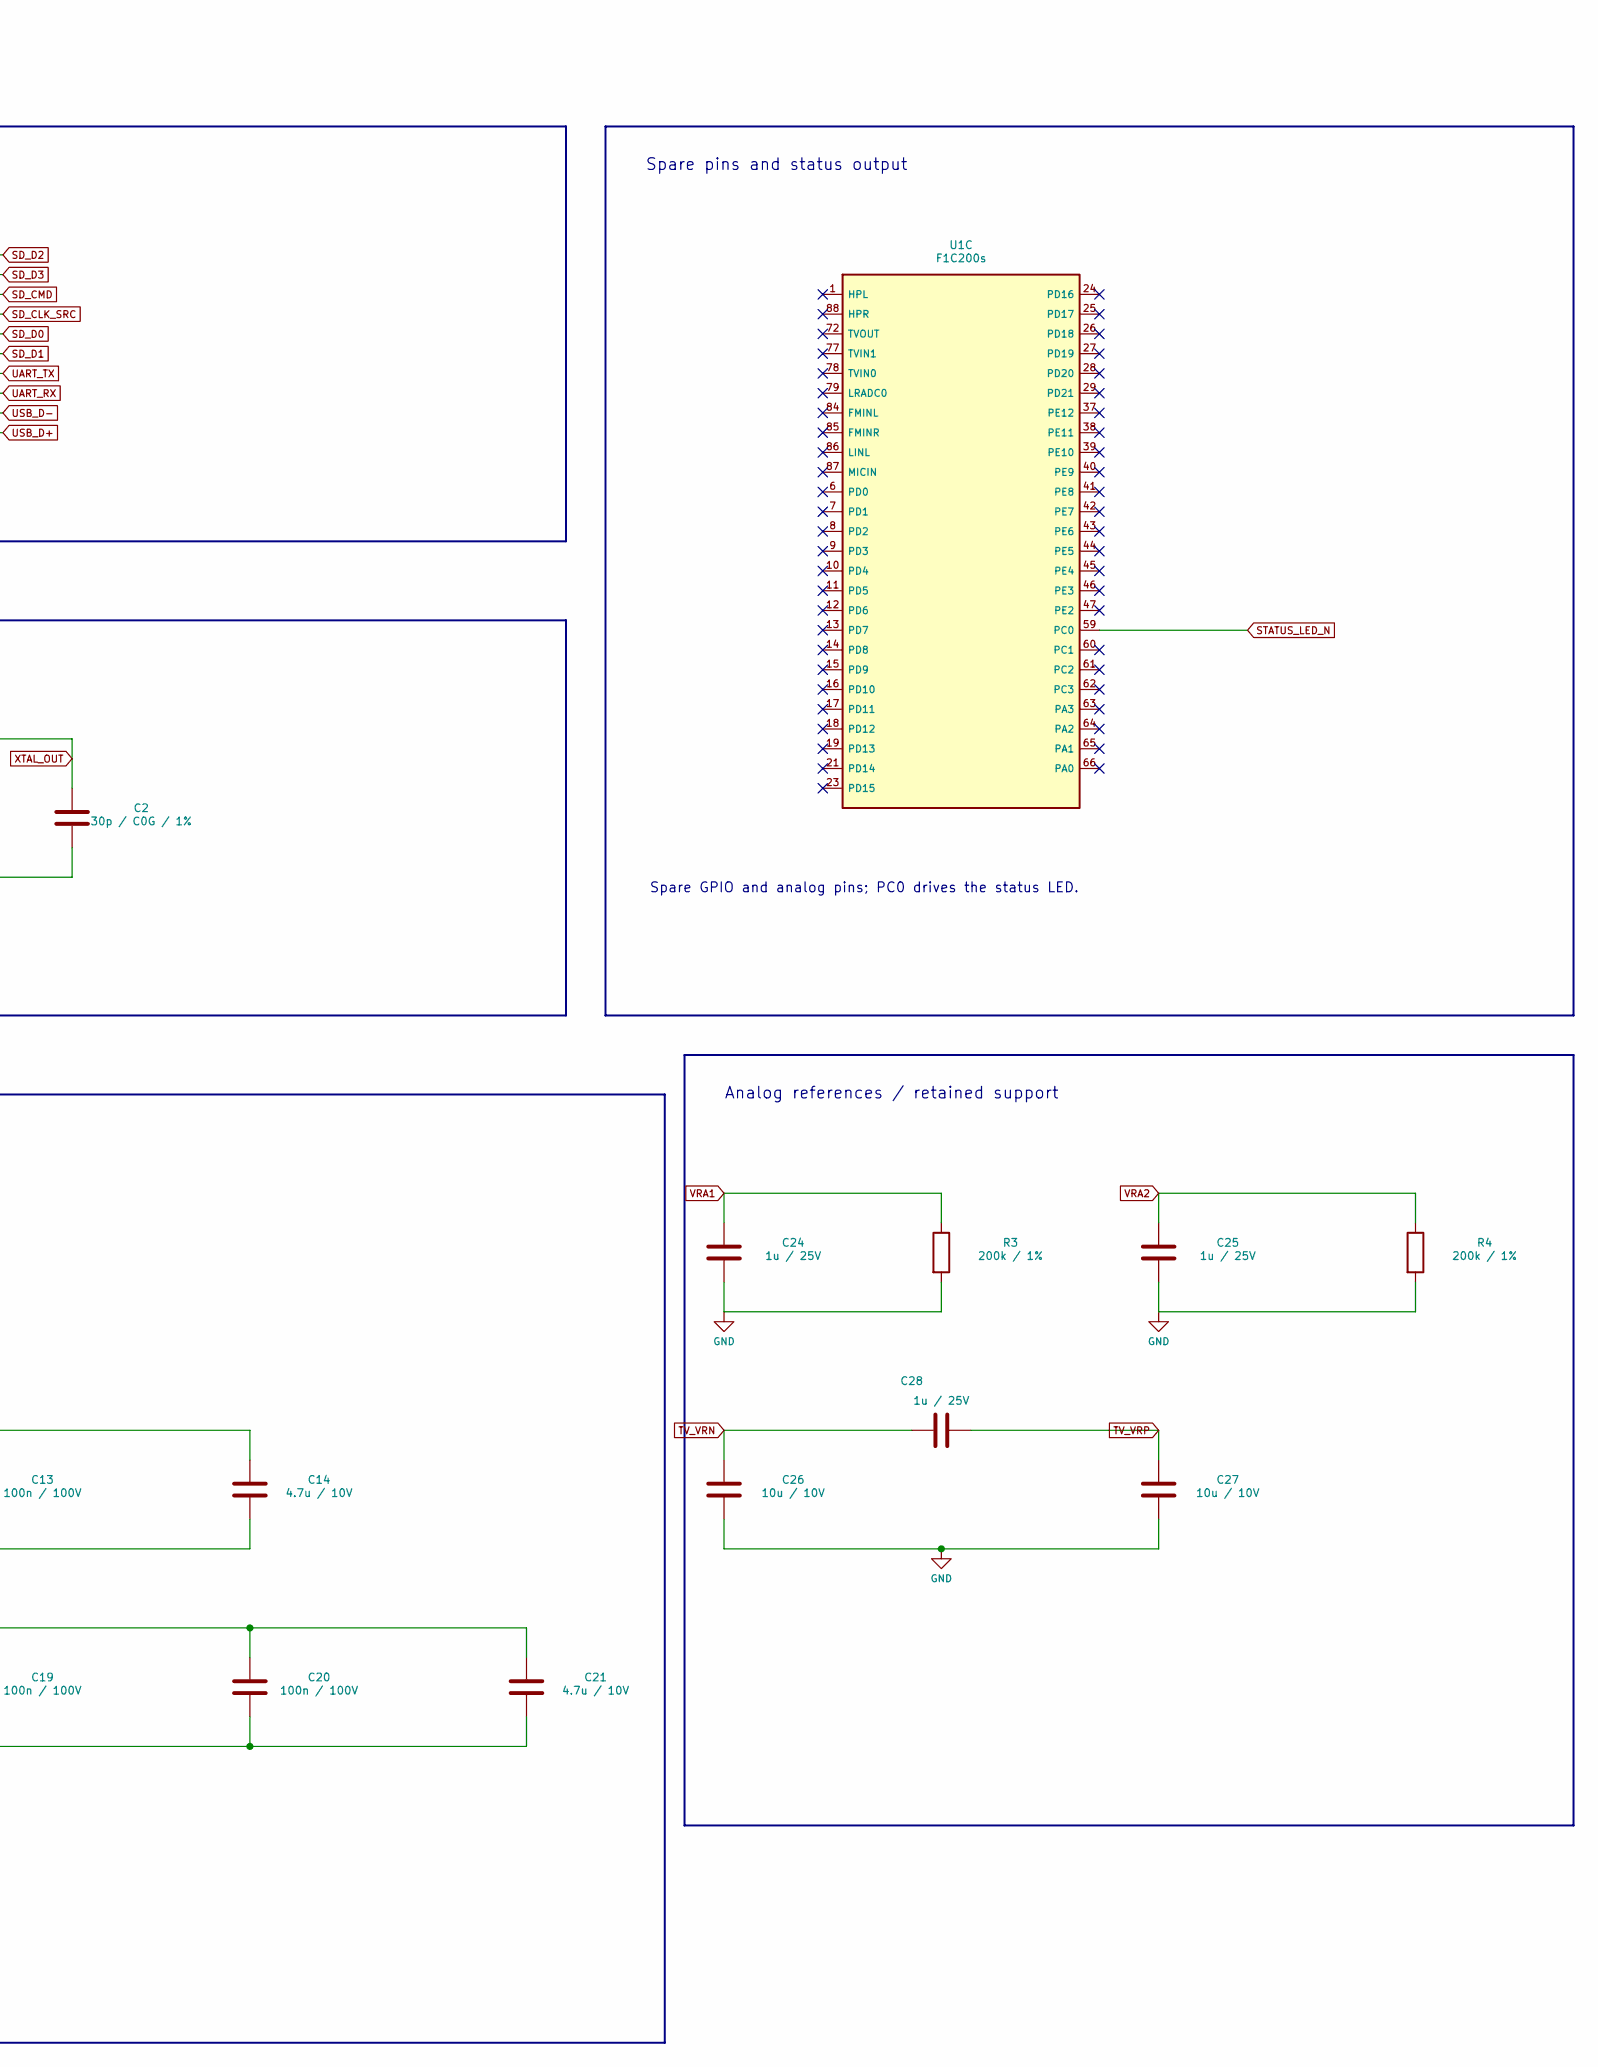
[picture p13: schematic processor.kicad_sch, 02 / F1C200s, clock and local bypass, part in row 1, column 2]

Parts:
C1, C2: 30p / C0G / 1%; C_0603_1608Metric; MPN C0603C300F5GACTU
C3, C4, C5, C6, C7, C9, C10, C11, C12, C13, C15, C16, C17, C18, C19, C20, C22: 100n / 100V; C_0603_1608Metric; MPN GRM188R72A104KA35D
C8, C14, C21, C23: 4.7u / 10V; C_0603_1608Metric; MPN GRM188R61A475KE15D
C24, C25, C28: 1u / 25V; C_0603_1608Metric; MPN C1608X7R1E105K080AB
C26, C27: 10u / 10V; C_0805_2012Metric; MPN C2012X5R1A106M085AB
R1, R2: 2k / 0.1%; R_0603_1608Metric; MPN RG1608P-202-B-T5
R3, R4: 200k / 1%; R_0603_1608Metric; MPN RC0603FR-07200KL
U1: F1C200s; F1C200s_QFN88_10x10_P0.4_EP6.74; MPN F1C200S
Y1: 24 MHz / CL 18 pF; Raltron_H130A_5032; MPN H130A-24.000-18-2030-EXT-TR

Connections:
+1V1: C5.1, C6.1, C7.1, C8.1, U1.22 (VDD_CORE), U1.35 (VDD_CORE), U1.71 (VDD_CORE); also elsewhere on the board
+2V5: C4.1, C9.1, C10.1, C11.1, C12.1, C13.1, C14.1, R1.1, U1.30 (VCC_DRAM), U1.31 (VCC_DRAM), U1.32 (VCC_DRAM), U1.34 (VCC_DRAM), U1.36 (VCC_DRAM); also elsewhere on the board
+2V8_A: C22.1, C23.1, U1.80 (AVCC); also elsewhere on the board
+3V3: C15.1, C16.1, C17.1, C18.1, C19.1, C20.1, C21.1, U1.4 (HPVCC), U1.5 (VCC_IO), U1.20 (VCC_IO), U1.50 (VCC_IO), U1.67 (UVCC), U1.73 (TV_VCC); also elsewhere on the board
DDR_VREF: C3.1, C4.2, R1.2, R2.1, U1.33 (SVREF)
GND: C1.2, C2.2, C3.2, C5.2, C6.2, C7.2, C8.2, C9.2, C10.2, C11.2, C12.2, C13.2, C14.2, C15.2, C16.2, C17.2, C18.2, C19.2, C20.2, C21.2, C22.2, C23.2, C24.2, C25.2, C26.2, C27.2, R2.2, R3.2, R4.2, U1.74 (TVGND), U1.82 (AGND), U1.89 (EPAD); also elsewhere on the board
RESET_N: U1.70 (RESET_N); also elsewhere on the board
SD_CLK_SRC: U1.56 (PF2 / SD_CLK); also elsewhere on the board
SD_CMD: U1.55 (PF3 / SD_CMD); also elsewhere on the board
SD_D0: U1.57 (PF1 / SD_D0); also elsewhere on the board
SD_D1: U1.58 (PF0 / SD_D1); also elsewhere on the board
SD_D2: U1.53 (PF5 / SD_D2); also elsewhere on the board
SD_D3: U1.54 (PF4 / SD_D3); also elsewhere on the board
STATUS_LED_N: U1.59 (PC0); also elsewhere on the board
TV_VRN: C26.1, C28.2, U1.75 (TV_VRN)
TV_VRP: C27.1, C28.1, U1.76 (TV_VRP)
UART_RX: U1.49 (PE0 / UART0_RX); also elsewhere on the board
UART_TX: U1.48 (PE1 / UART0_TX); also elsewhere on the board
USB_D+: U1.69 (USB_DP); also elsewhere on the board
USB_D-: U1.68 (USB_DM); also elsewhere on the board
VRA1: C24.1, R3.1, U1.81 (VRA1)
VRA2: C25.1, R4.1, U1.83 (VRA2)
XTAL_IN: C1.1, U1.51 (HOSCI), Y1.1
XTAL_OUT: C2.1, U1.52 (HOSCO), Y1.2

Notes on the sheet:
Processor supplies
Boot and console signals
Spare pins and status output
F1C200s / ARM9 + 64 MiB SiP DDR1
Spare GPIO and analog pins; PC0 drives the status LED.
Connect EPAD and thermal vias to the solid ground plane.
24 MHz / crystal and load capacitors
Place at pins 51 and 52. CL = C/2 + Cstray. 30 pF initial loads; tune after measurement.
DDR reference / matched divider / quiet local return
Local 0603 bypass / one 100 nF capacitor per supply pin
+1V1
+2V5
+3V3
+2V8_A
Analog references / retained support

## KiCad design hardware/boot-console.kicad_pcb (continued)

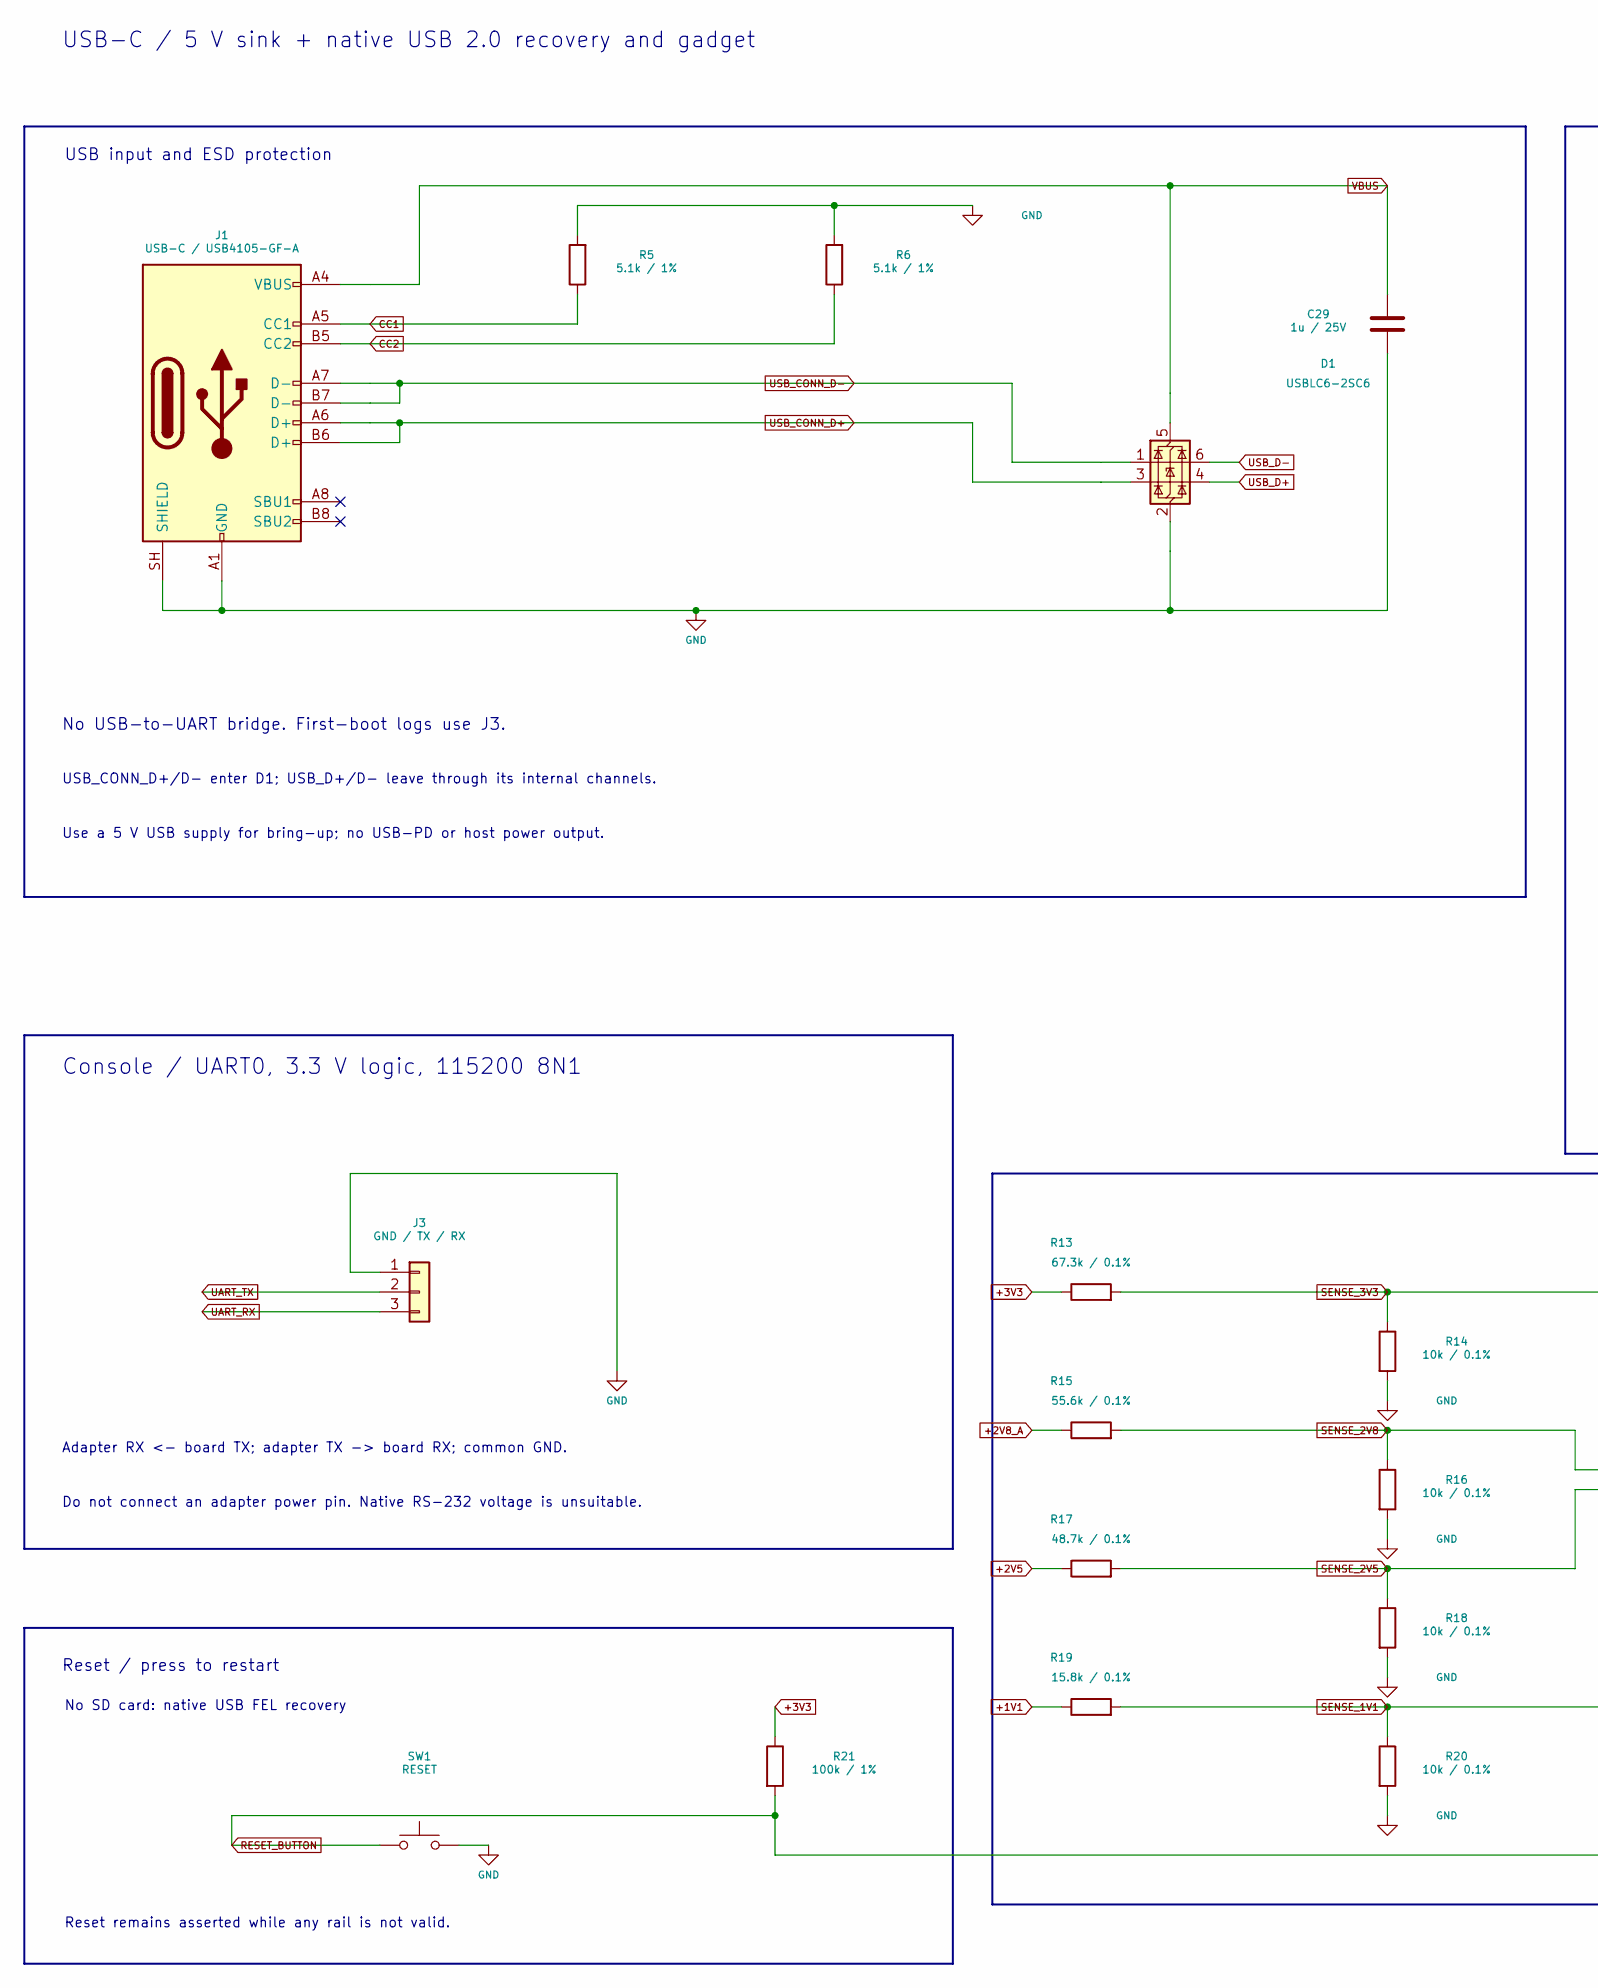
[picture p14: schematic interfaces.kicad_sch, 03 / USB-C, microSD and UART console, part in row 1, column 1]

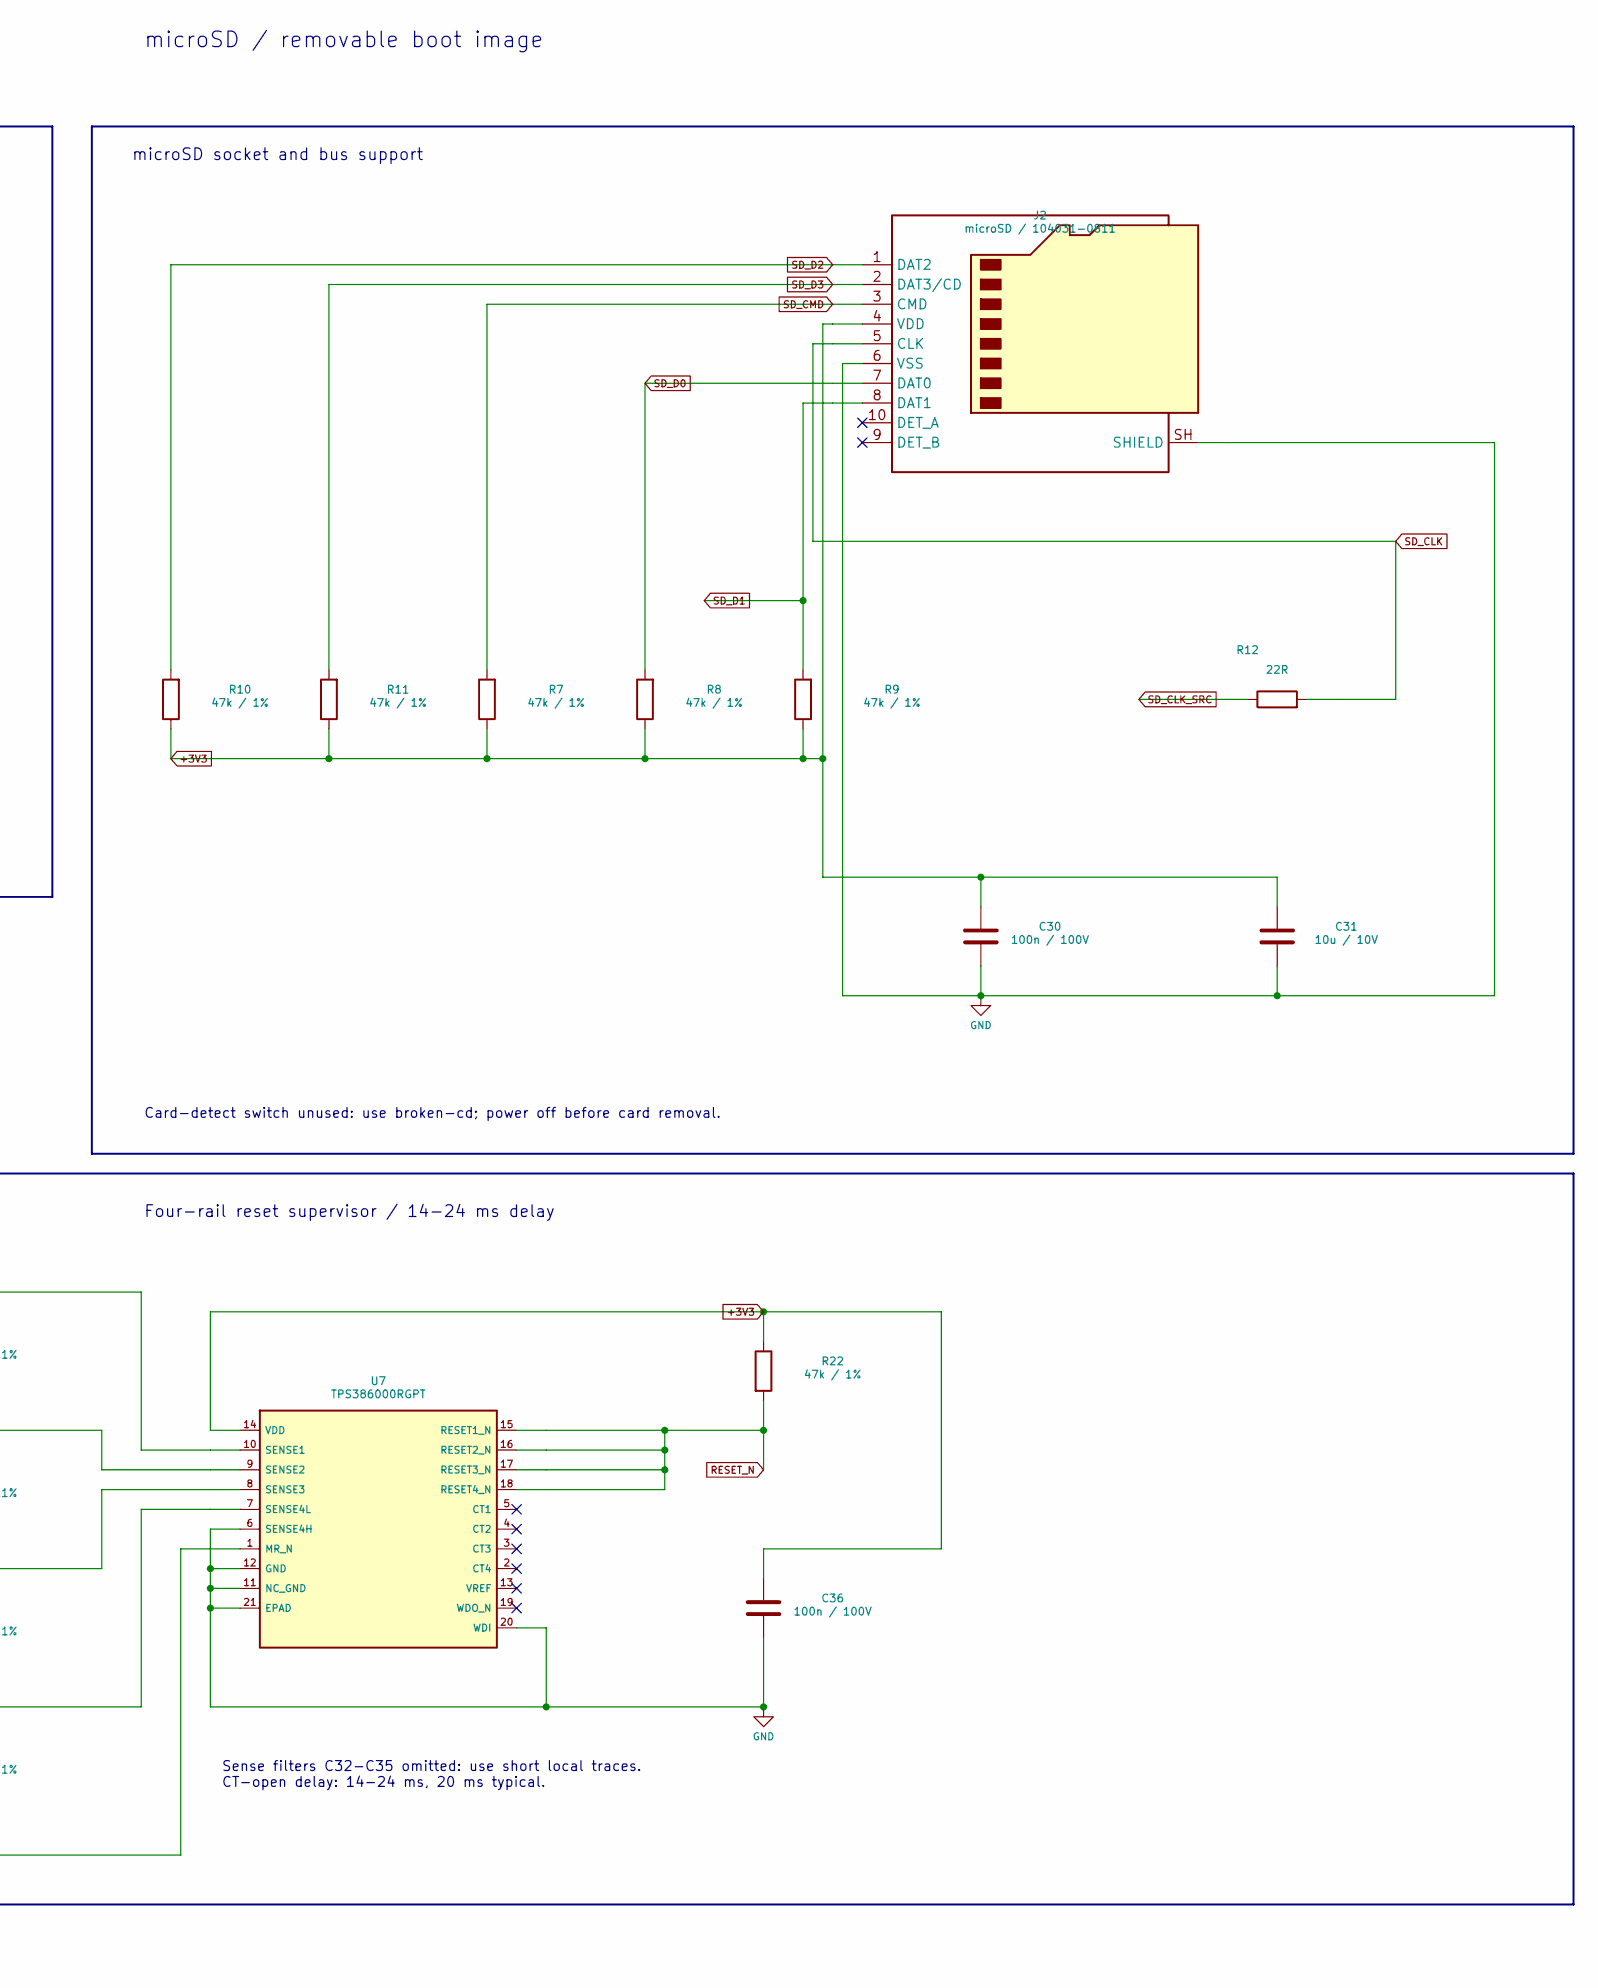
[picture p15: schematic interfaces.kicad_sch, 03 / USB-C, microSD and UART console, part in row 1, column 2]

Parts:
C29: 1u / 25V; C_0603_1608Metric; MPN C1608X7R1E105K080AB
C30, C36: 100n / 100V; C_0603_1608Metric; MPN GRM188R72A104KA35D
C31: 10u / 10V; C_0805_2012Metric; MPN C2012X5R1A106M085AB
D1: USBLC6-2SC6; SOT-23-6; MPN USBLC6-2SC6
J1: USB-C / USB4105-GF-A; USB_C_Receptacle_GCT_USB4105-xx-A_16P_TopMnt_Horizontal; MPN USB4105-GF-A
J2: microSD / 104031-0811; microSD_HC_Molex_104031-0811; MPN 104031-0811
J3: GND / TX / RX; PinHeader_1x03_P2.54mm_Vertical; MPN TSW-103-07-G-S
R5, R6: 5.1k / 1%; R_0603_1608Metric; MPN CR0603-FX-5101ELF
R7, R8, R9, R10, R11, R22: 47k / 1%; R_0603_1608Metric; MPN RC0603FR-0747KL
R12: 22R; R_0603_1608Metric; MPN CRCW060322R0FKEA
R13: 67.3k / 0.1%; R_0603_1608Metric; MPN RN73R1JTTD6732B25
R14, R16, R20: 10k / 0.1%; R_0603_1608Metric; MPN RT0603BRD0710KL
R15: 55.6k / 0.1%; R_0603_1608Metric; MPN TNPW060355K6BEEA
R17: 48.7k / 0.1%; R_0603_1608Metric; MPN RQ73C1J48K7BTDF
R18: 10k / 0.1%; R_0603_1608Metric; MPN TNPW060310K0BYEN
R19: 15.8k / 0.1%; R_0603_1608Metric; MPN RG1608P-1582-B-T5
R21: 100k / 1%; R_0603_1608Metric; MPN RC0603FR-07100KL
SW1: RESET; SW_SPST_TL3305A; MPN TL3305AF160QG
U7: TPS386000RGPT; TPS386000_RGP20_EP2.8; MPN TPS386000RGPT

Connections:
+1V1: R19.1; also elsewhere on the board
+2V5: R17.1; also elsewhere on the board
+2V8_A: R15.1; also elsewhere on the board
+3V3: C30.1, C31.1, C36.1, J2.4 (VDD), R7.1, R8.1, R9.1, R10.1, R11.1, R13.1, R21.1, R22.1, U7.14 (VDD); also elsewhere on the board
CC1: J1.A5 (CC1), R5.1
CC2: J1.B5 (CC2), R6.1
GND: C29.2, C30.2, C31.2, C36.2, D1.2 (GND), J1.A1 (GND), J1.A12 (GND), J1.B1 (GND), J1.B12 (GND), J1.SH (SHIELD), J2.6 (VSS), J2.SH (SHIELD), J3.1, R5.2, R6.2, R14.2, R16.2, R18.2, R20.2, SW1.2, U7.6 (SENSE4H), U7.11 (NC_GND), U7.12 (GND), U7.20 (WDI), U7.21 (EPAD); also elsewhere on the board
RESET_BUTTON: R21.2, SW1.1, U7.1 (MR_N)
RESET_N: R22.2, U7.15 (RESET1_N), U7.16 (RESET2_N), U7.17 (RESET3_N), U7.18 (RESET4_N); also elsewhere on the board
SD_CLK: J2.5 (CLK), R12.2
SD_CLK_SRC: R12.1; also elsewhere on the board
SD_CMD: J2.3 (CMD), R7.2; also elsewhere on the board
SD_D0: J2.7 (DAT0), R8.2; also elsewhere on the board
SD_D1: J2.8 (DAT1), R9.2; also elsewhere on the board
SD_D2: J2.1 (DAT2), R10.2; also elsewhere on the board
SD_D3: J2.2 (DAT3/CD), R11.2; also elsewhere on the board
SENSE_1V1: R19.2, R20.1, U7.7 (SENSE4L)
SENSE_2V5: R17.2, R18.1, U7.8 (SENSE3)
SENSE_2V8: R15.2, R16.1, U7.9 (SENSE2)
SENSE_3V3: R13.2, R14.1, U7.10 (SENSE1)
UART_RX: J3.3; also elsewhere on the board
UART_TX: J3.2; also elsewhere on the board
USB_CONN_D+: D1.3 (I/O2), J1.A6 (D+), J1.B6 (D+)
USB_CONN_D-: D1.1 (I/O1), J1.A7 (D-), J1.B7 (D-)
USB_D+: D1.4 (I/O2); also elsewhere on the board
USB_D-: D1.6 (I/O1); also elsewhere on the board
VBUS: C29.1, D1.5 (VBUS), J1.A4 (VBUS), J1.A9 (VBUS), J1.B4 (VBUS), J1.B9 (VBUS); also elsewhere on the board

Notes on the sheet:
USB input and ESD protection
microSD socket and bus support
USB-C / 5 V sink + native USB 2.0 recovery and gadget
No USB-to-UART bridge. First-boot logs use J3.
USB_CONN_D+/D- enter D1; USB_D+/D- leave through its internal channels.
Use a 5 V USB supply for bring-up; no USB-PD or host power output.
microSD / removable boot image
Card-detect switch unused: use broken-cd; power off before card removal.
Console / UART0, 3.3 V logic, 115200 8N1
Adapter RX <- board TX; adapter TX -> board RX; common GND.
Do not connect an adapter power pin. Native RS-232 voltage is unsuitable.
Reset / press to restart
No SD card: native USB FEL recovery
Reset remains asserted while any rail is not valid.
Four-rail reset supervisor / 14-24 ms delay
Sense filters C32-C35 omitted: use short local traces. CT-open delay: 14-24 ms, 20 ms typical.

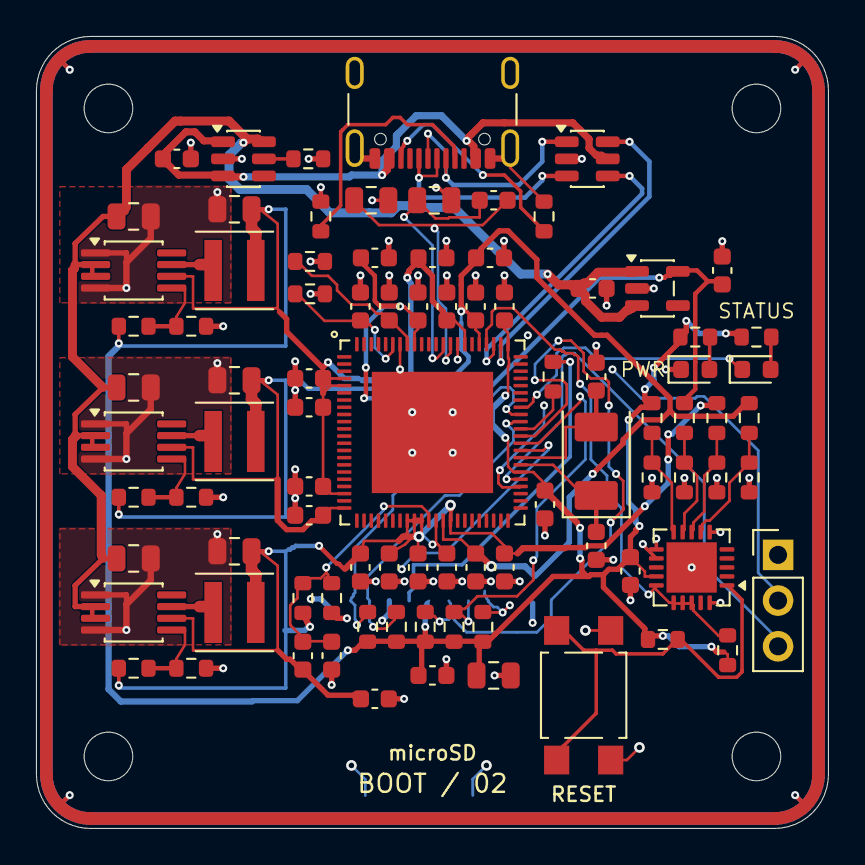
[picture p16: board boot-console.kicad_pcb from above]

Board: 4 copper layers, 44.0 x 44.0 mm, 93 parts (1 on the bottom side), 45 nets.

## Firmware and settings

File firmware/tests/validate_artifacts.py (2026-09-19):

#!/usr/bin/env python3
"""Validate resolved Buildroot firmware artifacts for the Boot Console board."""

from __future__ import annotations

import argparse
import os
import re
import shutil
import struct
import subprocess
import sys
import tempfile
import time
from pathlib import Path


def fail(message: str) -> None:
    raise AssertionError(message)


def one(paths: list[Path], description: str) -> Path:
    paths = [path for path in paths if path.is_file()]
    if len(paths) != 1:
        fail(f"expected one {description}, found {len(paths)}: {paths}")
    return paths[0]


def one_dir(paths: list[Path], description: str) -> Path:
    paths = [path for path in paths if path.is_dir()]
    if len(paths) != 1:
        fail(f"expected one {description}, found {len(paths)}: {paths}")
    return paths[0]


def config(path: Path) -> dict[str, str]:
    values: dict[str, str] = {}
    for line in path.read_text().splitlines():
        if match := re.fullmatch(r"((?:CONFIG_|BR2_)[A-Za-z0-9_]+)=(.*)", line):
            values[match.group(1)] = match.group(2)
        elif match := re.fullmatch(r"# ((?:CONFIG_|BR2_)[A-Za-z0-9_]+) is not set", line):
            values[match.group(1)] = "n"
    return values


def require(cfg: dict[str, str], path: Path, expected: dict[str, str]) -> None:
    wrong = [f"{key}={cfg.get(key, '<missing>')} (expected {value})" for key, value in expected.items() if cfg.get(key) != value]
    if wrong:
        fail(f"{path}: resolved configuration mismatch:\n  " + "\n  ".join(wrong))


def decompile(dtb: Path) -> str:
    output = dtb.parent.parent
    local_candidates = [output / "host/bin/dtc"]
    local_candidates.extend((output / "build").glob("linux-*/scripts/dtc/dtc"))
    dtc = shutil.which("dtc") or next((str(path) for path in local_candidates if path.is_file()), None)
    if not dtc:
        fail("dtc is required in PATH, output/host/bin, or the Linux build tree")
    result = subprocess.run(
        [dtc, "-I", "dtb", "-O", "dts", str(dtb)],
        check=False,
        capture_output=True,
        text=True,
    )
    if result.returncode:
        fail(f"dtc could not decode {dtb}:\n{result.stderr}")
    return result.stdout


def node(dts: str, identifying_property: str) -> str:
    position = dts.find(identifying_property)
    if position < 0:
        fail(f"compiled DTB lacks {identifying_property!r}")
    start = dts.rfind("{", 0, position)
    if start < 0:
        fail(f"cannot locate node containing {identifying_property!r}")
    depth = 0
    for end in range(start, len(dts)):
        if dts[end] == "{":
            depth += 1
        elif dts[end] == "}":
            depth -= 1
            if depth == 0:
                return dts[start : end + 1]
    fail(f"unterminated node containing {identifying_property!r}")
    return ""


def named_node(dts: str, name: str) -> str:
    match = re.search(rf"\b{re.escape(name)}\s*\{{", dts)
    if not match:
        fail(f"compiled DTB lacks node {name!r}")
    start = match.end() - 1
    depth = 0
    for end in range(start, len(dts)):
        if dts[end] == "{":
            depth += 1
        elif dts[end] == "}":
            depth -= 1
            if depth == 0:
                return dts[start : end + 1]
    fail(f"unterminated compiled DTB node {name!r}")
    return ""


def phandle(text: str) -> str:
    match = re.search(r"\bphandle = <(0x[0-9a-f]+)>;", text)
    if not match:
        fail("compiled DTB node lacks a phandle")
    return match.group(1)


def check_dtb(dtb: Path) -> None:
    dts = decompile(dtb)
    for required in (
        'model = "Clark\'s Board"',
        'stdout-path = "serial0:115200n8"',
        'device_type = "memory"',
        'reg = <0x80000000 0x4000000>',
    ):
        if required not in dts:
            fail(f"{dtb}: compiled tree lacks {required!r}")

    mmc = node(dts, "broken-cd;")
    for required in ("bus-width = <0x01>", "max-frequency = <0xbebc20>", 'status = "okay"'):
        if required not in mmc:
            fail(f"{dtb}: enabled SDC0 node lacks {required!r}")

    regulator = named_node(dts, "regulator-vcc3v3")
    for required in ("regulator-min-microvolt = <0x33f44e>", "regulator-max-microvolt = <0x33f44e>"):
        if required not in regulator:
            fail(f"{dtb}: fixed I/O rail lacks exact nominal setting {required!r}")

    supply = phandle(regulator)
    pio = named_node(dts, "pinctrl@1c20800")
    for bank in ("c", "e", "f"):
        required = f"vcc-p{bank}-supply = <{supply}>"
        if required not in pio:
            fail(f"{dtb}: pin bank P{bank.upper()} does not reference the fixed I/O rail")

    uart_pin_match = re.search(r'pins = "PE0(?:\\0|", ")PE1"', dts)
    if not uart_pin_match:
        fail(f"{dtb}: compiled tree lacks the PE0/PE1 pin group")
    uart_pins = node(dts, uart_pin_match.group(0))
    if 'function = "uart0"' not in uart_pins:
        fail(f"{dtb}: PE0/PE1 are not resolved to UART0")
    uart = named_node(dts, "serial@1c25000")
    if 'status = "okay"' not in uart or f"pinctrl-0 = <{phandle(uart_pins)}>" not in uart:
        fail(f"{dtb}: enabled UART0 does not select the PE0/PE1 pinmux")

    led = node(dts, 'label = "boot-console:green:status"')
    if not re.search(r"gpios = <0x[0-9a-f]+ 0x02 0x00 0x01>", led):
        fail(f"{dtb}: status LED is not PC0 active-low")
    if 'linux,default-trigger = "activity"' not in led:
        fail(f"{dtb}: status LED does not default to the CPU activity trigger")
    if "pinctrl-0" in led or "status-led-pc0-pins" in dts:
        fail(f"{dtb}: status LED retains redundant PC0 pinctrl ownership")

    usb = node(dts, 'dr_mode = "peripheral"')
    if 'status = "okay"' not in usb:
        fail(f"{dtb}: native USB peripheral node is disabled")

    spi = named_node(dts, "spi@1c05000")
    if 'status = "okay"' in spi:
        fail(f"{dtb}: SPI0 is enabled and conflicts with the PC0 status LED")


def check_metrics_endpoint(board: Path) -> None:
    web_root = board / "rootfs-overlay/www"
    metrics = web_root / "cgi-bin/metrics"
    files = {
        path.relative_to(web_root).as_posix()
        for path in web_root.rglob("*")
        if path.is_file()
    }
    if files != {"cgi-bin/metrics"}:
        fail(f"web root must contain only cgi-bin/metrics, found {sorted(files)}")
    if not metrics.stat().st_mode & 0o111:
        fail("Prometheus CGI endpoint is not executable")

    environment = os.environ.copy()
    environment.update({"PROC_ROOT": "/proc", "SYS_ROOT": "/sys", "ROOT_PATH": "/", "BOOT_PATH": "/"})
    started = time.monotonic()
    result = subprocess.run(
        [metrics],
        env=environment,
        capture_output=True,
        check=False,
        timeout=10,
    )
    elapsed = time.monotonic() - started
    if result.returncode:
        fail(f"Prometheus CGI exited {result.returncode}: {result.stderr.decode(errors='replace')}")
    if elapsed >= 5:
        fail(f"Prometheus CGI took {elapsed:.2f}s on the validation host")

    header = b"Content-Type: text/plain; version=0.0.4; charset=utf-8\r\n\r\n"
    if not result.stdout.startswith(header):
        fail("Prometheus CGI lacks the exact text-format content type and header terminator")
    body = result.stdout[len(header):].decode("utf-8")
    if not body.endswith("\n"):
        fail("Prometheus response body must end with a newline")
    if "<html" in body.lower() or "application/json" in body.lower():
        fail("Prometheus endpoint still contains the retired HTML or JSON interface")

    help_positions: dict[str, int] = {}
    type_positions: dict[str, int] = {}
    sample_names: set[str] = set()
    label = r'[A-Za-z_][A-Za-z0-9_]*="(?:\\.|[^"\\])*"'
    labels = rf"\{{{label}(?:,{label})*\}}"
    number = r"[-+]?(?:[0-9]+(?:\.[0-9]*)?|\.[0-9]+)(?:[eE][-+]?[0-9]+)?"
    sample_pattern = re.compile(rf"^([A-Za-z_:][A-Za-z0-9_:]*)(?:{labels})? ({number})$")

    for position, line in enumerate(body.splitlines()):
        if match := re.fullmatch(r"# HELP ([A-Za-z_:][A-Za-z0-9_:]*) .+", line):
            name = match.group(1)
            if name in help_positions:
                fail(f"duplicate HELP for {name}")
            help_positions[name] = position
        elif match := re.fullmatch(r"# TYPE ([A-Za-z_:][A-Za-z0-9_:]*) (counter|gauge)", line):
            name = match.group(1)
            if name in type_positions:
                fail(f"duplicate TYPE for {name}")
            type_positions[name] = position
        elif line.startswith("#"):
            fail(f"unsupported Prometheus comment: {line}")
        elif line:
            match = sample_pattern.fullmatch(line)
            if not match:
                fail(f"malformed Prometheus sample or non-numeric value: {line}")
            name = match.group(1)
            sample_names.add(name)
            if name not in help_positions or name not in type_positions:
                fail(f"sample {name} lacks HELP or TYPE metadata")
            if help_positions[name] > position or type_positions[name] > position:
                fail(f"sample {name} appears before its HELP/TYPE metadata")

    if set(help_positions) != set(type_positions):
        fail("Prometheus HELP and TYPE families do not match")
    required = {
        "clarks_board_info",
        "clarks_board_time_seconds",
        "clarks_board_uptime_seconds",
        "clarks_board_cpu_seconds_total",
        "clarks_board_cpu_count",
        "clarks_board_load_average",
        "clarks_board_memory_bytes",
        "clarks_board_filesystem_size_bytes",
        "clarks_board_network_receive_bytes_total",
        "clarks_board_socket_count",
        "clarks_board_tcp_segments_total",
        "clarks_board_udp_datagrams_total",
        "clarks_board_entropy_available_bits",
        "clarks_board_service_up",
        "clarks_board_usb_gadget_bound",
    }
    missing = sorted(required - sample_names)
    if missing:
        fail(f"executed Prometheus endpoint lacks required samples: {missing}")

    with tempfile.TemporaryDirectory() as directory:
        fixture_sys = Path(directory) / "sys"
        fixture_udc = fixture_sys / "kernel/config/usb_gadget/clarks-board/UDC"
        fixture_udc.parent.mkdir(parents=True)
        fixture_udc.write_text("musb-hdrc.1.auto\n")
        fixture_environment = environment | {"SYS_ROOT": str(fixture_sys)}
        fixture = subprocess.run(
            [metrics],
            env=fixture_environment,
            capture_output=True,
            check=False,
            timeout=10,
        )
        if fixture.returncode or b"clarks_board_usb_gadget_bound 1\n" not in fixture.stdout:
            fail("Prometheus CGI does not report the clarks-board configfs UDC as bound")

    path_info_environment = environment | {"PATH_INFO": "/unexpected"}
    path_info = subprocess.run(
        [metrics],
        env=path_info_environment,
        capture_output=True,
        check=False,
        timeout=10,
    )
    if path_info.returncode or not path_info.stdout.startswith(b"Status: 404 Not Found\r\n"):
        fail("Prometheus CGI does not reject an additional PATH_INFO segment with 404")
    if b"clarks_board_" in path_info.stdout:
        fail("Prometheus CGI exposes metrics on an additional PATH_INFO route")


def check_board_source(board: Path) -> None:
    boot = (board / "boot.cmd").read_text()
    image = (board / "genimage.cfg").read_text()
    inittab = (board / "rootfs-overlay/etc/inittab").read_text()
    wrapper = (board / "rootfs-overlay/usr/sbin/usb-acm-getty").read_text()
    gadget = (board / "rootfs-overlay/usr/sbin/usb-gadget-setup").read_text()
    gadget_service = (board / "rootfs-overlay/etc/init.d/S40usb-gadget").read_text()
    dhcp = (board / "rootfs-overlay/etc/udhcpd.conf").read_text()
    dropbear = (board / "rootfs-overlay/etc/init.d/S50dropbear").read_text()
    web_service = (board / "rootfs-overlay/etc/init.d/S60webui").read_text()
    metrics = (board / "rootfs-overlay/www/cgi-bin/metrics").read_text()
    post_build = (board / "post-build.sh").read_text()
    fstab = (board / "rootfs-overlay/etc/fstab").read_text()
    uboot_patch = (board / "patches/uboot/0001-suniv-licheepi-nano-name-clarks-board.patch").read_text()
    if "root=/dev/mmcblk0p2" not in boot or "rootfstype=ext4 ro" not in boot:
        fail("boot.cmd must select the second, read-only ext4 SD partition")
    if not re.search(r"partition rootfs\s*\{[^}]*partition-type = 0x83[^}]*rootfs\.ext4", image, re.S):
        fail("genimage.cfg root partition does not match bootargs")
    if "ttyS0::respawn:/sbin/getty -L ttyS0 115200" not in inittab:
        fail("UART0 getty is missing or has the wrong baud rate")
    if "ttyGS0::respawn:/usr/sbin/usb-acm-getty" not in inittab:
        fail("USB serial getty wrapper is not supervised by init")
    if "while [ ! -c /dev/ttyGS0 ]" not in wrapper or wrapper.count("sleep 2") < 2:
        fail("USB serial getty wrapper does not rate-limit a late gadget TTY")
    for required in (
        'functions/acm.usb0',
        'functions/ecm.usb0',
        'echo 0x80 > "$config/bmAttributes"',
        'echo 500 > "$config/MaxPower"',
        '192.168.7.2 netmask 255.255.255.0',
    ):
        if required not in gadget:
            fail(f"composite USB gadget setup lacks {required!r}")
    if 'while [ ! -d /sys/class/net/usb0 ]' not in gadget or 'while :' not in gadget:
        fail("USB gadget setup does not tolerate delayed UDC/network creation")
    if 'bound_udc=$(cat "$gadget/UDC" 2>/dev/null || true)' not in gadget or '[ -z "$bound_udc" ]' not in gadget:
        fail("USB gadget setup does not check the UDC attribute content before binding")
    if 'usb-gadget-setup.pid' not in gadget_service or '>/dev/console 2>&1 &' not in gadget_service:
        fail("USB gadget setup is not started asynchronously with a runtime PID file")
    if 'bound_udc=$(cat "$udc_file" 2>/dev/null || true)' not in gadget_service or '[ -n "$bound_udc" ]' not in gadget_service:
        fail("USB gadget stop does not check the UDC attribute content before unbinding")
    for required in ("start 192.168.7.10", "end 192.168.7.20", "interface usb0", "option subnet 255.255.255.0"):
        if required not in dhcp:
            fail(f"USB DHCP configuration lacks {required!r}")
    if re.search(r"^\s*option\s+(?:router|dns)\b", dhcp, re.M):
        fail("USB DHCP must not replace the attached host's default route or DNS")
    if 'persistent_dir=/boot/dropbear' not in dropbear or 'dropbear -B ' not in dropbear:
        fail("Dropbear does not persist its host key or allow the documented blank development password")
    if 'httpd -p 80 -h /www' not in web_service:
        fail("BusyBox HTTPD service does not serve /www on port 80")
    for required in ("Content-Type: text/plain; version=0.0.4; charset=utf-8", "clk_tck=100", "$6 * 512", "$10 * 512"):
        if required not in metrics:
            fail(f"Prometheus CGI lacks {required!r}")
    if 'find "$target_dir/www" -type f ! -path "$metrics" -delete' not in post_build:
        fail("post-build script does not enforce the one-endpoint web root")
    if not re.search(r"^/dev/mmcblk0p1\s+/boot\s+vfat\s+[^\n]*\brw\b", fstab, re.M):
        fail("FAT boot partition is not mounted read/write for the persistent SSH host key")
    if '-\tmodel = "Lichee Pi Nano";' not in uboot_patch or '+\tmodel = "Clark\'s Board";' not in uboot_patch:
        fail("U-Boot board-name patch does not set the model to Clark's Board")
    check_metrics_endpoint(board)


def same_region(image: Path, offset: int, payload: Path) -> bool:
    with image.open("rb") as image_file, payload.open("rb") as payload_file:
        image_file.seek(offset)
        while chunk := payload_file.read(1024 * 1024):
            if image_file.read(len(chunk)) != chunk:
                return False
    return True


def check_image(images: Path) -> None:
    disk = images / "sdcard.img"
    with disk.open("rb") as stream:
        mbr = stream.read(512)
    if len(mbr) != 512 or mbr[510:512] != b"\x55\xaa":
        fail(f"{disk}: missing MBR signature")
    partitions: list[tuple[int, int, int]] = []
    for index in range(4):
        entry = mbr[446 + 16 * index : 462 + 16 * index]
        kind = entry[4]
        start, sectors = struct.unpack_from("<II", entry, 8)
        if kind or start or sectors:
            partitions.append((kind, start, sectors))
    if len(partitions) != 2 or [part[0] for part in partitions] != [0x0C, 0x83]:
        fail(f"{disk}: expected FAT32-LBA boot then Linux root partitions, got {partitions}")
    boot_part, root_part = partitions
    if boot_part[2] * 512 != 16 * 1024 * 1024:
        fail(f"{disk}: boot partition is not exactly 16 MiB")
    if root_part[1] != boot_part[1] + boot_part[2]:
        fail(f"{disk}: root partition does not immediately follow boot partition")
    if not same_region(disk, boot_part[1] * 512, images / "boot.vfat"):
        fail(f"{disk}: boot partition bytes differ from boot.vfat")
    if not same_region(disk, root_part[1] * 512, images / "rootfs.ext4"):
        fail(f"{disk}: root partition bytes differ from rootfs.ext4")
    uboot = images / "u-boot-sunxi-with-spl.bin"
    if uboot.stat().st_size > 1016 * 1024:
        fail(f"{uboot}: SPL/U-Boot exceeds its 1016 KiB raw region")
    if not same_region(disk, 8 * 1024, uboot):
        fail(f"{disk}: raw boot area differs from {uboot.name}")
    boot_payload = sum((images / name).stat().st_size for name in ("zImage", "linux.dtb", "boot.scr"))
    if boot_payload > 15 * 1024 * 1024:
        fail("boot files leave less than 1 MiB for FAT metadata and allocation overhead")


def check_rootfs_web(output: Path, board: Path) -> None:
    debugfs = output / "host/sbin/debugfs"
    if not debugfs.is_file():
        fail(f"{debugfs}: required to inspect the generated root filesystem")
    with tempfile.TemporaryDirectory() as directory:
        destination = Path(directory) / "root"
        destination.mkdir()
        extracted = destination / "www"
        result = subprocess.run(
            [debugfs, "-R", f"rdump /www {destination}", output / "images/rootfs.ext4"],
            capture_output=True,
            text=True,
            check=False,
        )
        if result.returncode:
            fail(f"debugfs could not extract /www from rootfs.ext4: {result.stderr}")
        files = {
            path.relative_to(extracted).as_posix()
            for path in extracted.rglob("*")
            if path.is_file()
        }
        if files != {"cgi-bin/metrics"}:
            fail(f"rootfs.ext4 web root contains unexpected files: {sorted(files)}")
        image_metrics = extracted / "cgi-bin/metrics"
        source_metrics = board / "rootfs-overlay/www/cgi-bin/metrics"
        if image_metrics.read_bytes() != source_metrics.read_bytes():
            fail("rootfs.ext4 Prometheus CGI differs from the board overlay source")
        if not image_metrics.stat().st_mode & 0o111:
            fail("rootfs.ext4 Prometheus CGI endpoint is not executable")


def overlaps(first: tuple[int, int], second: tuple[int, int]) -> bool:
    return first[0] < second[1] and second[0] < first[1]


def check_memory_layout(output: Path, board: Path) -> None:
    boot = (board / "boot.cmd").read_text()
    dtb_match = re.search(r"load mmc 0:1 (0x[0-9a-fA-F]+) linux\.dtb", boot)
    kernel_match = re.search(r"load mmc 0:1 (0x[0-9a-fA-F]+) zImage", boot)
    if not dtb_match or not kernel_match:
        fail("boot.cmd does not expose fixed zImage and DTB load addresses")
    dtb_start = int(dtb_match.group(1), 16)
    zimage_start = int(kernel_match.group(1), 16)
    images = output / "images"
    dtb_range = (dtb_start, dtb_start + (images / "linux.dtb").stat().st_size)
    zimage_range = (zimage_start, zimage_start + (images / "zImage").stat().st_size)
    ram = (0x80000000, 0x84000000)
    for name, region in (("zImage", zimage_range), ("DTB", dtb_range)):
        if region[0] < ram[0] or region[1] > ram[1]:
            fail(f"{name} load range {region[0]:#x}-{region[1]:#x} is outside 64 MiB RAM")

    linux_dir = one_dir(
        [path for path in (output / "build").glob("linux-*") if not path.name.startswith("linux-headers-")],
        "Linux build directory",
    )
    nm = one(
        [path for path in (output / "host/bin").glob("*buildroot-linux*-nm") if not path.name.endswith("gcc-nm")],
        "target nm tool",
    )
    result = subprocess.run([nm, "-n", linux_dir / "vmlinux"], capture_output=True, text=True, check=False)
    if result.returncode:
        fail(f"cannot inspect vmlinux symbols: {result.stderr}")
    symbols = {
        match.group(2): int(match.group(1), 16)
        for line in result.stdout.splitlines()
        if (match := re.fullmatch(r"([0-9a-fA-F]+)\s+\w\s+(\S+)", line))
    }
    if "_text" not in symbols or "_end" not in symbols:
        fail("vmlinux lacks _text/_end symbols needed for load-overlap validation")
    decompressed = (0x80008000, 0x80008000 + symbols["_end"] - symbols["_text"])
    if decompressed[1] > ram[1]:
        fail(f"decompressed kernel ends beyond RAM at {decompressed[1]:#x}")
    if overlaps(dtb_range, decompressed):
        fail(
            f"DTB {dtb_range[0]:#x}-{dtb_range[1]:#x} overlaps decompressed kernel "
            f"{decompressed[0]:#x}-{decompressed[1]:#x}"
        )
    if overlaps(dtb_range, zimage_range):
        fail(
            f"DTB {dtb_range[0]:#x}-{dtb_range[1]:#x} overlaps compressed zImage "
            f"{zimage_range[0]:#x}-{zimage_range[1]:#x}"
        )
    relocation_headroom = 1024 * 1024
    relocation_end = decompressed[1] + (images / "zImage").stat().st_size + relocation_headroom
    if dtb_start < relocation_end:
        fail(
            f"DTB at {dtb_start:#x} leaves insufficient decompressor relocation room; "
            f"need at least {relocation_end:#x} for kernel + compressed zImage + 1 MiB workspace"
        )
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

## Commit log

2026-09-19 Initial Clark's Board hardware and firmware
    [DigiKey-order.csv, LCSC-order.csv, bom.csv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]
2026-09-19 Replace status page with Prometheus metrics
    [validate_artifacts.py]
